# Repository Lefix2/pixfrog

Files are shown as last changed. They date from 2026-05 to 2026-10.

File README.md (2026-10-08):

# pixfrog

> High-performance ArtNet / sACN → LED driver for ESP32-P4. 8 channels × 2 lines (DATA + CLOCK), supporting 1-wire protocols (WS2815, WS2812B, SK6812…), clocked protocols (APA102, SK9822, LPD8806). DMX512 output lives in the DMX node firmware (a separate project forked from this one).

## Features

- ESP32-P4 dual-core RISC-V at 360 MHz, 32 MB octal PSRAM
- 10/100M Ethernet via external PHY (IP101GRI); DHCP or static IP, and without a DHCP server a configurable fallback: link-local 169.254.x.x (default) or Art-Net 2.x.x.x/8 from the MAC
- 8 parallel LED channels on a 16-bit bus — **PARLIO TX loop DMA** (default) or legacy LCD_CAM backend
- **ArtNet 4** receiver: ArtDmx/ArtPoll/ArtSync, remote config via ArtAddress + ArtIpProg, scene triggers via ArtTrigger, ArtTimeCode sync (up to 48 universes)
- **sACN (E1.31)** receiver (opt-in): multicast joins per configured universe, per-universe priority, stream-terminate handling
- **2-source merge** (HTP/LTP) when ArtNet and sACN feed the same universe
- **FSEQ player**: `.fseq` sequences (xLights/FPP, zstd-compressed) from microSD with hot-plug, uploaded over the web UI, played once, in a loop or as a **playlist** (per-file repeats, loop, autostart at boot), free-running or slaved to ArtTimeCode / **FPP MultiSync**
- **Effect bank and standalone scenes**: up to 31 reusable effects — 11 generators (solid + strobe, chase, rainbow, blobs, gradient, fade, twinkle, fire, scanner, wave, stripes), up to 4 colours each, a **dimmer phaser** (sine, cosine, ramps, triangle, PWM, bump; rate, phase spread, width, floor), a dimmer invert and pixel-level **Block / Groups / Wings** — and up to 30 scenes (create / rename / reorder / delete), each a memory of parts: "this effect on these outputs"; playable at boot, from the desk (ArtTrigger), or any UI
- **Per-line tuning**: gamma, white balance, grouping, invert, up to 8 dead-pixel gaps anywhere on the line (sacrificial pixel, repeater chip) and up to 32 fixtures (bars, tubes) that scenes can play per fixture, chained or mirrored; any refresh rate 20–120 Hz with a non-destructive pixel budget
- **Show control**: grand master, blackout and strobe per output group; scene **zones** (several scenes at once on different outputs) with **crossfades**; a composable **DMX control universe** (master 16-bit, blackout, strobe, scene, effect of the bank, speed, param, generator, colours, phaser, Block / Groups / Wings, fade, FSEQ) editable from the web, TFT or UART, with an exportable **OFL fixture profile** for the desk; up to 8 composable **fixture DMX profiles** (dimmer, colours, shutter, effect of the bank, speed, phaser, Block / Groups / Wings — presets from 3 to 16 channels), each with its OFL export; ArtTrigger KeyMacro blackout
- **Pixels, fixtures, or both** per output — two switches, each on its own address range: **pixel mapping** (every LED its DMX channels) and **fixture control**, each fixture driven like a conventional luminaire through its DMX profile (for example R, G, B, effect, speed, shutter) — a handful of channels per fixture instead of 3–4 per pixel. Both at once: a media server sends the pixels, the desk dims, shutters or replaces them with an effect of the bank, fixture by fixture. Auto-patch lays out the pixels, then the fixtures, then the control universe; the web shows the patch sheet
- **Signal-loss failsafe** per channel: hold / blackout / solid colour / scene after a configurable timeout
- **Per-channel gamma + white balance**, baked into encode-time LUTs (validated bit-exact on a logic analyzer)
- Local UI: **NV3007 428×142 colour bar TFT** (SPI, 2.79") with a live status dashboard (per-channel activity, link/services state) and natively rasterised anti-aliased fonts; Adafruit seesaw rotary encoder (4-wire I2C, time-polled); pixel-count live preview and strip-identify blink for commissioning. Two other panels are supported as build-time alternates — see [Display backend](#display-backend)
- **Web UI** (opt-in, port 80): full configuration SPA + REST API, live status and per-output pixel preview pushed over a WebSocket (`/api/status` polling as fallback), **OTA firmware update** (A/B slots with boot-failure rollback), config **backup/restore** as JSON, crash **coredump download**, mDNS while enabled (`pixfrog-xxxx.local` per box; `pixfrog.local` opens the box; with several, tabs at the top switch between an overview of every box and each box's own UI), optional HTTP Basic auth on every mutation (no TLS: the password crosses the network in clear)
- **UART control console**: every config field, telemetry, DMX injection, buffer readback (`tools/uartctl.sh`)
- Both UIs are laid out by job, in the order a rig is built — each screen only refers to what sits above it: the **dashboard**, then **Rig** (outputs and their fixtures, groups), **Looks** (effects, scenes), **DMX** (the three blocks of the patch sheet — control universe, profiles and fixture patch, pixel patch — and auto-patch last), **Playback** (sequences, automations) and **Settings** (network with the DMX reception — sACN, FPP, merge —, system, maintenance with the telemetry and logs). The device menu keeps its live Show page first.
- All configuration **persisted** in NVS with forward migration; network surfaces beyond ArtNet are **strictly opt-in** (no socket while disabled)

## Target hardware

The default board is the **Waveshare ESP32-P4 Module DEV-KIT**.
Pinout, schematic, datasheet, and PHY wiring are documented by Waveshare:

→ <https://docs.waveshare.com/ESP32-P4-Module-DEV-KIT/Resources-And-Documents>

Any other ESP32-P4 board with octal PSRAM and an MII/RMII PHY works; just clone `boards/esp32_p4_devkit.h` and adjust the GPIO map.

## Build & flash

ESP-IDF v5.5+ with ESP32-P4 support. `sdkconfig.defaults` already pins the
target, so no `set-target` is needed. Both `led_output` backends (PARLIO TX
default, legacy LCD_CAM RGB panel) need drivers that only ship from v5.5.

```bash
idf.py build                              # default: NV3007 bar panel
idf.py -p /dev/ttyACM0 flash              # write it to the board
idf.py -p /dev/ttyACM0 monitor            # boot log (Ctrl-] to leave)
idf.py menuconfig                         # optional — sdkconfig.defaults is sane
```

Without a local IDF, build and flash in the official container:

```bash
docker run --rm -v "$PWD":/project -w /project -u "$(id -u):$(id -g)" -e HOME=/tmp \
    espressif/idf:v5.5 idf.py build
docker run --rm --device /dev/ttyACM0 -v "$PWD":/project -w /project \
    espressif/idf:v5.5 idf.py -p /dev/ttyACM0 flash
```

> `sdkconfig` is generated and git-ignored. It is only seeded from
> `sdkconfig.defaults` **when it does not exist**, so after changing the defaults
> or switching variant, `rm -f sdkconfig` first — otherwise the old selection
> silently survives.

### Display backend

The default is the **NV3007 428×142 bar panel** the 1U rack ships with — a plain
`idf.py build` targets it, and the boot log confirms with
`TFT: NV3007 428x142 ready (landscape)`.

Two alternates are supported for other builds of the hardware. Each needs its own
build directory and sdkconfig, or the overlay is silently ignored:

| Panel | Overlay | Build |
|---|---|---|
| **NV3007** 428×142 SPI bar (2.79") | *(default)* | `idf.py build` |
| ST7789V / ILI9341 320×240 SPI | `sdkconfig.ci.st7789` | `idf.py -B build.st7789 -D SDKCONFIG=build.st7789/sdkconfig -D SDKCONFIG_DEFAULTS="sdkconfig.defaults;sdkconfig.ci.st7789" build` |
| SSD1306 128×64 I²C OLED | `sdkconfig.ci.oled` | `idf.py -B build.oled -D SDKCONFIG=build.oled/sdkconfig -D SDKCONFIG_DEFAULTS="sdkconfig.defaults;sdkconfig.ci.oled" build` |

Flash a variant from its own directory, e.g. `idf.py -B build.oled -p /dev/ttyACM0 flash`.
`PIXFROG_NV3007_ROT180` flips the bar panel; it is **on by default** (the panel is
mounted upside down in the 1U rack).

TFT SPI GPIOs live in `boards/esp32_p4_devkit.h` — CLK=0, MOSI=6, CS=20, DC=21,
RST=27 on the shield's J13 header, backlight on GPIO 36, SPI2 at 20 MHz. See
[docs/HARDWARE.md §5](docs/HARDWARE.md).

## Host unit tests

Seven pure-C++ test suites that run anywhere a C++17 compiler is installed (no IDF required):

```bash
# LED encoders + timings + encode throughput
cd components/led_protocols/test && cmake -B build && cmake --build build && ./build/test_led_protocols

# DMX manager logic (sizing, capacity, multi-universe decoder)
cd components/dmx_manager/test  && cmake -B build && cmake --build build && ./build/test_dmx_logic

# ArtNet parser (header, ArtDmx/Nzs/Address/IpProg, filter, replies)
cd components/artnet/test       && cmake -B build && cmake --build build && ./build/test_artnet_parser

# sACN parser (root/framing/DMP, sync, per-universe priority gate)
cd components/sacn/test         && cmake -B build && cmake --build build && ./build/test_sacn_parser

# config store (struct layout, NVS forward migration)
cd components/config_store/test && cmake -B build && cmake --build build && ./build/test_config_store

# FSEQ parser (header, sparse ranges, zstd frames)
cd components/fseq_player/test  && cmake -B build && cmake --build build && ./build/test_fseq_parser

# FPP MultiSync parser
cd components/fpp_sync/test     && cmake -B build && cmake --build build && ./build/test_fpp_sync_parser
```

There is also an SDL2 **UI emulator** (`tools/emulator`) that compiles the real
menu FSM for the host and drives it headlessly (`tools/emulator/smoke.sh`), and
a replayable **hardware regression suite** (`tools/hw_validate`) that proves
every feature on the real board after a flash.

## CI

`.github/workflows/ci.yml` runs on pushes to `main` and on pull requests
targeting `main`:

- the seven host suites above
- the SDL2 emulator build + headless menu-FSM smoke test
- `idf.py build` for `esp32p4` × **three display variants** (nv3007 default, st7789, oled) in the `espressif/idf:v5.5` container
- `clang-format --dry-run` against `.clang-format` on every tracked C/C++ file

`./tools/ci-local.sh` replays all of it locally and must be green before any push.

## Releases & browser flashing

Firmware and the website ship on independent cadences:

- `.github/workflows/release.yml` runs on every `v*` tag (e.g. `git tag v0.1.0
  && git push origin v0.1.0`): it builds the firmware and publishes a GitHub
  Release with `pixfrog-merged.bin` (flash at `0x0`) plus the individual
  bootloader / partition-table / app parts.
- `.github/workflows/pages.yml` runs on every push to `main` that touches the
  site (`.github/pages/**`, `docs/**`): it deploys the
  [esp-web-tools](https://esphome.github.io/esp-web-tools/) flasher and docs to
  GitHub Pages so the board can be flashed from desktop Chrome/Edge over USB —
  no toolchain required.

The flasher's `manifest.json` pins the **latest** Release asset
(`releases/latest/download/pixfrog-merged.bin`), so the site always serves the
newest firmware without a redeploy — a copy or CSS edit goes live on a plain
push to `main`, with no firmware version bump.

One-time setup: enable **Settings → Pages → Source: GitHub Actions** (the
workflow also attempts to enable it automatically).

## Documentation

Rendered online (with the browser flasher) at **<https://lefix2.github.io/pixfrog/>**:

- [docs/ARCHITECTURE.md](docs/ARCHITECTURE.md) — task topology, frame lifecycle, memory budget
- [docs/HARDWARE.md](docs/HARDWARE.md) — pinout, PHY, level shifters, encoder + display wiring
- [docs/PROTOCOLS.md](docs/PROTOCOLS.md) — per-protocol timings, PCLK formula, DMA encoding
- [docs/SHOW_CONTROL.md](docs/SHOW_CONTROL.md) — grand master / blackout / strobe, scene zones and crossfades, the DMX control universe and its fixture profile
- [AGENT.md](AGENT.md) — conventions, module map, hard rules (humans and agents)
- [TODO.md](TODO.md) — the living roadmap; features land only from this list

## Hardware companion

Two products live under `hardware/`, each with a board and a mechanical design.

**pixfrog_rack** — the controller end:

- *board* — **[pixfrog shield](hardware/pixfrog_shield/README.md)**: KiCad project
  + JLCPCB production files. 2× 74HCT245 re-drive the 16 bus lines at 5 V,
  DIP-selectable series termination, one TVS clamp per output, 8× JST-XH to the
  panel connectors.
- *meca* — **[1U enclosure](hardware/pixfrog_rack/README.md)**: Fusion 360 design
  of the chassis, front-panel UI holder, devkit + shield stack, XLR outputs and
  5 V supply.

**pixfrog_satellite** — the far end of a long run:

- *board* — **[satellite](hardware/pixfrog_satellite/README.md)**: Schmitt buffer
  re-squares one channel, local regulator injects strip power.
- *meca* — **WIP**, no enclosure design yet.

Every channel leaves on an XLR: **1 = GND, 2 = DATA+ (DATA), 3 = DATA− (CLOCK),
4 = VCC** on the XLR4 variant — DMX-compatible by design, see
[docs/HARDWARE.md §8](docs/HARDWARE.md).

## Status

Validated on silicon (Waveshare ESP32-P4 Module DEV-KIT): WS2815 NRZ timing,
gamma LUTs and frame content verified bit-exact on a Saleae logic analyzer;
ArtNet, sACN (unicast), OTA, auth, failsafe, scenes, backup/restore and FSEQ
playback (upload, seek, ArtTimeCode, FPP MultiSync) exercised end-to-end on
the board — captured as the replayable suite in `tools/hw_validate`.
Remaining field items live in [TODO.md](TODO.md).

## License

pixfrog is released under the [MIT License](LICENSE) — © 2026 Lefix2.

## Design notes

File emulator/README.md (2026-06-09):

# pixfrog UI emulator

Runs the device's **real** UI code (`menu.cpp`, `canvas_tft.cpp`, `splash.cpp`,
`font_5x8.cpp`) on a PC against an SDL2 framebuffer instead of the ST7789 TFT.
Lets you test the interface before flashing, and gives an AI agent a programmatic
way to drive and observe the UI.

## How it works

The UI only touches hardware through one function — `tft_draw_bitmap()`. The
emulator reimplements that (`src/tft_sdl.cpp`) over an in-RAM 320×240 RGB565
framebuffer, replaces the I2C rotary encoder with a host event queue
(`src/encoder_host.cpp`), and stubs the neighbour components the menu reads
(`config_store`, `dmx_manager`, `lcd_cam_output`) with in-RAM versions that
mirror the device defaults. Everything else is the device's own source,
compiled with `-DCONFIG_PIXFROG_DISPLAY_TFT`.

The only change to shared device code is `det::menu_debug_state()` in `menu.cpp`,
guarded by `#ifdef PIXFROG_EMULATOR` (invisible to the firmware build).

## Build & run

```sh
sudo apt install libsdl2-dev
cd emulator && cmake -B build && cmake --build build

./build/pixfrog_emu               # interactive window (960×720, 3× zoom)
./build/pixfrog_emu --headless    # no window, piloted via stdin (agent/CI)
```

### Keyboard (interactive)

| Key | Encoder event |
|---|---|
| ↑ / ← / wheel-up | RotateLeft  (cursor up) |
| ↓ / → / wheel-down | RotateRight (cursor down) |
| Enter / Space | Click |

## Agent / stdin protocol

One command per line on stdin; replies on stdout. Headless skips the splash and
starts at HOME for deterministic runs.

| Command | Effect |
|---|---|
| `left` / `right` | rotate the encoder |
| `click` | press the encoder |
| `shot <path>` | save the 320×240 framebuffer as BMP → `ok shot …`  |
| `state` | print `{"screen":..,"cursor":..,"channel":..}` |
| `set ip a.b.c.d` | set the displayed IP (HOME) |
| `set link up/down` | set link state (HOME) |
| `set fps <n>` | inject a fake FPS counter (HOME) |
| `set active <ch>`  | mark channel `ch` (0–7) active (HOME dot) |
| `quit` | exit |

### Example

```sh
printf 'click\nright\nright\nclick\nshot /tmp/chan.bmp\nstate\nquit\n' \
  | ./build/pixfrog_emu --headless
# → ok shot /tmp/chan.bmp
#   {"screen":"ChannelMenu","cursor":0,"channel":0}
```

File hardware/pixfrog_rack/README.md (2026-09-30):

# pixfrog rack — 1U enclosure

Fusion 360 design for the 1U rack that houses the controller: the
ESP32-P4 Module DEV-KIT plus the [signal shield](../pixfrog_shield/README.md),
the front-panel UI, and the mains-to-5 V supply.

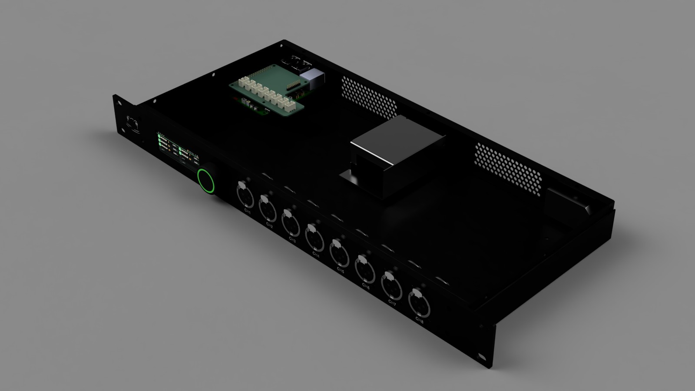
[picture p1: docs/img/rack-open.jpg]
pixfrog rack, open


`pixfrog_rack.f3z` is a Fusion archive (`.f3z`) — the assembly and every linked
component in one file. Open it with **File → Open** in Fusion 360; it unpacks
into a project. Exported at design version 40.

## What's in the assembly

| Component | Role |
|---|---|
| `rack_1U_200_pixfrog` | The 1U chassis itself, 200 mm deep |
| `assembly` | Top-level assembly holding everything below |
| `ESP32-P4-Module-DEV-KIT_20250427` | Waveshare devkit, as the manufacturer's model |
| `shield_v1` | The LED bus shield that plugs onto the devkit's J1 |
| `UI_holder` | Front-panel bracket for the display and encoder |
| `écran_tft_2.79` | NV3007 2.79" bar panel (428×142) |
| `adafruit_seesaw` | Rotary encoder breakout |
| `knob` | Encoder knob |
| `XLR Connector PCB Mount 3 pole Female, NC3FD-V` | Neutrik XLR, DMX-style output |
| `powerplug` | Mains inlet |
| `S-15-5 power` | 5 V / 15 W enclosed PSU |
| `captive_CFBSOAM3-6`, `captive_CFBSOAM3-10` | Captive panel screws, M3 |

## Front-panel outputs

The eight channels reach the front panel on XLR connectors, wired from the
shield's JST-XH outputs. The pin order is the project-wide convention
([`docs/HARDWARE.md`](../../docs/HARDWARE.md) §8):

| Pin | Signal | Carries |
|----:|---|---|
| 1 | GND | signal + power return |
| 2 | DATA+ | DATA (NRZ and clocked strips); DATA+ under the DMX node firmware |
| 3 | DATA− | CLOCK (clocked strips), unused on WS281x; DATA− under the DMX node firmware |
| 4 | VCC | strip supply — XLR4 shells only |

Pins 1-3 match the DMX512 standard pinout, so a plain 3-pin DMX cable carries a
pixfrog channel, and the DMX node firmware drives a fixture directly. The XLR4 shell
adds strip power on pin 4; it cannot mate with a 3-pin one, which is what keeps
powered runs and signal-only runs apart.

The pin assignments the UI and shield depend on are in
[`boards/esp32_p4_devkit.h`](../../boards/esp32_p4_devkit.h) — the single source
of truth. Panel geometry for the display is in
[`docs/HARDWARE.md`](../../docs/HARDWARE.md) §5.

## Note on the file

A `.f3z` is an opaque binary (~27 MB), and git would otherwise store a fresh
copy of it per revision — no delta applies to a compressed archive. `*.f3z` is
therefore tracked with **Git LFS** (see `.gitattributes` at the repo root): the
commit holds a ~130-byte pointer and the payload lives in LFS storage.

You need `git lfs` installed to get the real file. Without it a clone silently
yields the pointer text instead, and Fusion will simply report a corrupt
archive:

```bash
git lfs install     # once per machine
git lfs pull        # if you cloned before installing it
```

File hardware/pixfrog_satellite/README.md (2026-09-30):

# pixfrog satellite — LED signal repeater + power injection

The **board** half of pixfrog_satellite; its mechanical design (enclosure) is
**WIP** — the board mounts bare for now, H1/H2 tying its GND to the chassis or
heatsink that carries it.

KiCad 10 project for the remote node that sits at the **far end of a long LED
cable run**. The controller (or `pixfrog_shield`) sends one channel's two signal
lines down the cable; over distance the edges degrade and the strip voltage
sags. The satellite **re-squares the signal** with a Schmitt-trigger buffer and
**injects local strip power**, so the LEDs see clean data and full voltage
regardless of run length.

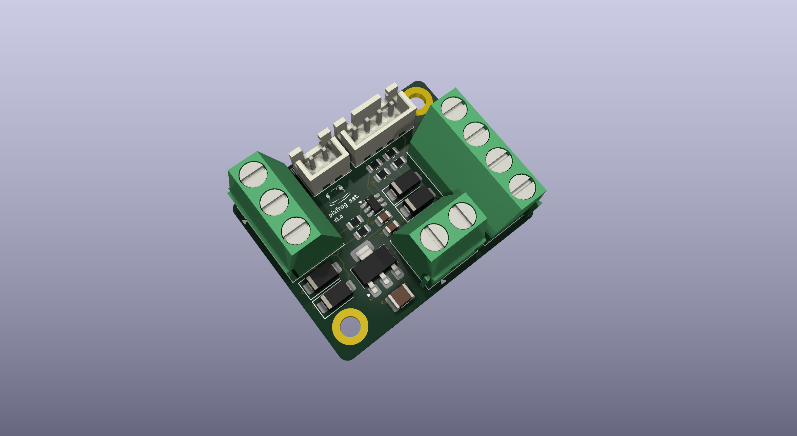
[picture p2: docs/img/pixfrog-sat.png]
pixfrog satellite


It repeats **one pixfrog channel** = its two bus lines (`Data1`, `Data2`). What
they carry follows the protocol set on the controller:

- **WS281x (NRZ)** — `Data1` = DATA (`Data2` unused),
- **clocked (APA102 / SK9822 / LPD8806)** — `Data1` = DATA, `Data2` = CLOCK,
- **DMX512** (DMX node firmware) — `Data1`/`Data2` = the differential pair.

Two voltage builds exist — **12 V** (WS2815-class) and **24 V** — chosen to match
the strip supply on `VCC`; the on-board LDO derives 5 V for the buffer from either.

## What it does

| Block | Parts | Role |
|---|---|---|
| Signal repeater | U1 — 74LVC2G17 (SC-74-6) | Dual non-inverting **Schmitt-trigger** buffer, powered at +5 V. Re-squares both lines (`Data1`, `Data2`) so the strip is driven by fresh 5 V-logic edges, not the degraded cable signal |
| Input series + clamp | R1, R2 (33 Ω) · D1, D2 (TVS) | 33 Ω in series into each buffer input; one 5 V bidirectional TVS per input line to GND |
| Output series, impedance select | R5, R6 (249 Ω) · R3, R4 (39 Ω) behind J4 | 249 Ω permanently in line on each output (WS281x-style). Fitting a jumper/switch on J4 (1‑2 and/or 3‑4) parallels 39 Ω → ≈34 Ω for low-impedance drive of long lines — same trick as the shield's SW1 |
| Output clamp | D3, D4 — TVS | One 5 V bidirectional TVS per output line to GND |
| Local 5 V | U2 — LD1117S50 (SOT-223) · C1 100 n, C2 10 µF (out) · C3 10 µF (in) | Linear 5 V from `VCC` (12 V or 24 V) — the logic rail for the buffer (`+5V` net, internal only) |
| Power pass-through / fan-out | J1 in → J2 + J5 | The strip supply (`VCC`) enters on J1 and is passed straight to the strip output (J2) and the J5 fan-out, GND common throughout |
| Mounting | H1, H2 — GND pads | Tie the board GND to the chassis/heatsink |

## Connectors

| Ref | Type | Pins | Use |
|---|---|---|---|
| J1 | 2-pin screw (Phoenix MKDS 5.08) | `VCC`, `GND` | Strip power **in** (12 V or 24 V per build) |
| J3 | 3-pin screw | `GND`, `Data1_in`, `Data2_in` | Signal **in** from the controller / shield channel |
| J2 | 4-pin screw | `VCC`, `Data1_out`, `Data2_out`, `GND` | **Out** to the LED strip — regenerated data + injected power |
| J5 | 2-pin JST-XH (`fan_out`) | `VCC`, `GND` | Power fan-out — chain to the strip's other end or a downstream node |
| J4 | 4-pin JST-XH | pre-/post-249 Ω taps | Optional impedance-select header (see table above); leave open for 249 Ω only |

Screw terminals, not panel connectors — the XLR lives at the cable end. The
incoming cable follows the project-wide pin order
([`docs/HARDWARE.md`](../../docs/HARDWARE.md) §8): **1 = GND, 2 = DATA+ (DATA),
3 = DATA− (CLOCK), 4 = VCC**, so XLR pins 1/2/3 land on J3's `GND` /
`Data1_in` / `Data2_in`. An XLR4 run brings strip power on pin 4 to J1 `VCC`;
with an XLR3 run the strip supply is local and J1 is fed from the node's own
PSU.

## Signal + power flow (per line)

```
Data_in (J3) ─[TVS]─ 33Ω ─► 74LVC2G17 (@ +5V) ─► 249Ω ─[TVS]─ Data_out (J2)
                                                    │
                                              J4 ── 39Ω  (jumper ⇒ ≈34Ω)

VCC (J1, 12/24V) ─┬─► LD1117S50 ─► +5V (buffer)
                  └─► J2 (strip) + J5 (fan-out)
```

## Production

`production/` is JLCPCB-ready, generated by the KiCad Fabrication Toolkit
(options in `fabrication-toolkit-options.json`):

- `pixfrog_satellite.zip` — gerbers + drill
- `bom.csv` / `positions.csv` — SMT assembly with LCSC part numbers
- `netlist.ipc`, `designators.csv`

## Not committed

Working artifacts stay out of the repo: `.history/`, KiCad backups, the
`3d/` model sources and the STEP export (regenerate from the PCB via
File → Export → STEP), and the render source images (the render itself
lives in `docs/img/pixfrog-sat.png`).

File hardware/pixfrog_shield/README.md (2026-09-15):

# pixfrog shield — LED bus signal conditioning

The **board** half of pixfrog_rack; the *meca* half is the
[1U enclosure](../pixfrog_rack/README.md) it stacks into.

KiCad 10 project for the signal-adaptation shield that plugs onto the
ESP32-P4 Module DEV-KIT's 2×20 header (J1). It closes the gap identified in
the TODO ("output buffers"): the devkit drives the LED bus straight from
3.3 V GPIOs, which is marginal for 12 V strips (WS2815) over real cable runs
and leaves the SoC exposed to field wiring.

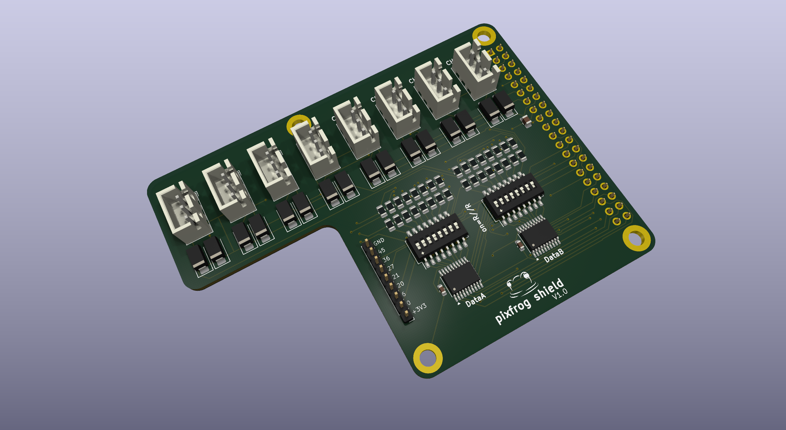
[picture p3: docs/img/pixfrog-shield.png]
pixfrog shield


## What it does

| Block | Parts | Role |
|---|---|---|
| Level shift | U1, U2 — 2× 74HCT245 (TSSOP-20) | TTL-threshold inputs driven cleanly by 3.3 V; outputs re-drive all 16 bus lines (8× DATA via U1, 8× CLOCK via U2) at 5 V — double the noise margin at the strip |
| Series termination, DATA | R1–R8 (249 Ω) + R9–R16 (39 Ω) behind SW1 | 249 Ω permanently in line (WS281x-style input resistor); closing the channel's DIP on SW1 parallels 39 Ω → ≈34 Ω for low-impedance drive of long lines ("33Ω/249Ω" on the silkscreen) |
| Series termination, CLOCK | R17–R24 (33 Ω) + R25–R32 (39 Ω) behind SW2 | 33 Ω base for clocked strips (APA102/SK9822/LPD8806); SW2 parallels 39 Ω → ≈18 Ω |
| Transient clamp | D1–D16 — 16× 5 V TVS (SMA) | One clamp to GND per output; a zap on the field wiring sacrifices a €0.10 diode, not the P4 |
| Outputs | J2–J9 — 8× JST-XH 3 pins | Per channel: 1 = DATA, 2 = CLOCK, 3 = GND (strip power stays on the strip PSU; signal ground must travel with the data pair) |
| Aux breakout | J13 — 1×9, 2 mm | 3V3, spare GPIOs 0/6/20/21/27/36/45, GND |

The channel→GPIO mapping mirrors `boards/esp32_p4_devkit.h` exactly
(CH1 DATA=GPIO2/CLK=GPIO3 … CH8 DATA=GPIO53/CLK=GPIO54).

J2–J9 are internal: the loom takes each one to a panel XLR, whose pin order is
**not** the JST's ([`docs/HARDWARE.md`](../../docs/HARDWARE.md) §8) —
JST 1 (DATA) → XLR 2, JST 2 (CLOCK) → XLR 3, JST 3 (GND) → XLR 1. Pin 4 of an
XLR4 panel carries strip VCC and comes from the injection point, never from the
shield.

The SPI TFT display is wired to J13: **CLK=GPIO0, MOSI=GPIO6, CS=GPIO20,
DC=GPIO21, RST=GPIO27** (+3V3/GND). GPIO36 (boot strapping, must read HIGH at
reset) and GPIO45 (VDD_IO_5/LDO-VO4 domain) stay free for other use.

## Production

`production/` is JLCPCB-ready, generated by the KiCad Fabrication Toolkit
(options in `fabrication-toolkit-options.json`):

- `PixFrog_Shield.zip` — gerbers + drill
- `bom.csv` / `positions.csv` — SMT assembly with LCSC part numbers
- `netlist.ipc`, `designators.csv`

## Not committed

Working artifacts stay out of the repo: `.history/`, KiCad backups, the
`3d/` model sources and the STEP export (regenerate from the PCB via
File → Export → STEP), and the render source images (the render itself
lives in `docs/img/pixfrog-shield.png`).

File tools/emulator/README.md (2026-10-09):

# pixfrog UI emulator

Runs the device's **real** UI code (`menu.cpp`, `canvas_tft.cpp`, `splash.cpp`,
`splash_anim.cpp`, `font_data.cpp`) on a PC against an SDL2 framebuffer instead
of the ST7789 TFT.
Lets you test the interface before flashing, and gives an AI agent a programmatic
way to drive and observe the UI.

## How it works

The UI only touches hardware through one function — `tft_draw_bitmap()`. The
emulator reimplements that (`src/tft_sdl.cpp`) over an in-RAM RGB565
framebuffer, replaces the I2C rotary encoder with a host event queue
(`src/encoder_host.cpp`), and stubs the neighbour components the menu reads
(`config_store`, `dmx_manager`, `led_output`) with in-RAM versions that
mirror the device defaults. Everything else is the device's own source,
compiled with the same display macros as the firmware.

Two panel layouts exist, mirroring the firmware's TFT panel choice:
**NV3007 428×142** (the default build) and **ST7789 320×240**
(`cmake -B build.st7789 -DPIXFROG_EMU_PANEL=st7789`). CI builds and
smoke-tests both.

The only change to shared device code is `det::menu_debug_state()` in `menu.cpp`,
guarded by `#ifdef PIXFROG_EMULATOR` (invisible to the firmware build).

## Build & run

```sh
sudo apt install libsdl2-dev
cd tools/emulator && cmake -B build && cmake --build build

./build/pixfrog_emu               # interactive window (960×720, 3× zoom)
./build/pixfrog_emu --headless    # no window, piloted via stdin (agent/CI)
```

### Keyboard (interactive)

| Key | Encoder event |
|---|---|
| ↑ / ← / wheel-up | RotateLeft  (cursor up) |
| ↓ / → / wheel-down | RotateRight (cursor down) |
| Enter / Space | Click |

## Agent / stdin protocol

One command per line on stdin; replies on stdout. Headless skips the splash and
starts at HOME for deterministic runs.

| Command | Effect |
|---|---|
| `left` / `right` | rotate the encoder |
| `click` | press the encoder |
| `shot <path>` | save the 320×240 framebuffer as BMP → `ok shot …`  |
| `splash <ms> [p]`  | render the boot splash at t=`ms` and shot it |
| `state` | print `{"screen":..,"cursor":..,"channel":..}` |
| `set ip a.b.c.d` | set the displayed IP (HOME) |
| `set net <state>`  | set the network icon: `disconnected`/`acquiring`/`connected`/`error` (HOME) |
| `set fps <n>` | inject a fake FPS counter (HOME) |
| `set cpu <a> <b>`  | inject fake core 0 / core 1 loads in % (HOME) |
| `set pkts <n>` | inject a fake ArtNet RX packet counter (HOME) |
| `set active <ch>`  | mark channel `ch` (0–7) active (HOME dot) |
| `set chan <i> <proto> <uni> <pix>` | seed channel `i` (protocol enum value) |
| `set gaps <i> [<pos0>:<len> …]` | replace channel `i`'s dead-pixel gaps |
| `set patch <i> <pixel_map> <fixture_ctl> [<uni> [<dmx>]]` | what drives channel `i` from the network (0/1 each), and its fixtures' address |
| `set fixtures <i> [<pos0>:<len>[:r][:p<n>] …]` | replace channel `i`'s fixtures (`r` = mounted the other way round, `p<n>` = DMX profile n) |
| `set scenes <n>` | cut the scene list down to n |
| `dump chan <i>` / `dump scene <i>` | one JSON line of what the menu stored: a channel's pixels, layout and fixtures; a scene's name, group and parts |
| `set sd <n>` | fake a microSD with n `.fseq` files (0 = none) |
| `quit` | exit |

### Menu crawler and golden screenshots

`crawl.py` seeds rich state, snaps a few static screens and compares them pixel
for pixel with `golden/<panel>/*.png`, then walks every menu node, activates
every row (commits value edits, cancels the others) and fails if a node or an
editor kind was never reached. CI runs it on both panels; `tools/coverage.py`
runs it too (it brings `menu.cpp` above 80 %).

```sh
python3 tools/emulator/crawl.py build/pixfrog_emu
python3 tools/emulator/crawl.py build.st7789/pixfrog_emu --panel st7789
python3 tools/emulator/crawl.py build/pixfrog_emu --update-golden  # intended UI change
```

A mismatch leaves the new render in the temp dir (`golden-<panel>-<name>.png`).
Needs Pillow (`pip install pillow`).

### Example

```sh
printf 'click\nright\nright\nclick\nshot /tmp/chan.bmp\nstate\nquit\n' \
  | ./build/pixfrog_emu --headless
# → ok shot /tmp/chan.bmp
#   {"screen":"ChannelMenu","cursor":0,"channel":0}
```

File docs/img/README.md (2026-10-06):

# Images & diagrams

All figures referenced by the docs and the site live here. They render on
GitHub (in the `docs/*.md` files) and on the published site
(`https://lefix2.github.io/pixfrog/`), where `docs/img/` is served as `/img/`.

The diagrams are **hand-authored SVG** (crisp, versionable, no licensing
issues); photos are JPG and the social cover is a PNG. The landing page and
docs viewer hide any image that fails to load, so adding/replacing one is safe.

| File (`docs/img/…`) | Kind | Shows | Used by |
|---|---|---|---|
| `architecture-overview.svg` | SVG  | System block diagram (ingest → pool → render → PARLIO TX → strips) | ARCHITECTURE §1 |
| `task-topology.svg` | SVG  | FreeRTOS tasks across the two cores, with priorities | ARCHITECTURE §3 |
| `frame-pipeline.svg` | SVG  | One frame's render stages, GDMA + network in parallel | ARCHITECTURE §4 |
| `clock-tree.svg` | SVG  | LCD_CAM clock tree + PCLK / bit / clock formulas | PROTOCOLS §3.1 |
| `nrz-encoding.png` | PNG  | 1-wire NRZ bit timing (T0H / T1H / TRESET) | PROTOCOLS §2 |
| `clocked-encoding.png` | PNG  | SPI-like clocked encoding (DATA on CLOCK edges) | PROTOCOLS §4.2 |
| `hardware-pinout.jpg` | JPG  | Waveshare DEV-KIT labelled header + interfaces | HARDWARE §2 |
| `level-shifter.svg` | SVG  | 3.3 V → 5 V buffering with a 74HCT245, series R + TVS clamp | HARDWARE §3 |
| `peripherals-wiring.svg` | SVG  | OLED + seesaw encoder on the shared I²C bus | HARDWARE §4 |
| `oled-ui.svg` | SVG  | SSD1306 home-screen mockup | HARDWARE §6 |
| `board-hero.jpg` | JPG  | Photo of the ESP32-P4 DEV-KIT | HARDWARE §1 |
| `ui-nv3007-home.png` | PNG  | NV3007 bar display home screen (emulator), `tools/screenshots` | Landing page §02 |
| `rack-closeup.jpg` | JPG  | 1U rack front panel — screen and rotary encoder | Landing hero |
| `rack-open.jpg` | JPG  | Rack with the lid off: daughterboard, supply, vent panels | Landing page §01 |
| `rack-full.jpg` | JPG  | Complete 1U rack, eight XLR outputs across the front | Landing page §01 |
| `web-dashboard[-fr].png` | PNG  | Web UI dashboard, EN / FR — `tools/screenshots` | Landing page §02 |
| `web-scenes[-fr].png` | PNG  | Web UI scene editor, EN / FR — `tools/screenshots` | Landing page §02 |
| `web-control.png` | PNG  | Web UI DMX control editor — `tools/screenshots` | SHOW_CONTROL |
| `web-effects.png` | PNG  | Web UI effect editor (phaser, Block / Groups / Wings) — `tools/screenshots` | SHOW_CONTROL |
| `web-profiles.png` | PNG  | Web UI DMX profiles editor — `tools/screenshots` | SHOW_CONTROL |
| `web-channel-control.png` | PNG  | Web UI output patch, an output driven by its pixels and its fixtures' profiles — `tools/screenshots` | PROTOCOLS §5.6 |
| `effects/effects-gallery.png` | PNG | The 11 generators, time → x, pixel → y — `tools/effects_gallery` | SHOW_CONTROL |
| `effects/layers-gallery.png` | PNG | Dimmer phaser waveforms, invert, Block / Groups / Wings — `tools/effects_gallery` | SHOW_CONTROL |
| `og-cover.png` | PNG  | Social / link-preview cover (rendered from `og-cover.svg`) | `og:image` |
| `logo.svg` | SVG  | Frog mark — nav brand + favicon | Site |
| `frog-anim.svg` | SVG  | Animated frog logo (self-contained CSS); baked into the splash | About page + `tools/splashgen` |

`*.svg` sources for the rasterised covers (`og-cover.svg`) are kept alongside
so they can be re-exported with `rsvg-convert`.

The UI captures and the effects sheet are generated, never edited by hand:
`tools/screenshots/shots.py` (the real web UI against `pixfrog_api_host --demo`
in headless Chromium, and the device screens from the emulator) and
`tools/effects_gallery/gallery.py` (the firmware's own effect renderer). Re-run
them after a UI or effect change and commit the result.

The landing hero is cropped with `object-fit: cover` at `object-position: 56% 50%`
under a left-to-right dark gradient, so it wants a wide frame with the subject
right of centre and room to go dark on the left. It ships as JPG (77 kB rather
than 450 kB as PNG): the render's smooth shading hides the compression, and it
sits under a heavy scrim anyway. The 3D renders and UI captures are exported at
2×; downscale to 1920 (hero) / 1600 (renders) / 1440 (UI) before committing.

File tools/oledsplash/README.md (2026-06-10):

# oledsplash

Bakes the **static OLED splash frog** (`components/ui/src/splash_oled.cpp`) — a
single small 1bpp frog logo, area-downsampled from the settled frame of the TFT
splash animation (`splash_anim.cpp`). One frame, so the OLED build doesn't pull
the full ~76 KB TFT strip. `splash.cpp` (OLED branch) blits it above the
"pixfrog" wordmark.

The asset is **generated**, not hand-edited. The frame data lives behind
`CONFIG_PIXFROG_DISPLAY_TFT` and `ui_internal.h` pulls an IDF header, so the
generator links against `splash_anim.cpp` with that define and a stubbed header:

```bash
mkdir -p /tmp/s/driver
printf 'typedef void* i2c_master_bus_handle_t;\ntypedef void* i2c_master_dev_handle_t;\n' \
    > /tmp/s/driver/i2c_master.h
cd tools/oledsplash
g++ -std=c++17 -DCONFIG_PIXFROG_DISPLAY_TFT -I/tmp/s -I../../components/ui/src \
    gen.cpp ../../components/ui/src/splash_anim.cpp -o gen
./gen [destW=64] [destH=45] > ../../components/ui/src/splash_oled.cpp
```

Output: `frog_oled_{w,h,data}()` over `kFrogOled` (1bpp MSB-first, stride
`(w+7)/8`). `splash_oled.cpp` is in `.clang-format-ignore`. To re-derive the frog
from the SVG instead, regenerate `splash_anim.cpp` via `tools/splashgen` first.

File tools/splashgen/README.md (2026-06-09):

# splashgen

Bakes the animated **Collecti'Frog logo**
[`docs/img/frog-anim.svg`](../../docs/img/frog-anim.svg) into the boot-splash
frame strip consumed by `components/ui/src/splash.cpp`. The same SVG is embedded
by the web About page (`.github/pages/about.html`), so the two never drift.

The logo is a static SVG (frog head + eye rings + pupils + 4 water bands)
animated purely by CSS: the creature rises out of the water, the bands pop in
and idle-bob, the pupils blink. We can't run CSS on the MCU, so this tool
replays that timeline at generation time — per frame it applies each group's
affine transform to the parsed bezier control points, rasterises (supersampled,
via vendored nanosvg), composites the water-clipped frog under the waves,
downsamples and thresholds to **1bpp**. The firmware then blits frame *t* with
`canvas_draw_mask` (saffron ink, dark-green backdrop).

The output `splash_anim.cpp` is **generated**, not hand-edited — it carries a
banner saying so. Regenerate it instead of touching it.

## Build & run

```bash
cd tools/splashgen && cmake -B build && cmake --build build
./build/splashgen ../../docs/img/frog-anim.svg \
    ../../components/ui/src/splash_anim.cpp        # [outW] [fps] [durMs] are tunable
```

Defaults bake **43 frames, 140×99, @12 fps** over a 3600 ms timeline (≈75 KB of
1bpp mask data). The tool extracts the first `<svg>…</svg>` from its input, so it
also accepts an HTML page that embeds the logo.

| arg | meaning |
|---|---|
| `outW`  | output frame width in px; height follows the window aspect |
| `fps` | playback rate baked into the strip (`splash_anim_frame_ms()`) |
| `durMs` | total animation length to sample (frame count = durMs / fps)  |

Quick visual check without writing the table: pass `preview` as the output path
to dump a late frame as terminal ASCII shading.

```bash
./build/splashgen ../../docs/img/frog-anim.svg preview
```

The scene window, water-clip line and supersample factor are `constexpr` at the
top of `splashgen.cpp`; the shape→group mapping in `classify()` assumes the SVG
element order (head 5, eye-rings 2, pupils 2×2, waves 4 = 15 shapes) and the tool
aborts if that count changes.

After regenerating, rebuild the emulator to preview the real splash:
`cd ../emulator && cmake --build build && ./build/pixfrog_emu` — or headless,
`echo "splash 2400 /tmp/s.bmp" | ./build/pixfrog_emu --headless`.

`nanosvg.h` / `nanosvgrast.h` are vendored here (zlib licence).

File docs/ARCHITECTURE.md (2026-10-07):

# pixfrog architecture

Reference for the software architecture of **pixfrog**, a high-performance 8-channel LED controller built on ESP32-P4 and driven by ArtNet over Ethernet.

> Normative document: every module respects what's described here, or amends this file before changing the design.

---

## 1. Overview

pixfrog is built around one principle: **decouple network ingest (bursty, jittery) from LED rendering (strict timing)** via multiple buffered stages (double-buffered universe and pixel banks, triple-buffered output frame). Each stage runs on a pinned core, shares only atomic pointers, and never allocates on the hot path.

pixfrog system overview

**Key idea**: frame N+1 is encoded into `frame_buf[back]` (PSRAM) while GDMA streams frame N out of `frame_buf[front]`. After `esp_cache_msync`, the swap is a pointer exchange: the default **PARLIO TX backend** stitches the new buffer onto the tail of its gapless loop so it takes over at the next frame boundary (the legacy LCD_CAM backend re-arms with `esp_lcd_panel_draw_bitmap`). No underrun risk because the encoder has no sub-frame deadline: it has the full DMA emission window of the current frame to produce the next one.

---

## 2. Build framework

**Native ESP-IDF v5.5+ (CMake + `idf.py`).**

1. **Stable ESP32-P4 support** in upstream IDF. PlatformIO historically lags new targets by months.
2. **Low-level parallel-bus access** — the default PARLIO TX driver (and the legacy LCD_CAM `esp_lcd` RGB panel) clock the 16-bit bus straight from PSRAM via GDMA, with no framework abstraction in the way.
3. **Granular `sdkconfig`** for PSRAM, FreeRTOS, lwIP, IRAM ISR placement.
4. **Reproducible CI** via the official `espressif/idf:vX.Y` docker images.

Layout follows IDF conventions: `main/`, `components/`, `sdkconfig.defaults`, root `CMakeLists.txt`.

---

## 3. FreeRTOS task topology

FreeRTOS task topology across the two cores

| Task | Core | Prio | Stack | Wake source | Role |
|---|:----:|:----:|:-----:|---|---|
| `lwip_tcpip_thread`  | 0 | 18 | 4 kB  | lwIP mailbox | IDF TCP/IP stack (provided) |
| `eth_rx_task` | 0 | 19 | 2 kB  | Ethernet IRQ | RMII → lwIP (provided) |
| `artnet_rx_task` | 0 | 10 | 4 kB  | blocking `lwip_recvfrom` | Parse packets (Dmx/Poll/Sync/Address/IpProg/Trigger), write `universe_pool[back]` |
| `sacn_rx_task` | 0 | 10 | 4 kB  | blocking `recvfrom` (1 s t/o) | **Opt-in.** E1.31 data + sync, multicast joins (5 s refresh), priority gate |
| `fpp_sync` | 0 | 9 | 4 kB  | blocking `recvfrom` | **Opt-in.** FPP MultiSync remote: master start/stop/seek of local FSEQ files |
| `fseq_play` | 0 | 5 | 8 kB  | `vTaskDelayUntil` (step_time) | Per-playback: read/decompress FSEQ frames, inject into `universe_pool[back]` |
| `sd_mon` | 0 | 2 | 4 kB  | 1 s tick | microSD hot-plug mount/unmount |
| `httpd` | 0 | 5 | 8 kB  | TCP accept | **Opt-in.** Web SPA + REST API + OTA + backup/restore + live status (esp_http_server); mDNS `pixfrog-<mac4>.local` while running |
| `web_push` | 0 | 3 | 4 kB  | 200 ms tick | **Opt-in** (web). `/api/ws` frames: 5 Hz output preview, 1 Hz status |
| `web_hub` | 0 | 2 | 4 kB  | 1 s tick, browse every 15 s | **Opt-in** (web). Sibling browse + election of the shared `pixfrog.local` alias |
| `compose_task` | 0 | 9 | 4 kB  | refresh timer + `ArtSync` | Frame N+1: apply remaps, swap universes, control universe, decode/generate every output's pixels, publish them |
| `render_task` | 1 | 20 | 4.5 kB | a composed frame | Frame N: encode the published pixels, kick DMA, FPS |
| `ui_task` | 0 | 4 | 4 kB  | 33 ms tick | Boot splash, **time-polled** seesaw encoder (no IRQ — 4-wire harness), render display, persist NVS |
| `idle_0` / `idle_1`  | 0/1  | 0 | 1 kB  | (FreeRTOS) | Power-save hooks |

> **Note**: no refill task. The full frame buffer lives in PSRAM and the DMA
> engine scans it autonomously. The default **PARLIO TX backend** runs in loop
> transmission: the mounted buffer repeats gaplessly and a frame swap is a
> single buffer remount at the next frame boundary. The legacy LCD_CAM backend
> (Kconfig choice, not CI-built) paces on its vsync ISR instead. Either way
> the encoder has no sub-frame deadline.

---

## 4. Frame lifecycle

A frame is the interval between two LED renders — `1/refresh_rate`, any integer rate from 20 to 120 Hz (50 ms … 8.33 ms; 16.67 ms at the default 60 Hz).

Frame lifecycle — render_task stages with GDMA and network in parallel

A frame is made in two stages on the two cores, a frame apart:
**`compose_task` (core 0) draws frame N+1 while `render_task` (core 1)
encodes frame N**. Drawing and encoding each get a core, so a frame costs
the longer of the two, not their sum. The pixel buffers are the hand-over:
compose draws into the back buffers and, once the encoder has released the
fronts (`g_fronts_free`), publishes every output at once
(`dmx::publish_pixels()` — the pixel-count ruler's emit length travels with
its frame) and signals `g_frame_ready`; render encodes from the fronts, then
frees them. Everything the drawing keeps from frame to frame (effect clocks,
look fades, the plays' snapshot, the control state) belongs to compose alone,
as it belonged to the single render task before. Compose runs just under the
receivers (priority 9 against 10), so a burst of universes is never held
back by drawing. The latency grows by at most one encode: compose publishes
as soon as the encoder is free.

When `compose_task` wakes (t = 0), it runs, in order:

1. Atomic swap `universe_front ↔ universe_back`.
2. `dmx::update_show_control()`: evaluate the DMX control universe (if
   enabled and heard within 3 s) from the bank just published — master,
   blackout, strobe and scene overrides follow the desk continuously; scene and
   FSEQ bands act when they change (FSEQ is posted to `fseq_player`, the render
   task never touches the SD card).
3. Per channel, fill `pixel_back_buffer(ch)` from the **first matching source**
   in a fixed priority chain (published together by `publish_pixels()` once
   the encoder is free):
   1. **Identify** — 2 Hz white blink (commissioning, auto-expires)
   2. **Pixel-count preview** — live ruler while the count is edited
   3. **The output's source** — each output plays its own scene or the live
      path ("zones": a scene claims the outputs of its parts, several run at
      once):
      - **Scene** — the effect its part sends to this output: a stateless
        parametric generator (11 generators, 1–4 colour palette,
        `dmx_logic.h` `fill_effect_run`) with the desk's overrides;
        overrides network until stopped
      - **Live path** — FSEQ, else **failsafe** (channel silent past the
        timeout: blackout / solid colour / scene; hold = decode the stale
        data), else **network decode** (DMX offset, multi-universe spanning)
      During a crossfade (`scene_fade_ms`, eased) the previous source renders
      into a 4 kB SRAM scratch buffer and is blended in.
   4. **Show control** — blackout / strobe gate, then the grand master
      (local × desk, 16-bit) scales the bytes. Identify and the ruler bypass it.
4. *(render_task, core 1, once the frame is published)* `output::render_frame()`: encode every channel into a drained back buffer in a single pass (`led::encode_frame` — pure stores, no pre-zeroing; **gamma/white-balance LUT**, color order, brightness, grouping and invert applied inline per pixel) **while previous frames are still emitting from the other FBs** (PARLIO keeps two buffers mounted in its DMA loop; the third is the one being encoded — see §4.4), `esp_cache_msync(…, DIR_C2M)` on the written region, then hand the buffer to the DMA engine (PARLIO loop remount, or draw_bitmap on the legacy LCD_CAM path). Encode (CPU) and emission (DMA) overlap; the frame rate is bounded by max of the two, not their sum.
5. *(compose_task)* `dmx::wait_for_sync_or_period(remaining)`: block until end-of-period **or** an ArtSync arrives.

In parallel on core 0 across the whole frame, `artnet_rx_task` drains UDP into `universe_pool[back]` (it preempts compose); an ArtSync calls `dmx::note_sync()`, which wakes `compose_task` early via the semaphore.

**What it costs, measured on the box** (`stats`, `/api/diag` → `render`, the
Diagnostics page, NERD STATS): the time step 3 takes for every output — the
effects, scenes, groups and fixtures drawn (`decode_us`, and the longest of
the last second; core 0) — next to the encode (core 1), and each core's load
over the last second (`cpu_load`: the share its idle task did not get, from
FreeRTOS run time stats on the esp_timer clock). Core 1 runs `render_task`
alone; core 0 compose, the receivers, the UI and FSEQ; the web server and
audio float. The idle
task's run time only moves when it is switched out, so each core's figure is
read from a task on that core (`render_task` for core 1, `compose_task` for
core 0). The console's `tasks` lists every task's share over half a second and
the least stack each ever had free.

Drawing longer than the period leaves compose no wait: it then sleeps one tick
anyway, so the UI, the console and the idle task (and its watchdog) still get
core 0 — the frame rate drops instead.

Measured on the bench (fixture control, 32 fixtures an output, a sine phaser
on each; ms = drawing on core 0 / encode on core 1):

| | plain | fire | 256 fixtures crossfading |
|---|---|---|---|
| 8 × 512 @ 60 Hz, one task (before) | 58 fps (4.1 + 12.2) | 48 fps (7.6 + 12.8) | 39 fps (12.5 + 12.6) |
| 8 × 512 @ 60 Hz, pipeline | 61 fps (4.1 / 12.4) | 60 fps (8.4 / 12.7) | 61 fps (14.0 / 12.8) |
| 8 × 1024 @ 30 Hz, pipeline | 30 fps (6.5 / 24.1) | 31 fps (14.6 / 24.9) | 31 fps (23.9 / 25.1) |

Drawing on core 0 runs ~10 % slower than it did alone on core 1: the two
cores share the PSRAM bus with the encoder's frame-buffer writes. A crossfade
of every fixture at 60 Hz puts core 0 near 90 %.

**Total wire-to-photon latency**: typically 2 frames (one frame of wait + one frame of emission). At 30 Hz that's ~66 ms; at 60 Hz, ~33 ms — well below human perception for lighting.

**Consistency guarantee**: an ArtDmx received mid-encode lands in frame N+1, never half-and-half.

---

## 5. Memory budget

### Internal SRAM (768 kB total, ~512 kB usable)

| Item | Size | Note |
|---|---:|---|
| FreeRTOS + lwIP + IDF drivers | ~120 kB | Measured on similar projects |
| All task stacks | ~30 kB | cf. §3 |
| General heap | ~330 kB | Ethernet init, NVS, OLED |

The scarce internal resource is **DMA-capable** RAM (~244 kB of the 284 kB
heap): the output's DMA lists take one block of it at every frame-length
change (~4 kB each for 8 × 512 pixels, two lists), and a live resize fails
when no block is large enough. `status` (`dma_free`, `dma_largest`) and
`/api/diag` show it. The EMAC's receive ring lives there too: 30 buffers of
640 B, one ArtDmx frame each, so a desk's burst of universes sent back to back
is absorbed (bench: 92 % of a 32-universe burst; half was lost with the
default 20 × 512 B).

`pixel_buf` holds a channel's decoded DMX pixels before they're encoded into the PSRAM FB. It is double-buffered per channel (atomic front/back swap): compose writes the back buffers, publishes them all once the encoder is done with the fronts, and the encoder reads stable fronts while the next frame is drawn. They live in PSRAM: a frame touches ~12 kB of them against the encoder's ~0.5 MB of frame buffer (the encode measured 0.3 ms slower), and in internal RAM they took the 64 kB the DMA lists need.

### Octal PSRAM (32 MB)

| Item | Size | Note |
|---|---:|---|
| `frame_buf[3]` (PSRAM) | 3 × 2.6 MB | triple-buffered (PARLIO) so encode overlaps the two FBs in the DMA loop; allocated once at the cap (1024 px × 32 bits × 40 samples) and never resized, so nothing on the render path allocates. Legacy LCD_CAM sizes 2 FBs to the longest configured channel instead. |
| `universe_pool[2][N]` | 2 × 48 kB  | 48 universes × 512 bytes × 2 buffers |
| `pixel_buf[8]` | 8 × 2 × 4 kB | per channel, double-buffered: 1024 px × 4 bytes RGBW worst case |
| Circular logs | 64 kB | Post-mortem debug |
| Application headroom | ~27 MB | Future sequencer / FX engine / ... |

**GDMA from PSRAM** is native on ESP32-P4: the PARLIO TX unit (default) streams its frame buffers straight out of octal PSRAM, as does the legacy LCD_CAM panel (`esp_lcd_new_rgb_panel(flags.fb_in_psram=true)`). The shared DMA bus tolerates 32 MB/s sustained on 200 MHz octal PSRAM (peak ~200 MB/s, shared with cache and other masters — comfortable headroom). One `esp_cache_msync(DIR_C2M)` is required after CPU writes and before the GDMA kick.

The **DMA emission duration** tracks the actual config — pinning it at the worst case would mean 82 ms/frame (≈ 12 FPS) regardless of content. On PARLIO the buffers and the emission length have separate lifetimes:

- the three frame buffers are allocated **once at the cap** and never resized, so `render_task` never allocates (AGENT.md);
- the **TX unit** is recreated whenever the frame length changes, which is what actually sets the emitted length.

The unit has to be rebuilt because IDF's loop transmission wraps its DMA chain with `gdma_link_concat(link, -1, …)`, and a negative index resolves modulo `num_items` — the last *allocated* descriptor, not the last mounted one. `num_items` comes from `max_transfer_size` at unit creation, so a link list longer than the payload wraps from a descriptor the DMA never reaches: the chain ends and the FIFO starves, with `ESP_OK` returned throughout and every counter still reporting healthy frames. Recreating the unit costs a few KB of internal descriptors, against the megabytes of PSRAM that resizing the buffers used to churn on every pixel-count detent.

LCD_CAM has no such split — the frame length lives in the panel's timing registers — so it recreates the panel, frame buffers included, from inside `render_task`. That is one reason it is debug-only.

### NVS

One blob per key, each with a one-byte layout version next to it:

| Key | Size (max) |
|---|---:|
| `global` (IP, ArtNet, names, show settings) | 172 B |
| `ch0`..`ch7` (gaps and fixtures included) | 8 × 184 B  |
| `effects` (31 effects) | 1.5 kB |
| `scenes4` (30 scenes of 8 parts) | 1.6 kB |
| `control`, `playlist`, `groups`, `rollback` | 3.7 kB |
| `scenes` (pre-bank list, kept for a rollback) | 1.0 kB |
| Total | ~9 kB |

The 24 kB NVS partition (about 20 kB usable, one page being kept for garbage
collection) holds it with room for a blob to be rewritten.

---

## 6. Synchronization

pixfrog deliberately avoids mutexes on the hot path. All data-plane handoffs are **atomic pointer swaps**.

### 6.1 Universe banks (front / back + dirty mask)

Two universe banks; `g_uni_front` (atomic pointer) is the one `render_task`
reads, the *back* bank is simply the other one — derived, never stored, so it
cannot go stale. Receivers write a slot into the back bank (seeded from the
front the first time it is touched since the last swap) and set its bit in
`g_uni_dirty`; `render_task` swaps once per frame, only when something is
dirty, so a universe nobody updated keeps its value (hold-last-look).

A slot written before a swap and not since exists in one bank only — the
other still holds its previous frame. `g_uni_behind` remembers those slots
and `swap_universes()` copies them front → back before the flip
(`level_back_bank`), or two senders at different rates — a pixel mapper and a
desk on the same output, a universe sent on change only — would alternate
between their last two frames. One 512-byte copy per slot after its last
write; none while every universe arrives every frame.

Resolving the back bank and writing into it must not straddle a swap, so both
sides take **`g_uni_swap_mux`**: the receivers (`artnet_rx` / `sacn_rx`,
priority 10), the FSEQ player for a whole frame (`inject_frame_begin/end`,
so a multi-universe frame is published by one swap), and `render_task`
(priority 20) for the pointer flip. That is a **priority inversion by design**:
the render task can wait for a lower-priority holder. It is bounded — a holder
does at most one universe's merge + 512-byte copy (an FSEQ frame: its
universes' copies), microseconds — and FreeRTOS mutexes inherit priority, so
the holder cannot be preempted by middle-priority work meanwhile.

### 6.2 Buffer-free wait (end of DMA emission)

The default **PARLIO TX backend** runs in loop mode and marks no DMA EOF, so
there is no completion interrupt. The buffer just retired by a swap is known
free exactly one frame duration after the swap was submitted; `render_frame()`
parks on that timed deadline before reusing it.

The legacy **LCD_CAM backend** does fire a completion ISR, so it waits on a
semaphore instead:

- LCD_CAM `on_color_trans_done` ISR → `xSemaphoreGiveFromISR(done_sem)`
- `render_task` → `xSemaphoreTake(done_sem, timeout)` before kicking the next frame

Either way, if the wait expires `dma_underruns` is incremented and the next
frame proceeds anyway — no error cascade.

### 6.3 Sync mode and the ArtSync wake

- `dmx::note_sync()` is called on an ArtSync, or an E1.31 sync packet on the address the data asked for (`sacn_rx_task`); it sets `g_sync_pending` and gives `g_sync_sem`. E1.31 data with a sync address calls `dmx::note_sync_hold()`.
- Once a sync is seen, `swap_universes()` publishes the back bank only when `g_sync_pending` is set (consumed even with nothing new), so all the universes of a frame go out together; after 4 s (Art-Net) / 2.5 s (E1.31) without a sync it free-runs again (`dmx::sync_mode()`).
- `render_task::dmx::wait_for_sync_or_period(remaining)` blocks on the semaphore with a timeout; a sync interrupts the wait so the next frame goes out without waiting a whole period.

### 6.4 Event group (config dirty bits)

UI commits set bits in `g_remap_eg` (bit `n` per channel, bit 8 for global). `render_task` consumes them at the start of every frame via `dmx::handle_pending_remaps()`, which rebuilds the universe → channel LUT when needed.

### 6.5 Config store and NVS

Config writes come from several tasks: `ui_task`, the UART console, `httpd`,
and `artnet_rx` (ArtAddress / ArtIpProg). Every setter takes one **recursive
config lock**, so writers never interleave inside a struct; a caller's
read-modify-write (`get_*` → change a field → `set_*`) holds a
`config::ScopedLock` across it so another task's write cannot be lost in
between. Writes go through to NVS under the lock and can take a few ms.

`render_task` never takes that lock: it reads the RAM cache by reference, and
copies what an output plays — a scene's part and the effect it points at — with
`config::copy_scene_part()`, a **seqlock** over the effect and scene banks: a
list edit (memmove) bumps a counter around the RAM change and the reader
retries if it overlapped, falling back to the lock only if a writer keeps
getting in the way. NVS blobs carry a layout version (`v_<key>`) next to
them; one written by a newer firmware is ignored rather than misread.

---

## 7. ISRs and IRAM

All ISRs are `IRAM_ATTR`:

- Ethernet RX (IDF, already in IRAM)
- LCD_CAM `on_color_trans_done` → `xSemaphoreGiveFromISR(done_sem)` — **legacy
  backend only**; the default PARLIO loop backend marks no DMA EOF and takes no
  per-frame completion interrupt.

(The seesaw encoder is time-polled on the 4-wire harness — no IRQ.)

Required sdkconfig flags: `CONFIG_GDMA_ISR_IRAM_SAFE=y` (both backends), plus
`CONFIG_LCD_CAM_ISR_IRAM_SAFE=y` on the legacy LCD_CAM path.

> The frame buffer lives in PSRAM (which goes through the CPU cache), but GDMA itself talks directly to PSRAM via the cache controller without CPU involvement. PSRAM placement is fine for the buffer; only the ISR code needs to be in IRAM.

---

## 8. Hot reconfiguration

Changing a channel's protocol can change:

1. Samples per bit (NRZ vs clocked encoding)
2. Required PCLK frequency (one PCLK clocks the whole 16-bit bus)
3. Pixel buffer size (RGB vs RGBW)

**Decision**: PCLK is **fixed at boot** to a compromise value (see `docs/PROTOCOLS.md` §3). Samples per bit are derived per channel without changing PCLK. Clocked protocols run at PCLK/N where N is computed to hit the requested CLOCK rate.

Consequence: **changing protocol at runtime never changes PCLK**. `render_task` swaps the channel's encoder descriptor between frames; the pixel buffers are sized for the worst case at boot. The one exception is the frame length: a config commit that moves the required sample count to a different bucket tears down and recreates the output unit (FB realloc included) — once per commit, between frames, never in steady state.

DMX512 output (formerly a fourth encoder family) was removed: it lives in
the DMX node firmware (a separate project forked from this one).

---

## 9. Module map

| Component | Responsibility | Depends on |
|---|---|---|
| `led_output` | 16-bit bus output: PARLIO TX loop (default) or legacy LCD_CAM; PSRAM FBs, gamma-LUT cache | IDF HAL, `led_protocols`, `dmx_manager` |
| `led_protocols` | Per-protocol encoders (NRZ, SPI-like) + gamma/WB LUT builder | (free) |
| `net` | The box's IP addressing: static / DHCP / Art-Net fallback, applied at boot and live on every change (web, console, menu, ArtIpProg); link and address events, published to `main` through one callback | `esp_netif`, `config_store` |
| `artnet` | UDP parser, Dmx/Poll/Sync/Address/IpProg/Trigger, replies | `lwip`, `dmx_manager`, `net` |
| `sacn` | E1.31 receiver: multicast joins, priority gate, sync | `lwip`, `dmx_manager`  |
| `dmx_manager` | Universe pool, 2-source HTP/LTP merge, channel mapping, capacity check, scenes/failsafe/identify state | `config_store` |
| `fseq_player` | microSD FSEQ show playback: SDMMC 4-bit + FAT mount/hot-plug, v2 zstd frame decode, pacing, inject into pool from the `fseq_universe` setting (byte 0's universe, default 1); ArtTimeCode / FPP seek hooks | `config_store`, `dmx_manager`, `sdmmc`, `fatfs` |
| `fpp_sync` | Opt-in FPP MultiSync remote (UDP 32320 + multicast): master START/STOP/SYNC drive the local FSEQ player | `lwip`, `fseq_player` |
| `config_store` | NVS wrappers + RAM cache + forward migration + web password hash | IDF NVS, mbedtls |
| `web_config` | Opt-in HTTP server: SPA, REST, OTA, backup/restore, Basic auth | esp_http_server, `app_update` |
| `ui` | Canvas API (OLED or TFT) + seesaw + menu FSM + splash | IDF I2C / SPI, `config_store`, `esp_lcd` (TFT only) |
| `control_console` | UART0 REPL: full config, telemetry, DMX injection  | esp_console |
| `boards/<hw>.h` | Pinout, hardware capabilities | (header-only) |

**Dependency rule**: `led_output` knows nothing about ArtNet; `artnet` knows nothing about LCD_CAM. They meet in `main.cpp` via `dmx_manager`, which owns the pointer dance. Likewise `net` knows nothing of the screen or Art-Net: `main.cpp` registers the publisher that hands them the address, so the surfaces that change a setting (`ui`, `control_console`, `web_config`, `artnet`) can call `net::apply()` without a cycle.

---

## 10. Logging and telemetry

Per-module ESP_LOG tags: `ARTNET`, `PARLIO_OUT` / `LCD_CAM` (active backend), `UI`, `DMX`, `CFG`, `MAIN`. Default level `INFO`, tunable at build time.

Internal counters exposed by `dmx_manager_get_stats()`:

```cpp
struct Stats {
    uint64_t frames_emitted;
    uint64_t artnet_packets_rx;   // ArtDmx routed to a mapped universe
    uint64_t artnet_bad_packets;  // malformed (ArtNet or sACN)
    uint64_t artnet_ctrl_rx;      // ArtAddress/IpProg/Nzs/Trigger/Command/TimeCode
    uint64_t sacn_packets_rx;     // sACN data routed to a mapped universe
    uint32_t dma_underruns;
    uint32_t current_fps;
};
```

Read by HOME, the UART console (`stats`) and `/api/config`.

---

## 11. Security / robustness

- No WiFi → no RF attack surface.
- The only always-on listener is ArtNet UDP. sACN (UDP 5568) and the web UI
  (TCP 80) are strictly opt-in — no socket while disabled.
- ArtNet *can* reconfigure the node (ArtAddress/ArtIpProg, per Art-Net 4) and
  trigger scenes (ArtTrigger) — standard desk-side behaviour.
- Web mutations (config, OTA, reboot) sit behind optional HTTP Basic auth;
  the password is stored as a salted PBKDF2-HMAC-SHA256 (4096 rounds), never
  in clear, and the UART console is the physical recovery channel. There is
  no TLS: the password crosses the network in clear on every request — the
  password keeps honest mistakes out of a private show network, it is not a
  defence against someone sniffing it.
- OTA uses A/B slots with BOOTLOADER_APP_ROLLBACK: a new image confirms
  itself only after 30 s of a live render loop (`ota_confirm_task`), so one
  that crashes or hangs early is reverted on the next reset; a power cut
  mid-upload never touches the running slot. Every rollback is logged at boot
  and kept as an NVS record (rejected version/slot, reset reason) shown by the
  web dashboard banner, `/api/diag` and the console `version` until
  acknowledged (`POST /api/rollback/ack`, `rollback ack`).
- Hardware watchdog enabled; `render_task` is subscribed and kicks every frame.

---

## 12. Out of scope (see TODO.md for the live list)

- RDM (over ArtNet or on the wire)
- Inter-controller frame sync (PTP)

Formerly listed here and since shipped: sACN E1.31, the web UI (native on the
P4 — no co-MCU needed), the scene/FX engine, the FSEQ player from microSD
(plus ArtTimeCode / FPP MultiSync slaving), and the 2-source HTP/LTP merge.

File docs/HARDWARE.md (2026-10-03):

# pixfrog hardware

Target board for v0: **Waveshare ESP32-P4 Module DEV-KIT**.

Full schematic, pinout, datasheet and accessory documentation:

→ <https://docs.waveshare.com/ESP32-P4-Module-DEV-KIT/Resources-And-Documents>

All pin assignments in this document are exposed on the user-facing header connector documented by Waveshare; nothing collides with the internal Ethernet PHY (IP101GRI), PSRAM, or flash signals.

---

## 1. Board overview

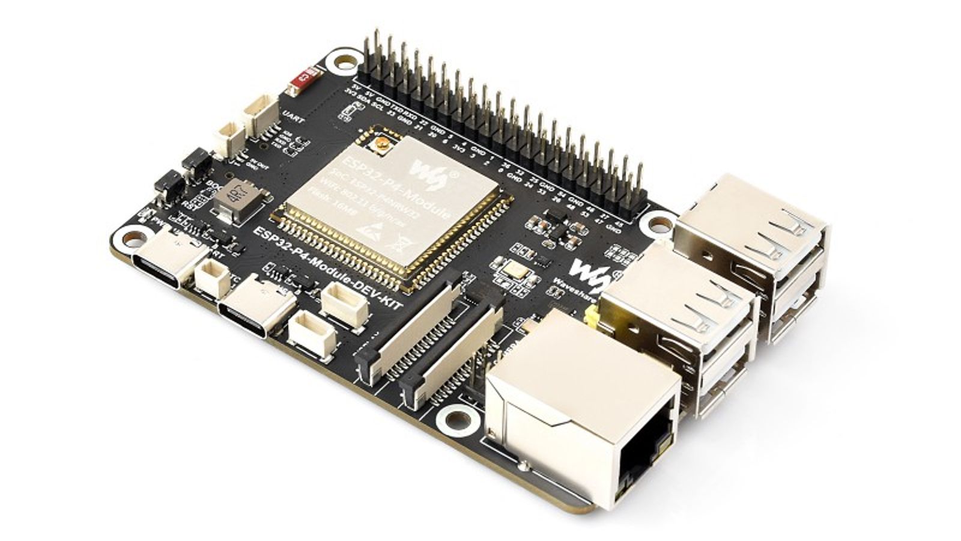
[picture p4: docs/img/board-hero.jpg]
Waveshare ESP32-P4 Module DEV-KIT — the default pixfrog board


- ESP32-P4 dual-core RISC-V @ 360 MHz
- 32 MB octal PSRAM
- 16 MB external flash
- **IP101GRI Ethernet PHY** with onboard magnetic RJ45 jack (RMII pre-wired)
- USB-C OTG + UART debug bridge
- Header connector exposes the user GPIOs in the layout shown below

External components added for pixfrog:

- 1 × NV3007 SPI colour bar TFT 428×142 (2.79", ER-TFT2.79-1)
- 1 × Adafruit seesaw QT rotary encoder #4991
- 2 × 74HCT245 level shifters (3.3 V → 5 V) — one per group of 8 GPIOs
- 8 × XLR strip output connectors (GND, DATA, CLOCK — plus VCC on the XLR4
  variant, §8)

---

## 2. Pinout

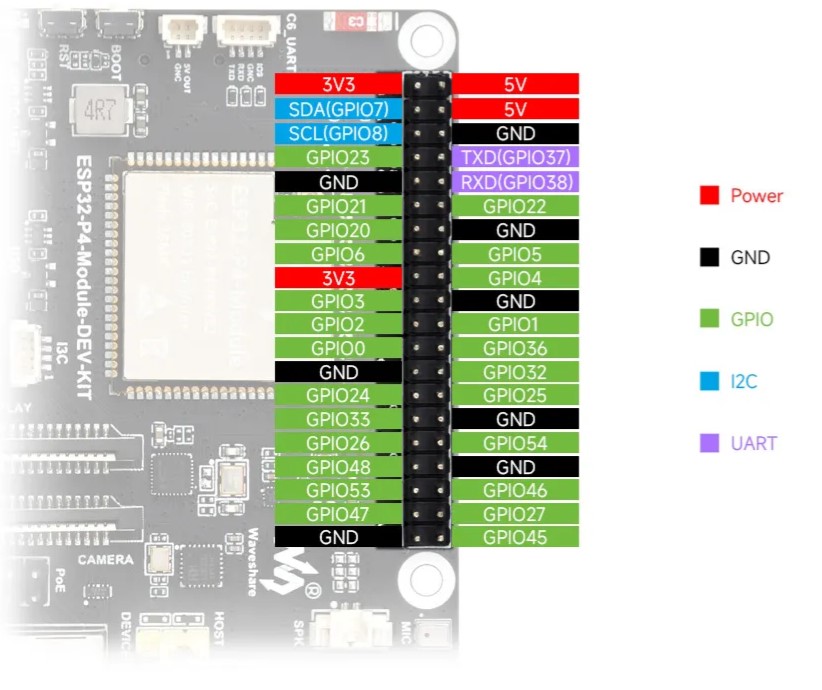
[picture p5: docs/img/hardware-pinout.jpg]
Waveshare ESP32-P4 Module DEV-KIT — labelled header and interfaces


Validated against the Waveshare ESP32-P4 Module DEV-KIT schematic (P6 40-pin header). Strapping pins latched at reset (ESP32-P4 datasheet §3.3): **GPIO 35** (boot/download select, driven by the on-board BOOT button — also doubles as RMII TXD1), **GPIO 36** (must read HIGH for a reliable serial-download boot — exposed on P6 pin 21, keep it free), **GPIO 34** (JTAG source select). None of the LED pins below land on a strapping pin. GPIO 16 is not exposed on P6 and must not be used.

### 2.1 LED 16-bit parallel bus (PARLIO TX / LCD_CAM)

ESP32-P4 routes every peripheral signal through the GPIO matrix, including the 16 data lines of the parallel LED bus. Any free GPIO is a valid bus data line — the choices below pick header pins that are easy to route in pairs. The bus is driven by the default **PARLIO TX** backend or the legacy **LCD_CAM** RGB backend (Kconfig choice); both clock the same 16 GPIOs from PSRAM via GDMA and emit identical sample streams (see `docs/PROTOCOLS.md` §3).

| Bus bit | Signal | GPIO | Notes |
|---:|---|-----:|---|
| 0 | CH1_DATA  | 2 | strip 1 data |
| 1 | CH1_CLOCK | 3 | strip 1 clock (clocked LEDs)|
| 2 | CH2_DATA  | 4 | |
| 3 | CH2_CLOCK | 5 | |
| 4 | CH3_DATA  | 22 | |
| 5 | CH3_CLOCK | 23 | |
| 6 | CH4_DATA  | 24 | |
| 7 | CH4_CLOCK | 25 | |
| 8 | CH5_DATA  | 26 | |
| 9 | CH5_CLOCK | 46 | P6 pin 33 (adj. to CH5_DATA)|
| 10 | CH6_DATA  | 32 | |
| 11 | CH6_CLOCK | 33 | |
| 12 | CH7_DATA  | 47 | |
| 13 | CH7_CLOCK | 48 | |
| 14 | CH8_DATA  | 53 | |
| 15 | CH8_CLOCK | 54 | |

> The bus clock (PCLK) pin stays internal on both backends — LCD_CAM with `pclk_gpio_num = -1`, PARLIO with `clk_out_gpio_num = GPIO_NUM_NC`. CLOCK signals for clocked LED protocols (APA102, …) are encoded as bits 1, 3, 5, … of the parallel sample stream, not derived from PCLK. See `docs/PROTOCOLS.md` §3.

### 2.2 Ethernet RMII (internal)

The PHY's RMII + management pins use fixed SoC GPIOs that are wired directly on the DEV-KIT (verified against the schematic, PHY U7 = IP101GRI) and are not brought out to the P6 header, so they impose no constraint on the LED bus pinout above. The RMII data/clock pins equal the IDF v5.5 `ETH_ESP32_EMAC_DEFAULT_CONFIG()` defaults, which match the board wiring — so `main/init_network()` only overrides MDC / MDIO / reset:

| Signal RMII | GPIO P4 | Note |
|---|---:|---|
| EMAC_REF_CLK  | 50 | 50 MHz, fixed |
| EMAC_TX_EN | 49 | fixed |
| EMAC_TXD0 | 34 | fixed (also a boot strap) |
| EMAC_TXD1 | 35 | fixed (also the BOOT-button strap) |
| EMAC_RXD0 | 29 | fixed |
| EMAC_RXD1 | 30 | fixed |
| EMAC_CRS_DV | 28 | fixed |
| MDC | 31 | U7 pin 22 |
| MDIO | 52 | U7 pin 23 |
| PHY reset | 51 | U7 pin 32 — drive HIGH to release |
| PHY address | 0x01 | IP101GRI strap (AD0/AD3) |

> The old MDC=29 / MDIO=30 values were carried over from the Espressif Function EV Board and never link on the Waveshare DEV-KIT — GPIO 29/30 are actually the RMII RX data lines there. Use the values above.

### 2.3 I2C (encoder)

| Signal | GPIO | Note |
|---|-----:|---|
| SDA | 7 | `SDA(GPIO7)` on the header silkscreen |
| SCL | 8 | `SCL(GPIO8)` on the header silkscreen |

I2C addresses:

- seesaw 4991: `0x36` (factory default)
- SSD1306: `0x3C` or `0x3D` — only on the optional OLED build (§6)

Bus frequency: **400 kHz** (Fast Mode). The bus is initialised on every build:
the encoder needs it whichever display is fitted.

### 2.4 Miscellaneous

| Signal | GPIO | Note |
|---|-----:|---|
| STATUS_LED | 1 | optional external heartbeat |
| DEBUG_TX | 37 | UART0 console — `TXD(GPIO37)` on silkscreen |
| DEBUG_RX | 38 | UART0 — `RXD(GPIO38)` |

### 2.5 microSD (SDMMC 4-bit)

The FSEQ player reads `.fseq` shows from a microSD card on the SDMMC 4-bit bus:

| Signal | GPIO | Signal | GPIO |
|---|-----:|---|-----:|
| CLK | 43 | D0 | 39 |
| CMD | 44 | D1 | 40 |
| | | D2 | 41 |
| | | D3 | 42 |

The data lines do not follow the GPIO order (DEV-KIT schematic, *MicroSD Card*
block, slot SD1). None of these GPIOs appear in the LED bus, SPI display, I2C,
Ethernet or UART pin lists.

**Card supply — GPIO 45.** The card's VDD comes from LDO VO4 through P-MOSFET
Q1 (AO3401) whose gate is GPIO 45, pulled down by 10 kΩ: **the card is powered
only while GPIO 45 is LOW**. `fseq::init` drives it low (`kSdPowerGpio`) and
waits 10 ms before the first mount. GPIO 45 must carry nothing else — it used
to be the TFT backlight, and a lit screen switched the card off (the mount then
fails with `send_op_cond … 0x107`, visible with `loglevel debug`).

### 2.6 Pad power domains (VDD_IO_5 LDO)

GPIO 39–48 sit in the **VDD_IO_5** pad domain, powered by the SoC's internal LDO output **VO4**. Left unprogrammed, VO4 idles near **1.2 V**, so those pads only swing ~1.2 V — not enough to drive a 5 V buffer or an SD card. `main::power_vdd_io5_pads()` programs VO4 to **3.3 V** at boot. This domain covers **CH5 CLOCK (46)**, **CH7 DATA/CLOCK (47/48)** and the entire **microSD** bus (39–44), so the LDO step is mandatory for those outputs.

### 2.7 Speaker (ES8311 codec + NS4150B amp) — the R52 mod

The module has an ES8311 codec (I2C `0x18` on the shared bus; I2S MCLK 13,
BCLK 12, WS 10, DSDIN ← GPIO 9, ASDOUT → GPIO 11) feeding an NS4150B class-D
amplifier. Stock, the amp's enable `PA_CTRL` comes from **GPIO 53 through R52
(0 Ω)**, with **R58 (10 kΩ) to ground** — but GPIO 53 is LED output 8 DATA,
so the amp would follow the LED data.

**Mod:** remove R52 and pull `PA_CTRL` up with a 10 kΩ to 3.3 V: the amp is
always on, the firmware mutes the codec after 10 s of quiet.

**Detection:** at boot, before the LED outputs take it, GPIO 53 is read with
its internal pull-up (~45 kΩ). Stock, R52 + R58 hold it near 0.6 V (low); with
R52 removed nothing pulls it down (high). A stock board gets no audio at all
(no task, no menu entry, no web card). It cannot see the added pull-up itself,
and an external pull-down on CH8 DATA (≤ ~15 kΩ), or an unpowered shield
clamping the line, reads as stock.

Sounds (`components/audio`): knob tick / end-stop bump, confirm / cancel on
clicks, a frog croak at the end of the splash, a test chime. Volume
`speaker_volume` 0 (off, the default) … 100 %, even in dB (-40 … 0 dB); every
sound normalized to 0.6 of full scale (the amp clipped above). One request
waits at most: a newer one cuts the playing sound short (2 ms fade).

---

## 3. Level shifters

The SoC drives **3.3 V CMOS**. 5 V strips have variable thresholds:

| Strip | Vih @ Vcc=5 V | 3.3 V direct OK? |
|---|---|---|
| WS2815 | typ 0.7 × Vcc = 3.5 V | **No** — borderline |
| WS2812B | typ 0.7 × Vcc = 3.5 V | No (same) |
| WS2811 | 0.7 × Vcc = 3.5 V | No |
| SK6812 | 0.65 × Vcc = 3.25 V | Marginal |
| APA102 / SK9822 | 0.7 × Vcc = 3.5 V | No |

**Decision**: level shifters are mandatory for production. For early bring-up with short strips (< 30 LEDs) near the PSU, the first WS2815 often regenerates the signal — fine for a scope test, not for shipping.

**Part**: **74HCT245** (8 bits per package, two packages cover all 16 GPIOs). The `HCT` (not HC) variant is critical: Vih = 2.0 V (CMOS-to-TTL threshold), guarantees clean switching from 3.3 V CMOS into a 5 V CMOS strip.

3.3 V → 5 V level shifting with a 74HCT245 buffer, series resistor and TVS clamp on each output

Realised as the **pixfrog shield** (see §9.1, *pixfrog_rack — board*, below).

---

## 4. Encoder wiring (Adafruit seesaw 4991)

OLED and seesaw encoder on the shared I²C bus

Everything is over I2C:

```
seesaw 4991       ESP32-P4
─────────────     ──────────
Vin (3-5 V)  ───► 3.3 V
GND          ───► GND
SDA          ───► GPIO 7  (I2C SDA)
SCL          ───► GPIO 8  (I2C SCL)
INT          ───► not connected (see below)
ADR (option) ───► float → address 0x36
SS (option)  ───► unused (I2C only)
```

The seesaw INT_N line is **deliberately unused** — a 4-wire harness
(VCC/GND/SDA/SCL) is all the encoder needs:

- `ui_task` already loops at ~30 Hz for the encoder-LED animation and the
  diff-based display refresh, so time-polling adds at most one tick (~33 ms)
  of input latency — imperceptible on a rotary detent.
- Skipping the interrupt machinery removes two extra I2C reads per poll
  (the `GPIO_INTFLAG` + `ENCODER_DELTA` latch clears the seesaw requires to
  re-arm INT_N).

Firmware path: `ui_task` polls position + button over I2C every ~33 ms and
queues RotateLeft/RotateRight/Click/LongPress events into the menu FSM.
GPIO 21 (previously reserved for INT) is free.

Reference: [Adafruit Learn — I2C QT Rotary Encoder](https://learn.adafruit.com/adafruit-i2c-qt-rotary-encoder).

---

## 5. TFT display wiring (NV3007 — default)

The display is a **NV3007 428×142 SPI colour bar TFT** (ER-TFT2.79-1, 2.79"),
selected by default — a plain `idf.py build` targets it. The glass is portrait
142×428; the scan direction is the hardware default (the reference code never
programs MADCTL), so firmware addresses it as landscape 428×142 and
`PIXFROG_NV3007_ROT180` flips it. It is **on by default**, because the panel sits
upside down in the 1U rack; clear it in `sdkconfig.defaults` for a right-way-up
mounting.

Wiring is identical for every SPI panel — only the controller init and the
geometry differ:

```
SPI panel         ESP32-P4
──────────────    ─────────
VCC (3.3 V)  ───► 3.3 V
GND          ───► GND
CLK (SCLK)   ───► GPIO 0
MOSI (SDA)   ───► GPIO 6
CS           ───► GPIO 20
DC (RS)      ───► GPIO 21
RST          ───► GPIO 27
```

These five signals are broken out on the shield's **J13** header. They replace
the original GPIO 9-13 mapping, which reused the on-board ES8311 codec's I2S
pins — those are **not** exposed on the connector/shield. All five chosen GPIOs
are free, 3.3 V-direct and non-strapping; every signal routes through the GPIO
matrix, so the assignment is arbitrary among the free pins. J13 also exposes
GPIO 36, used as the backlight control pin (§5.1), and GPIO 45, which is
*not* free: it switches the microSD supply (§2.5). GPIO 36 is a boot strapping
pin, harmless here — the boot mode follows GPIO 35 (the BOOT button, pulled
high); GPIO 36 only matters with BOOT held, for the download modes. There is no
MISO — the panel is write-only.

SPI host: `SPI2_HOST`, **20 MHz** (`kDisplaySpiFreqHz`). 40 MHz is rejected by
the P4 SPI driver (`invalid sclk speed` — the default clock source can't derive
it); 20 MHz is a clean divisor and ample for either panel.

Color format: RGB565 big-endian. `canvas_tft.cpp` applies `__builtin_bswap16` to
every pixel value before writing to the DMA buffer.

The encoder wiring (§4) is unchanged whichever panel is fitted.

### 5.1 Backlight — GPIO 36, LEDC PWM

```
Panel LEDA ───► GPIO 36          LEDK ───► GND
```

(It was on GPIO 45 until the microSD was brought up: GPIO 45 gates the card
supply, §2.5. Move the BL wire to J13's GPIO 36 with this firmware.)

The ER-TFT2.79-1 (NV3007 variant) brings out the **bare LED string**: 5 chips in
parallel, **Vf ≈ 3.0 V, If typ 75 mA / max 100 mA** (datasheet §4.4). The pad
sources that current directly. Three consequences the firmware is built
around:

- **Full brightness = 100 % duty**, i.e. the pad statically high, exactly how the
  pre-dimming firmware drove it. Dimming can only ever *lower* the average
  current, never raise it.
- **The pad's drive strength is left at its default** — on this panel it is what
  sets the LED current, so changing it would move what "100 %" means.
- **20 kHz PWM** (`LEDC_TIMER_0` / `LEDC_CHANNEL_0`, 10-bit, low-speed mode —
  the P4 has no high-speed one): above the audio band, and above any camera
  shutter, so the panel never bands on video. 10 bits × 20 kHz = 20.5 MHz, well
  inside the 80 MHz source.

Perceived brightness is not linear in duty, so `tft_backlight_pwm.cpp` squares
the level (gamma ≈ 2), and floors the duty at 1 % so a non-zero level never
rounds down to a dark panel. Boot and idle transitions use the LEDC hardware fade
(400 ms); a level edited on the encoder is applied instantly so the panel tracks
the detents.

Three settings, all in `GlobalConfig` (menu **DISPLAY**, `global tft_brightness`
/ `tft_idle_dim` / `tft_dim_delay_s` on the console, System card in the web UI):

| Field | Range | Meaning |
|---|---|---|
| `tft_brightness` | 10..100 % | Backlight level. 0 = written by a pre-dimming firmware = 100 %. |
| `tft_idle_dim` | 0..100 % | How much dimmer once idle. 0 = never dim, 100 = backlight off. |
| `tft_dim_delay_s` | 0..3600 s | Inactivity before dimming. 0 = never dim. |

The delay is the backlight's own — `home_timeout_s` only decides when the menu
walks back to HOME, so the panel can dim long before (or after) that. It is read
on every UI tick, so a change from the menu, the console or the web UI applies
without a reboot. Dimming needs *both* halves: either field at 0 keeps the panel
at its steady level.

Fresh installs default to 100 % / −60 % after 30 s; a config migrated from a
firmware that predates dimming zero-fills all three and stays always-bright. The
first encoder event after the panel has dimmed only wakes it — it is not
dispatched to the menu, so a click on a dark screen never acts blind.

If the panel is wired through its own driver or transistor instead (BL pin =
enable), nothing changes on the firmware side; only the current the pad sources
does.

### 5.2 Other panels

The same SPI backend also drives a **ST7789V / ILI9341 320×240** panel
(`sdkconfig.ci.st7789`): portrait 240×320 glass, addressed as landscape via
`esp_lcd_panel_swap_xy(true)` after init. Build it with the overlay — see
[README → Display backend](https://github.com/Lefix2/pixfrog#display-backend). Picking the wrong
panel is not a build error: it flashes, the backlight lights, and the matrix is
driven with the other controller's init. The boot log is the check —
`TFT: NV3007 428x142 ready (landscape)` versus `TFT: ST7789 320x240 ready`.

---

## 6. OLED display (SSD1306 — optional)

A **SSD1306 128×64 I²C OLED** is supported as an alternate build
(`sdkconfig.ci.oled`, see [README → Display backend](https://github.com/Lefix2/pixfrog#display-backend)).
It needs no wiring beyond the encoder's I²C bus (§2.3); refresh is **10 Hz** via
diff-based flush.

---

## 7. Power

- ESP32-P4 + 3.3 V logic: LDO or DC-DC on the DEV-KIT (already done).
- Signal ground must be common between the board and the strips — every output
  carries GND on pin 1 of its XLR alongside the DATA/CLOCK pair (§8).

---

## 8. Output connectors — XLR3 / XLR4

A pixfrog channel always leaves the enclosure on an **XLR** connector, and every
board that emits, repeats or consumes a channel uses the same pin order:

| Pin | Signal | WS281x (NRZ) | Clocked (APA102 / SK9822 / LPD8806) |
|----:|---|---|---|
| 1 | GND | signal + power return | signal + power return |
| 2 | DATA+ | DATA | DATA |
| 3 | DATA− | unused | CLOCK |
| 4 | VCC | strip supply (XLR4 only) | strip supply (XLR4 only) |

Pins 2 and 3 are the same physical pair in every mode — only the firmware's
interpretation changes (`docs/PROTOCOLS.md` §3): the second line of the bus is
the CLOCK of a clocked strip, or nothing at all on a WS281x run. (The DMX node
firmware drives the same pair as DATA+/DATA− of a DMX512 universe.)

Two shells, one convention:

- **XLR3** — pins 1-3, signal only. The assignment is deliberately the DMX512
  standard one (1 = common, 2 = data+, 3 = data−), so an off-the-shelf DMX cable
  carries a pixfrog channel as-is (and the DMX node firmware, on the same
  hardware, plugs straight into a fixture). The strip takes its power from a
  local PSU.
- **XLR4** — the same three pins plus **pin 4 = VCC**, the strip supply (12 V or
  24 V per build) travelling down the same cable as its data.

Splitting the two across two shells is the point of the choice: XLR3 and XLR4
do not mate, so a cable carrying strip voltage on pin 4 cannot be plugged into a
signal-only line, nor the reverse.

Pin 1 returns both the data pair and, on XLR4, the full strip current, so the
conductor and the crimp must be sized for the injected current — not for a
signal ground (§7).

---

## 9. pixfrog_rack

The controller end: the devkit and its conditioning board in a 1U chassis, the
eight channels on the front panel.

```
devkit ──2×20 header──► pixfrog shield ──loom──► 8× XLR front panel ──► strip / satellite
 3.3 V GPIOs            level-shift + protect       §8 pinout
```

### 9.1 Board — pixfrog shield

[`hardware/pixfrog_shield/`](https://github.com/Lefix2/pixfrog/tree/main/hardware/pixfrog_shield) — KiCad 10.
Plugs onto the devkit's 2×20 header and re-drives all 16 bus lines at 5 V through
2× 74HCT245 (the level shifter of §3 realised), with DIP-selectable series
termination, a 5 V TVS clamp per output and 8× JST-XH (DATA/CLOCK/GND) feeding
the panel connectors. It also breaks out the TFT display and the spare GPIOs on
its J13 header (§5).

pixfrog shield

### 9.2 Meca — 1U enclosure

[`hardware/pixfrog_rack/`](https://github.com/Lefix2/pixfrog/tree/main/hardware/pixfrog_rack) —
Fusion 360, not KiCad: a `.f3z` archive holding the 1U 200 mm chassis, the
front-panel UI holder that carries the NV3007 bar panel and the seesaw encoder,
the devkit + shield stack, the Neutrik XLR outputs and the 5 V / 15 W supply. The
panel is mounted upside down in this design, which is why
`PIXFROG_NV3007_ROT180` defaults to on (§5). Component list in
[its README](https://github.com/Lefix2/pixfrog/tree/main/hardware/pixfrog_rack).

pixfrog rack, open

---

## 10. pixfrog_satellite

The far end of a long run. Independent of, and complementary to, the rack: the
shield conditions the bus at the controller, a satellite keeps the signal and the
strip voltage clean over distance.

```
pixfrog rack ──long cable──► pixfrog satellite ──► LED strip
   §8 pinout                 repeat + power inject
```

### 10.1 Board — repeater + power injection

[`hardware/pixfrog_satellite/`](https://github.com/Lefix2/pixfrog/tree/main/hardware/pixfrog_satellite) — KiCad 10.
A 74LVC2G17 Schmitt buffer re-squares one channel's two lines and a local LD1117
(12 V or 24 V build) injects strip power, so the LEDs see fresh edges and full
voltage regardless of cable length. The 249 Ω / 39 Ω series-impedance select
(header J4) mirrors the shield's SW1. Its screw terminals follow §8: J3 in =
GND / DATA+ / DATA−, J2 out = VCC / DATA+ / DATA− / GND.

pixfrog satellite

### 10.2 Meca — WIP

**Work in progress** — no enclosure design is committed yet. The board currently
mounts bare, its H1/H2 GND pads tying it to whatever chassis or heatsink carries
it. The housing, once designed, lands next to the rack's under
[`hardware/`](https://github.com/Lefix2/pixfrog/tree/main/hardware).

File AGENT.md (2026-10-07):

# AGENT.md

Quick orientation for any agent (or human) working in this repo.

**Operational how-tos live in `.claude/skills/<name>/SKILL.md`** (plain
markdown, auto-loaded by Claude Code at the repo root, readable by anyone).
This file keeps the rules, invariants and design facts.

## What this is

Firmware for an 8-channel ArtNet → LED driver on ESP32-P4. Each channel drives an LED strip (WS/SK NRZ or APA/SK/LPD clocked SPI); DMX512 output was removed and lives in the DMX node firmware (a separate project forked from this one). Detailed design in [docs/ARCHITECTURE.md](docs/ARCHITECTURE.md); hardware in [docs/HARDWARE.md](docs/HARDWARE.md); per-protocol timings in [docs/PROTOCOLS.md](docs/PROTOCOLS.md); target board ([Waveshare ESP32-P4 Module DEV-KIT](https://docs.waveshare.com/ESP32-P4-Module-DEV-KIT/Resources-And-Documents)).

## Conventions

- **C++17**, no exceptions, no RTTI. Don't add `try`/`catch` or `dynamic_cast`.
- **No designated initializers** (`{.field = …}`) outside of `main.cpp` and IDF struct fills — they're a GCC extension under `-std=c++17` and break `-Wpedantic` host builds.
- **Comments**: don't restate what the code does. Only write a comment when WHY is non-obvious (hidden invariant, datasheet quirk, workaround). PR descriptions are not stored in code.
- **No allocation on the hot path**. Everything `compose_task` / `render_task` / ISR touches is allocated at boot.
- **ISRs are `IRAM_ATTR`** and only `xSemaphoreGiveFromISR` / increment a counter.
- **Atomic pointer swaps** for cross-thread data, not mutexes. See `dmx_manager` for the pattern.
- **Read-modify-write atomics are 32-bit** (`exchange`, `fetch_*`, `compare_exchange_*`): on
  the ESP32-P4 a sub-word RMW clobbered a neighbouring variable written by the other core.
  8/16-bit atomics are fine for plain load/store. `tools/lint_atomics.py` (CI) enforces it.
- **Config writes take the config lock** (every `config::set_*` does); a read-modify-write
  wraps `get → change → set` in `config::ScopedLock`. Never hold it around a service
  start/stop (`web::stop` waits for httpd handlers that may want the lock). The frame pipeline
  (`compose_task`, `render_task`) never takes it: what an output plays is read with `config::copy_scene_part()` (seqlock
  over the effect and scene banks). See ARCHITECTURE §6.

## Module map

| Path | Responsibility |
|---|---|
| `boards/esp32_p4_devkit.h` | Single source of truth for pinout / I2C addrs |
| `components/led_protocols` | Pure C++ NRZ + SPI encoders (host-testable) |
| `components/led_output` | 16-bit LED bus output: PARLIO TX loop (default, triple-buffered PSRAM FBs) or legacy LCD_CAM RGB backend (Kconfig choice, NOT CI-built, double-buffered), calibration |
| `components/net` | IP addressing (static / DHCP / fallback), applied at boot and live  |
| `components/artnet` | UDP receiver + parser; ArtDmx/Poll/Sync/Address/IpProg  |
| `components/sacn` | sACN (E1.31) receiver: multicast joins, priority gate (opt-in) |
| `components/dmx_manager` | Universe pool, channel mapping, capacity check, sync, scene zones + crossfade, show control (master/blackout/strobe, DMX control universe — docs/SHOW_CONTROL.md) |
| `components/config_store` | NVS-backed `GlobalConfig` + `ChannelConfig` |
| `components/fseq_player` | `.fseq` playback from microSD (SDMMC + FATFS, zstd) |
| `components/fpp_sync` | FPP MultiSync receiver: slaves FSEQ playback to a master |
| `components/web_config` | Opt-in HTTP server: config SPA, REST API, OTA (see below) |
| `components/ui` | Display drivers (NV3007 default; ST7789 / SSD1306 alternates), canvas, seesaw encoder, menu FSM, backlight PWM |
| `components/control_console` | UART0 command server: full config get/set, telemetry, DMX injection |
| `components/audio` | ES8311 codec + speaker (boards with the R52 mod, docs/HARDWARE.md §2.7): synthesized UI sounds, volume |
| `main/main.cpp` | Boot orchestration + the frame pipeline (`compose_task` core 0, `render_task` core 1) |
| `tools/fontgen` | Host tool: TTF → `font_data.cpp` (anti-aliased TFT font) |
| `tools/oledfont` | Host tool: hand-drawn 5×7 → `font_oled.cpp` (crisp 1bpp OLED font) |
| `tools/splashgen` | Host tool: `frog-anim.svg` → `splash_anim.cpp` (TFT frog anim)|
| `tools/oledsplash` | Host tool: TFT splash frame → `splash_oled.cpp` (static OLED frog logo) |
| `tools/emulator` | SDL2 host emulator of the TFT UI (no IDF) |
| `tools/uartctl.sh` | One-shot client for the control console |
| `hardware/pixfrog_shield/` | pixfrog_rack *board*: KiCad shield, 74HCT245 5V buffers, TVS, JST outputs (see its README) |
| `hardware/pixfrog_rack/` | pixfrog_rack *meca*: Fusion 360 1U enclosure (chassis, UI holder, PSU, XLR) |
| `hardware/pixfrog_satellite/`  | pixfrog_satellite *board*: KiCad repeater for the far end of a long run, Schmitt buffer + power injection (*meca*: WIP) |
| `docs/img/frog-anim.svg` | Animated logo: source for web + baked splash |

## Workflows → skills

| Skill | Operation |
|---|---|
| [build](.claude/skills/build/SKILL.md) | IDF build (docker or devcontainer), nv3007 default + st7789/oled overlays, sdkconfig traps |
| [flash](.claude/skills/flash/SKILL.md) | Flash over `/dev/ttyACM0`, boot-log capture, WSL2 replug |
| [host-tests](.claude/skills/host-tests/SKILL.md) | Every host suite via ctest (`tests/`), ASan/UBSan, whole-firmware coverage (`tools/coverage.py`, Codecov) |
| [ci-local](.claude/skills/ci-local/SKILL.md) | Replay all CI jobs locally |
| [format](.claude/skills/format/SKILL.md) | clang-format (style: `.clang-format`, don't bypass) |
| [emulator](.claude/skills/emulator/SKILL.md) | SDL2 UI emulator, headless stdin protocol |
| [regen-fonts](.claude/skills/regen-fonts/SKILL.md) | Regenerate `font_data.cpp` / `font_oled.cpp` |
| [regen-splash](.claude/skills/regen-splash/SKILL.md) | Regenerate `splash_anim.cpp` / `splash_oled.cpp` |
| [uartctl](.claude/skills/uartctl/SKILL.md) | Drive the device over UART (config, telemetry, DMX injection) |

## Web configuration UI

`components/web_config`: optional HTTP server (port 80) with an embedded SPA + REST API,
one source per API area (`api_config/show/status/fseq/system.cpp`, `web_push.cpp`,
`web_mdns.cpp`; the map is at the top of `web_internal.h`).
Controlled by `GlobalConfig::web_enabled` (NVS-backed, default **off**). No TCP socket is
opened while the flag is off — opt-in only. Toggle from the Network submenu, via
`global web_enabled 0|1` in the UART console, or via POST `/api/global`.

REST endpoints (all JSON; every POST/DELETE, plus `GET /api/logs` and `GET /api/coredump`,
behind the optional password):
- config: `GET /api/config`, `POST /api/global`, `POST /api/channel/{0..7}[/identify]`
  (3 blinks), `POST /api/identify` (`{outputs:mask}`, default every configured
  output, blinked one after the other),
  `POST /api/autopatch`, `GET /api/backup`, `POST /api/restore`; `GET /api/config`
  carries `patch_clashes`, the saved ranges that share DMX channels (PROTOCOLS
  §Auto-patch, overlap check)
- effect bank: `POST /api/effect/{n}[/delete]` (`{name, generator, colors, speed, param}`;
  delete answers 409 while a scene plays the effect), `POST /api/effects/add|move`,
  `POST /api/effect/preview` (`{effect, index, pixels, frames, fps, t}` → frames × pixels × 3
  bytes of RGB drawn by `fill_effect_run`; read-only, no password)
- scenes also take `"group"` (default fixture group, -1 = none) and `"reverse"` on a part;
  play takes `{"group":g}` as well
- scenes: `POST /api/scene/{n}[/play|/stop|/delete]` (`{name, parts:[{mask, effect,
  fixture_mode}]}`; play takes `{"outputs":mask}`), `POST /api/scenes/add|move|stop`
- groups: `POST /api/groups`
- fixture DMX profiles: `POST /api/profiles`, `GET /api/profile/{n}/fixture` (OFL profile)
- show control: `POST /api/show`, `POST /api/control`, `GET /api/control/fixture` (OFL profile)
- FSEQ: `GET /api/fseq/files`, `POST /api/fseq/play` (`{filename, loop?}` or
  `{playlist:true}`), `POST /api/fseq/stop|upload`, `GET|POST /api/fseq/playlist`
  (`{loop, autostart, items:[{name, repeat}]}`, 16 items, own NVS blob, in the backup)
- system: `GET /api/status`, `GET /api/ws` (WebSocket: the status JSON at 1 Hz
  as `{"type":"status",…}` text frames + a 5 Hz binary output preview — `'P'`,
  output count, per output n + n RGB triplets, n ≤ 64), `GET /api/diag`, `GET /api/logs`, `POST /api/loglevel`,
  `GET|DELETE /api/coredump`, `POST /api/rollback/ack`, `POST /api/ota` (raw .bin body),
  `POST /api/reboot`, `POST /api/factory-reset`, `GET /api/peers`,
  `POST /api/audio/test` (the speaker chime; 409 without a speaker or at volume 0),
  `GET /` (SPA)

Multi-node: every box is `pixfrog-<last 4 hex of MAC>.local`; the alias
`pixfrog.local` is published (delegated hostname) by one box at a time —
`web_hub` browses `_http._tcp` every 15 s and the election in `hub_election.h`
picks a box marked `hub_preferred` (Network screen, `global hub_preferred`),
else the lowest MAC; a sibling unseen for 45 s is forgotten, so a dead holder
is replaced. The TXT record carries `product=pixfrog`, `node`, `fw`, `mac`,
`hub`; a box without `mac` (older firmware) takes no part. `GET /api/peers`
browses mDNS for sibling pixfrogs (filtered on the `product=pixfrog` TXT
record, self listed first, each with `host`/`mac`/`hub`, `alias:true` on the
holder). With several boxes the SPA puts a tab bar at the very top of the page,
`[All pixfrogs] [box A] [box B] …` in name order. No box is shown as the master:
the alias only decides which box serves the page. "All" is the overview, one
card per box (status, playback, alerts) from cross-origin `GET /api/status`. A
box tab shows that box's UI full page: the native one for the box that served
the page, a sibling in a full-page `iframe` (`/?embed=1`: no tab bar of its
own, so menus never nest). Opened as `pixfrog.local` the page starts on "All";
by a unique name or IP, on that box. No
cross-origin writes. All JSON GET responses carry `Access-Control-Allow-Origin: *`
(simple read-only requests, no preflight); writes stay behind Basic auth.

SPA styling (`web_ui.html`, one embedded file): colours are `var(--…)` from the
`:root` palette (never a raw theme hex — a theme change is that one line);
repeated looks are classes (`.field`, `.f-label`, `.eyebrow`, `.card`, …) and
buttons carry their role (`.btn-pri` / `.btn-sec` / `.btn-dng`, which own the
hover); one-off layout and JS state (`display:none`) stay inline. Canvas
colours (`data-color`, sparklines) stay hex. Lucide swaps `<i>` for `<svg>`
keeping `class` but not `style`: colour an icon through a class or its parent.

Auth: HTTP Basic on every POST/DELETE and on the two GETs that may leak a
secret (`/api/logs`, `/api/coredump` — raw RAM); other GETs stay open. Enabled by setting an admin
password (`web_password` via the SPA, `/api/global`, or UART
`global web_password <pwd|->` — `-` clears). No password set (the default) =
no auth — optional by design (private show networks). Stored as a salted
PBKDF2-HMAC-SHA256 (4096 rounds) in GlobalConfig — a hash from an older firmware
(single SHA-256) still checks and is upgraded on the next login. The KDF costs
~220 ms on the P4, so the last accepted password is remembered in RAM (fast
salted hash, tied to the stored hash) and repeat requests skip it; UART is the physical
recovery channel. There is no TLS: Basic auth sends the password in clear on
every request, readable by anyone on the show network.

This is the only TCP surface beyond ArtNet UDP — the strict "no extra network surface" rule
applies to *always-on* listeners; this one is opt-in and user-controlled.

## Hard rules

- **Never commit to `main`** — it is protected on GitHub (PR-only, CI checks
  required, no force-push). Every change, however small (fix, docs, tooling),
  goes on a feature branch (`feat/…`, `fix/…`, `docs/…`, `chore/…`) and lands
  through a pull request once CI is green.
- **CI must pass locally before any push**: `./tools/ci-local.sh` replays every
  `ci.yml` job (format check, host suites plain + ASan/UBSan + coverage, emulator build + smoke test + menu crawl/goldens,
  SPA browser tests, fuzzing (15 s per target locally),
  nv3007 + st7789 + oled IDF builds). Never push and "let CI find out".
- **Coverage never goes down**: a PR that lowers the project coverage by more
  than 0.1 point against its merge-base fails CI (`tools/coverage_gate.py`,
  Codecov figures; ci-local runs the same check on the local lcov). Add tests
  with the code; a deliberate, explained drop takes the `coverage-drop-ok` label.
- A change in `led_protocols`, `dmx_manager`, or `artnet` requires the matching
  host suite green.
- The canonical proof for IDF-bound refactors is `idf.py build` — natively in
  the devcontainer (`.devcontainer/`, built on the CI image `espressif/idf:v5.5`)
  or through that same docker image. ESP32-P4 requires IDF **v5.5+** (P4
  LCD_CAM RGB panel driver).

## Control console (UART)

`components/control_console`: line-oriented command server on the UART0
console — every config field get/set, telemetry, calibration, DMX injection
without ArtNet, universe/pixel buffer readback. Protocol: `key=value` lines
then `OK`, or one `ERR <reason>` line. Use `tools/uartctl.sh` (see the
[uartctl](.claude/skills/uartctl/SKILL.md) skill) rather than raw pyserial.

Hardware facts: `/dev/ttyACM0` is a **USB-UART bridge into UART0** (CDC-ACM,
but *not* the P4's native USB-Serial-JTAG), and **opening the port can
auto-reset the board** — sync on the `pixfrog>` prompt first (uartctl does).
Console config writes share `ui_task`'s NVS path and are not locked against
it — don't turn the encoder while a script is configuring the device.

## Generated sources — never hand-edit

Fonts and splash are **generated**; regenerate instead of editing the tables
(commands in the [regen-fonts](.claude/skills/regen-fonts/SKILL.md) /
[regen-splash](.claude/skills/regen-splash/SKILL.md) skills):

- `font_data.cpp` (TFT, anti-aliased 6×8 from TTF) and `font_oled.cpp` (OLED,
  crisp 1bpp 5×7). Cell geometry (6×8) is fixed in both `fontgen.cpp` and
  `font.h` and must stay in sync — `menu.cpp` layout maths depends on it.
- `splash_anim.cpp` / `splash_oled.cpp`, baked from `docs/img/frog-anim.svg` —
  the **single source of truth**, also embedded by the web page.
- Generated/vendored files are listed in `.clang-format-ignore`.

## Don'ts

- Don't add features that aren't on the user's TODO list ([TODO.md](TODO.md)).
- Don't add WiFi, mDNS, or any extra *always-on* network surface — design
  rule. ArtNet UDP is the only default listener; sACN (UDP 5568) and the web
  UI (TCP 80) exist but are strictly opt-in (`sacn_enabled` / `web_enabled`,
  both default off — no socket while disabled).
- Don't write to NVS from the frame pipeline tasks or ISRs — only from `ui_task`.
- Don't put a frame-buffer-sized allocation in SRAM — that lives in PSRAM.
- Don't sleep in ISRs, don't `printf` in ISRs, don't grab mutexes in ISRs.
- Don't add a comment block to "summarize" what a function does when the name + types already say it.

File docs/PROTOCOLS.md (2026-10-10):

# LED protocols — pixfrog

Reference for timings, clock formulas and DMA encoding for every protocol pixfrog supports.

> Any deviation from the values in this document must be justified and verified on a scope.

---

## 1. Supported protocols

| Protocol | Family | Bit-rate / max CLOCK | Default order | Bits/pixel | Notes |
|---|---|---|---|---:|---|
| WS2815 | 1-wire NRZ | 800 kbps | GRB | 24 | Primary target, robust signal |
| WS2812B  | 1-wire NRZ | 800 kbps | GRB | 24 | Near-identical to WS2815 |
| WS2811 | 1-wire NRZ | 400 or 800 kbps | RGB | 24 | Slow or fast variant |
| SK6812 | 1-wire NRZ | 800 kbps | GRB or GRBW | 24 or 32 | Common RGBW variant |
| WS2814 | 1-wire NRZ | 800 kbps | RGBW | 32 | Dedicated white channel |
| APA102 | SPI-like | 1–30 MHz CLOCK | BGR | 32 (start + brightness + BGR) | 5-bit hardware brightness |
| SK9822 | SPI-like | 1–30 MHz CLOCK | BGR | 32 | APA102-compatible timing |
| LPD8806  | SPI-like | 1–20 MHz CLOCK | GRB | 24 | MSB of every byte must be 1 |

The 1-wire strips take any colour order: a 3-colour strip one of the six RGB
permutations, an RGBW strip (SK6812 RGBW, WS2814) one of the twelve with W last
or first — `RGBW` `RBGW` `GRBW` `GBRW` `BRGW` `BGRW` and `WRGB` `WRBG` `WGRB`
`WGBR` `WBRG` `WBGR` (`led::kColorOrderNames`, the same list in the web, the
console and the menus).

**The white LED of an RGBW strip.** The colours the box makes itself — effects,
scenes, fixtures, the failsafe and identify — are RGB. Per output, the `white`
setting (web "White LED", TFT `White`, console `ch N white`, API `"white"`) says
what the W LED does with them:

| Mode | W | R, G, B |
|---|---|---|
| `substitute` (default) | the white the three share, min(R,G,B) | minus that white: same colour, a true white LED |
| `add` | min(R,G,B) as well | unchanged: brighter, pastels whiten |
| `off` | dark | unchanged: white is an R+G+B mix |

A fixture's own White channel stays on W on top. A desk's pixel data is never
converted: with pixel mapping on an RGBW strip the desk sends W itself.

---

## 2. 1-wire NRZ timings

Typical values in nanoseconds. T0H = high time encoding a `0`, T1H = high time encoding a `1`, etc. TRESET = low time required between frames for the strip to latch.

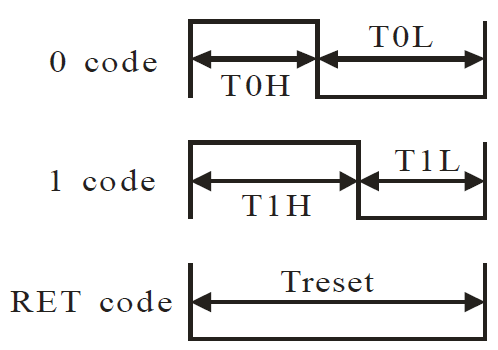
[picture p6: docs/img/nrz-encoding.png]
1-wire NRZ encoding: a and a differ only by the high time inside a fixed bit period; TRESET latches the frame


| Protocol | T0H  | T0L  | T1H  | T1L  | TDATA (T0H+T0L = T1H+T1L) | TRESET |
|---|-----:|-----:|-----:|-----:|---:|---:|
| WS2815 | 300  | 950  | 950  | 300  | 1 250 | ≥ 280 µs |
| WS2812B | 350  | 800  | 700  | 600  | 1 250 | ≥ 50 µs  |
| WS2811-fast | 350  | 800  | 700  | 600  | 1 250 | ≥ 50 µs  |
| WS2811-slow | 700  | 1 600 | 1 200 | 1 300 | ~2 500 | ≥ 50 µs  |
| SK6812 | 300  | 900  | 600  | 600  | 1 200 | ≥ 80 µs  |
| WS2814 | 300  | 950  | 950  | 300  | 1 250 | ≥ 280 µs |

Datasheet tolerance is typically ±150 ns per sub-time. pixfrog aims for the middle of the tolerance window for cross-batch compatibility.

---

## 3. Bus clock formula

### 3.1 Clock tree

Bus clock tree and the PCLK/bit/clock formulas

Both output backends clock the 16-bit bus at the same system-wide sample rate
`f_PCLK = 16 MHz` (`led_protocols::kPclkHz`), reached from a PLL source by an
integer divider:

- **PARLIO TX** (default): `PARLIO_CLK_SRC_DEFAULT` = PLL_F160M, divided by 10 → **160 MHz / 10 = 16 MHz exact**.
- **LCD_CAM** (legacy): `LCD_CLK_SRC_DEFAULT` divided so the requested `pclk_hz = 16 MHz` is realised.

Formulas:

```
f_PCLK   = f_PLL_source / CLK_DIV         integer divider
T_PCLK   = 1 / f_PCLK                     period of one DMA sample
T_bit    = samples_per_bit × T_PCLK       duration of one 1-wire DATA bit
```

For clocked protocols:

```
T_clock_cycle = samples_per_clock × T_PCLK
f_clock_out   = 1 / T_clock_cycle = f_PCLK / samples_per_clock
```

where `samples_per_clock` is even and ≥ 2 (half low, half high).

### 3.2 PCLK choice for pixfrog

Criterion 1: cover WS2815 timing (T0H = 300 ns, T1H = 950 ns) with tight granularity.
Criterion 2: support useful APA102 CLOCK rates (≥ 1 MHz, ideally 6+ MHz).
Criterion 3: keep the DMA bus load below 30 % of PSRAM bandwidth.

**Chosen value**: `f_PCLK = 16 MHz`, so `T_PCLK = 62.5 ns`.

1-wire verification:

| Target (ns) | Ideal samples | Chosen samples | Realised (ns) | Error |
|---|---:|---:|---:|---:|
| T0H = 300 | 4.8 | 5 | 312.5 | +12.5 ns |
| T0L = 950 | 15.2 | 15 | 937.5 | −12.5 ns |
| T1H = 950 | 15.2 | 15 | 937.5 | −12.5 ns |
| T1L = 300 | 4.8 | 5 | 312.5 | +12.5 ns |
| TDATA | 20 | 20 (= T0H+T0L) | 1 250 | 0 |

→ `samples_per_bit = 20` for WS2815, total bit = 1 250 ns. ✓

Clocked verification:

```
samples_per_clock = 2   → f_clock = 8 MHz   (APA102 at 8 MHz, OK)
samples_per_clock = 4   → f_clock = 4 MHz
samples_per_clock = 8   → f_clock = 2 MHz
samples_per_clock = 16  → f_clock = 1 MHz
```

Reachable CLOCK range: **125 kHz to 8 MHz** in integer divisor steps. Plenty for real-world use (APA102 is reliable at 4–8 MHz on ~100 LED strings).

### 3.3 Other 1-wire protocols at PCLK = 16 MHz

| Protocol | T0H target | T1H target | Samples T0H | Samples T1H | Samples / bit | Max error |
|---|---:|---:|---:|---:|---:|---:|
| WS2815 | 300 | 950 | 5 | 15 | 20 | ±13 ns |
| WS2812B | 350 | 700 | 6 | 11 | 20 | ±25 ns |
| WS2811-fast  | 350 | 700 | 6 | 11 | 20 | ±25 ns |
| WS2811-slow  | 700 | 1 200 | 11 | 19 | 40 | ±25 ns |
| SK6812 | 300 | 600 | 5 | 10 | 19 (~1 187 ns) | ±13 ns |
| WS2814 | 300 | 950 | 5 | 15 | 20 | ±13 ns |

All errors are under the ±150 ns datasheet tolerance. ✓

---

## 4. DMA encoding (1-wire vs clocked)

The DMA buffer is a stream of 16-bit samples. In each sample, each bit is the state of one GPIO at that PCLK tick.

```
sample[t] = (CH8_CLOCK << 15) | (CH8_DATA << 14) | … | (CH1_CLOCK << 1) | CH1_DATA
```

### 4.1 1-wire NRZ encoding (WS2815, samples_per_bit = 20)

To encode a `1` on CH1_DATA:

```
sample[0]   : CH1_DATA = 1
sample[1]   : CH1_DATA = 1
…
sample[14]  : CH1_DATA = 1   // 15 HIGH samples = 937.5 ns ≈ T1H
sample[15]  : CH1_DATA = 0
…
sample[19]  : CH1_DATA = 0   // 5 LOW samples = 312.5 ns ≈ T1L
```

To encode a `0`:

```
sample[0]   : CH1_DATA = 1
…
sample[4]   : CH1_DATA = 1   // 5 HIGH samples = 312.5 ns ≈ T0H
sample[5]   : CH1_DATA = 0
…
sample[19]  : CH1_DATA = 0   // 15 LOW samples = 937.5 ns ≈ T0L
```

CH1_CLOCK stays 0 for all 20 samples (the CLOCK pin exists on the bus but is never connected to a 1-wire strip).

### 4.2 Clocked SPI-like encoding (APA102, samples_per_clock = 4 → 4 MHz)

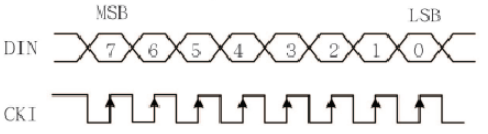
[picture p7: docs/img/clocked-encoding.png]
Clocked SPI-like encoding: DATA (DIN) is sampled on each CLOCK (CKI) rising edge, MSB first


To transmit 1 DATA bit clocked on 1 CLOCK cycle:

```
sample[0]   : CH1_CLOCK = 0, CH1_DATA = bit  // setup
sample[1]   : CH1_CLOCK = 0, CH1_DATA = bit  // setup
sample[2]   : CH1_CLOCK = 1, CH1_DATA = bit  // rising edge — strip latches
sample[3]   : CH1_CLOCK = 1, CH1_DATA = bit  // hold
```

APA102 byte sequence:

```
Start frame : 0x00 0x00 0x00 0x00                   (4 bytes, 32 bits → 32 CLOCK cycles)
Pixel       : 0xE0|brightness  +  B  +  G  +  R     (4 bytes per pixel)
End frame   : 0xFF × ceil(N/2)/8                    (propagation padding, see datasheet)
```

### 4.3 Latch / reset

For 1-wire protocols, after the last pixel, DATA must stay LOW for TRESET (≥ 280 µs for WS2815). At 16 MHz that's 4 480 zero samples. They sit at the tail of the frame buffer:

- **PARLIO TX** (default): the frame loops back-to-back, so the reset tail is what separates one repeat from the next — the strips re-latch every loop. The bus is never "parked"; it re-emits the same frame until a new buffer is mounted.
- **LCD_CAM** (legacy): once GDMA finishes the single emission, the bus stays parked on those trailing zeros until the next `esp_lcd_panel_draw_bitmap`.

For clocked protocols there's no latch — the bus simply repeats (PARLIO) or goes idle (LCD_CAM) after the end frame.

### 4.4 Single PSRAM frame buffer, no chunks

The encoder produces **one complete PSRAM frame buffer** per frame, not a chain of small chunks. The render task writes into a drained back buffer, flushes the cache (`esp_cache_msync`, DIR_C2M), hands it to the DMA engine, and GDMA streams the PSRAM directly without any CPU involvement. How many buffers and how the swap is armed differ per backend:

- **PARLIO TX** (default): **three** flat buffers, one mounted in loop transmission mode. `parlio_tx_unit_transmit` while looping concatenates the next buffer onto the tail of the running DMA link list, so it takes over at the next frame boundary, gapless. Loop mode marks no DMA EOF, so a retired buffer is known free only one frame duration after its swap was submitted. With only two buffers the one to reuse is exactly the one freed one frame ago (no slack) — a third buffer gives a full frame of drain so the encode of frame N+2 overlaps the wire emission of N and N+1 instead of serialising after it (`led_output/src/parlio_output.cpp`, `kNumFb = 3`).
- **LCD_CAM** (legacy): `esp_lcd_new_rgb_panel(flags.fb_in_psram = true, num_fbs = 2)`; `esp_lcd_panel_draw_bitmap` swaps the active FB pointer and a `vsync` callback releases the previous one.

Consequence for the encoder: **no sub-frame real-time deadline**. It has the full DMA emission window of the current frame (up to ~30 ms at 30 Hz with 1024 px WS2815) to produce the next one.

---

## 5. Mixed multi-channel strategy

All channels share the same PCLK = 16 MHz. Consequences:

- The 8 channels are emitted **in parallel** on the 16 bus bits; total DMA duration is dictated by the longest channel, not the sum.
- 1-wire duration  = `pixels × bits_per_pixel × samples_per_bit / f_PCLK + T_reset`
- Clocked duration = `(start_bytes + pixels × bytes_per_pixel + end_bytes) × 8 × samples_per_clock / f_PCLK`
- Shorter channels emit zero samples after their last useful bit (no effect on strips that have already latched).

### 5.1 Practical limits per protocol

Each protocol's bit-rate sets a physical floor that no software optimization can bypass. The refresh rate is any integer from 20 to 120 Hz (`config::kMinRefreshHz..kMaxRefreshHz`). The numbers below are the caps the firmware **computes and enforces** (`dmx::logic::max_pixels_for`): the largest `pixel_count` whose encoded frame fits both the emission budget (period − 1 ms encode-overlap reserve) and the DMA frame buffer, capped at 1024 px (512 slots for DMX, one universe).

| Protocol | Bit rate | Bits/px | 20 Hz | 30 Hz | 40 Hz | 50 Hz | 60 Hz | 120 Hz |
|---|---:|---:|---:|---:|---:|---:|---:|---:|
| WS2815 (RGB) | 800 kbps | 24 | 1024  | 1024  | 790 | 624 | **512** | 235  |
| WS2812B / WS2811 | 800 kbps | 24 | 1024  | 1024  | 798 | 631 | **520** | 242  |
| WS2814 (RGBW) | 800 kbps | 32 | 1024  | 801 | 593 | 468 | **384** | 176  |
| SK6812 (RGBW) | 800 kbps | 32 | 1024  | 848 | 629 | 497 | **410** | 190  |
| APA102 / SK9822 @ 4 MHz CLOCK | 4 Mbps | 32 | 1024* | 1024* | 1024* | 1024* | 1024* | 901 |
| LPD8806 @ 4 MHz CLOCK | 4 Mbps  | 24 | 1024* | 1024* | 1024* | 1024* | 1024* | 1024* |

Above 60 Hz the wire is the limit, not the CPU: measured on the board, the
encoder spends ≈ 23 µs per pixel row for 8 WS2815 outputs, so 8 × 235 px
encodes in ≈ 5.5 ms of the 8.3 ms 120 Hz period (encode overlaps emission).

\* Clocked at 4 MHz the bus clears the frame well inside the budget, so the 1024-px hard cap is reached first. WS2815 (RGB, 280 µs reset) caps lower than WS2812B/WS2811 (50 µs reset) despite the same bit rate.

Formula (LED): `max_pixels = floor( (period_µs − 1000 − T_reset_µs) / (bits_per_pixel × samples_per_bit / f_PCLK) )`, then clamped to the buffer and the 1024/512 ceiling. e.g. WS2815 @ 60 Hz: `(16666 − 1000 − 280) / 30 µs = 512`.

### 5.2 Worked example

8 channels × 600 px WS2815, in parallel = **600 × 24 × 20 / 16e6 = 18 ms of pure DMA**, plus 280 µs TRESET → **~18.3 ms per frame**.

- At 60 Hz (budget 16.67 ms): **does not fit**. The per-channel cap truncates each WS2815 channel to 512 px.
- At 30 Hz (budget 33.33 ms): comfortable, ~15 ms of slack left for encoding the next frame in parallel.

### 5.3 The emitted count is bounded, the stored count is not

The bus never clocks out more than fits in time, but the configured
`pixel_count` is left as set:

- `dmx::effective_channel(ch)` is the channel as emitted — its config with
  `pixel_count` limited to `dmx::channel_max_pixels(ch)` (the table above).
  Decode, scenes/failsafe, the encoder descriptor and the render pacing all go
  through it, so raising the refresh rate (or switching to a slower protocol
  or clock) drives fewer pixels, and lowering it again brings the full line
  back. Nothing is rewritten in NVS.
- `dmx::validate_capacity` flags a channel whose stored count is above its
  budget (`is_channel_capacity_ok(ch) = false`): `!` and a red count on HOME,
  `stored→emitted px` plus a warning in the web Outputs screen, a log line.
- The TFT pixel-count editor stays bounded to `channel_max_pixels(ch)` (the
  live ruler maps 1:1 to LEDs); the web UI and the console accept up to 1024
  (512 DMX slots) at any rate.

### 5.4 Dead pixels (gaps)

Up to 8 runs of dead physical LEDs per channel (`ChannelConfig::gaps`,
`led::PixelGap {pos, len}`): a sacrificial level-shift pixel at the head of a
line, a repeater or injector carrying an LED chip mid-line. They are wiring,
so they are indexed in physical order from the controller and never move with
`invert` or `grouping`.

- `pixel_count` counts **live** pixels: DMX data (and scenes, failsafe,
  identify) fill the live pixels only, so universe usage is unchanged.
- The encoder emits black on dead positions and shifts the live pixels past
  them (`detail::source_pixel`: gap lookup, then invert/grouping on the live
  index). Both the per-channel and the single-pass encoders go through it.
- The budget counts **physical** pixels: `max_pixels_for` is physical, and the
  live maximum the UIs show is `live_within(max_physical)` — at 60 Hz a WS2815
  line with 3 dead pixels carries 509 live ones.
- Gaps are normalized on every write (sorted, overlapping/adjacent runs
  merged, unused slots last). A gap starting past the end of the line is kept
  but costs nothing.
- The pixel-count ruler paints dead pixels dim red in place; while a gap is
  being edited on the TFT the ruler follows the pending value.
- Edit: web Outputs screen ("Fixtures & dead LEDs"), console
  `ch N gaps 1:1,301:2` (first dead LED, 1-based : count; `-` clears), TFT
  RIG → output menu → "Dead px". API/backup: `"gaps": [[first_led, count], ...]`.
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

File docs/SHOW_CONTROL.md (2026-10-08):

# Show control

Grand master, blackout and strobe, scene zones and crossfades, and the DMX
control universe that drives them from any lighting desk.

## Grand master, blackout, strobe

Three runtime controls sit after everything an output renders (network, scene,
FSEQ, failsafe). Each can target all outputs or a group:

| Control | Effect |
|---|---|
| Master | scales the output, 0–100 % (16-bit from the desk) |
| Blackout | output dark |
| Strobe | short flashes (≤ 30 ms) at 1–25 Hz |

They reset at reboot (full, lit, steady). Local values (web, TFT, UART,
ArtTrigger) and the desk's combine: the masters multiply, the blackouts add up,
and the faster strobe wins. Identify and the pixel-count ruler ignore all three,
so a strip can still be found during a blackout.
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

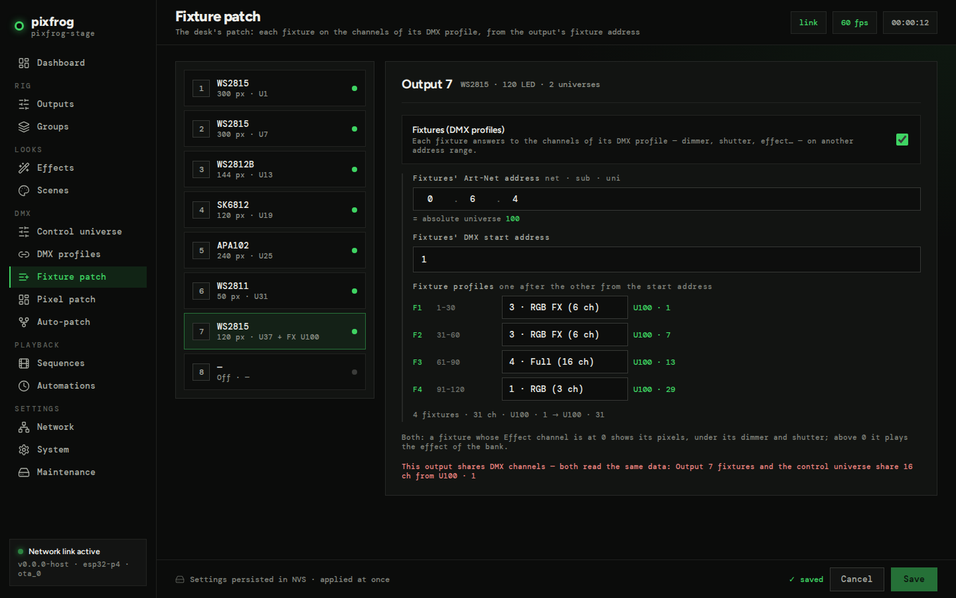
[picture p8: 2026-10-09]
docs/img/web-channel-control.png

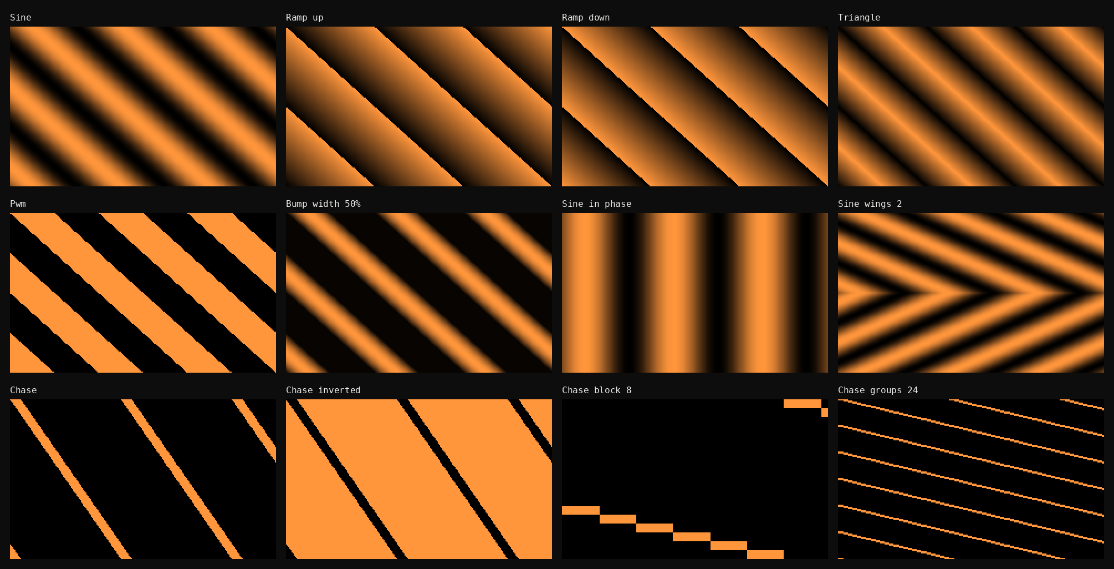
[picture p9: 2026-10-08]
docs/img/effects/layers-gallery.png

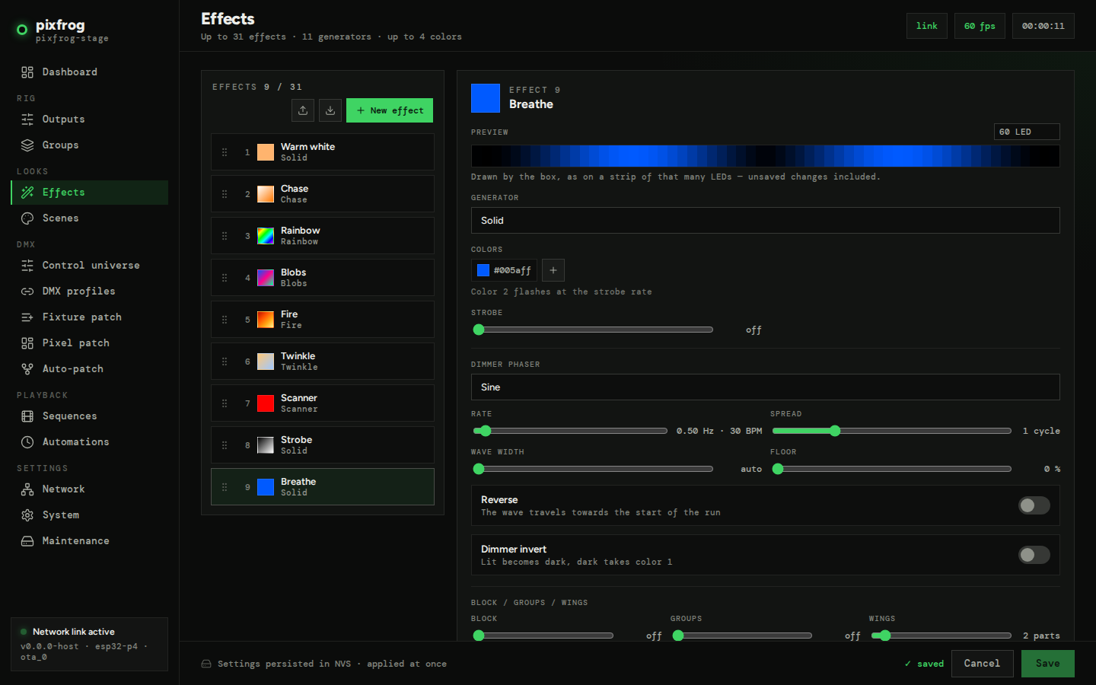
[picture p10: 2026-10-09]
docs/img/web-effects.png

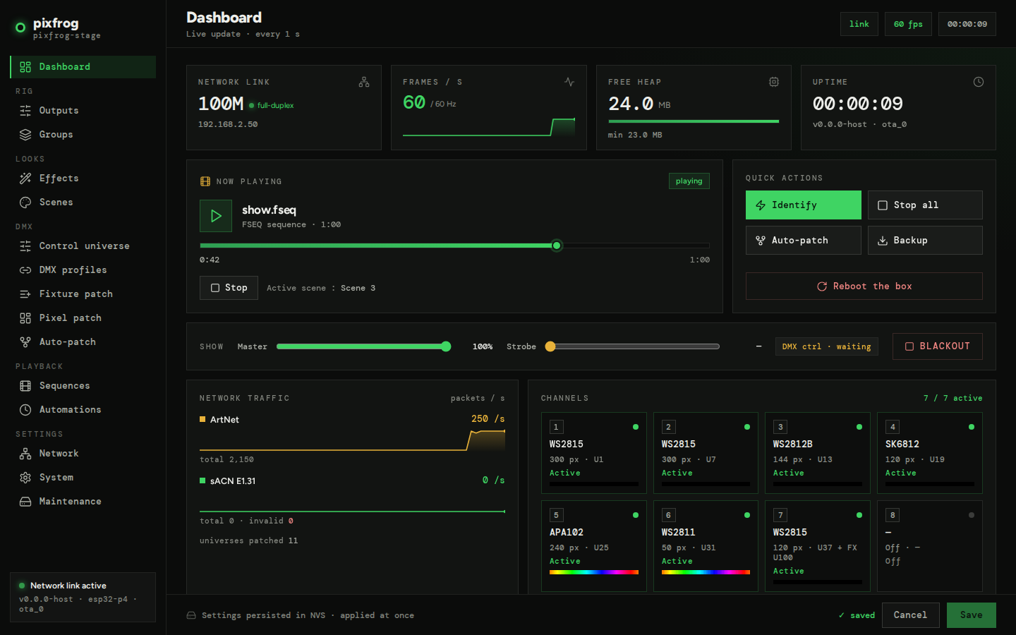
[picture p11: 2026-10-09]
docs/img/web-dashboard.png

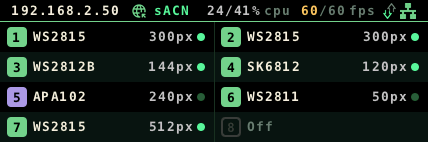
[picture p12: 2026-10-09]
docs/img/ui-nv3007-home.png

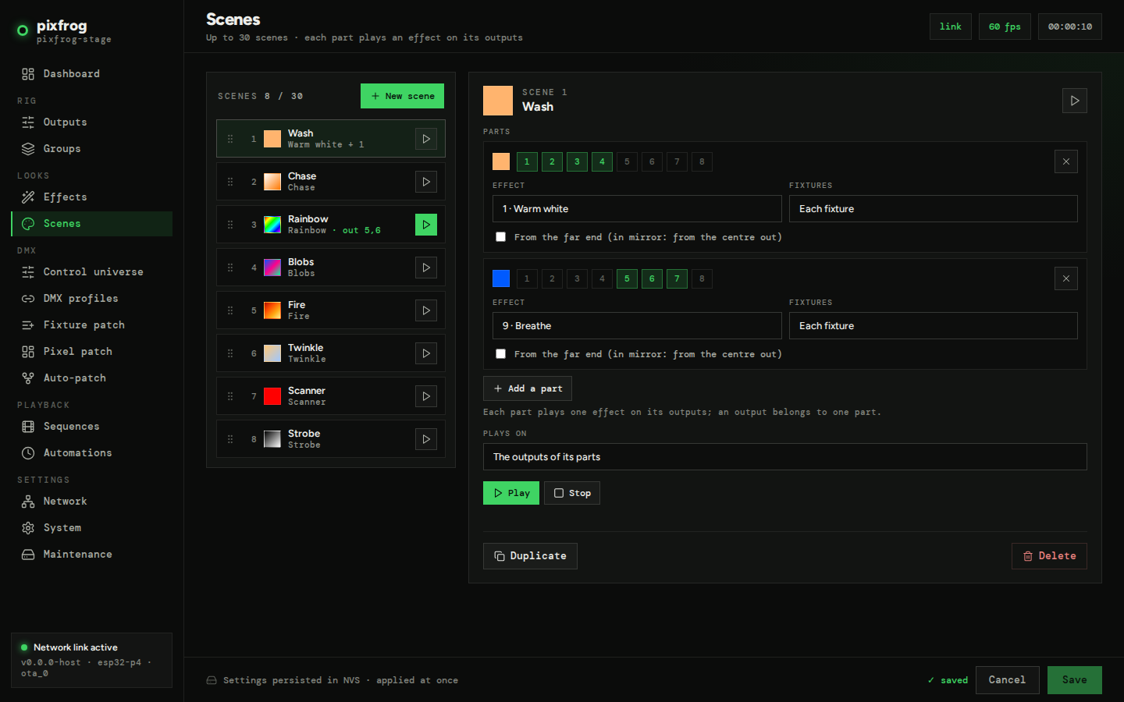
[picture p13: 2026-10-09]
docs/img/web-scenes.png

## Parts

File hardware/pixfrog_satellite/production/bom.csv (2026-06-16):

Designator | Footprint | Quantity | Value | LCSC Part #
C1 | 0805 | 1 | 100n
C2 | 0805 | 1 | 10u
C3 | 1210 | 1 | 10u
D1, D2, D3, D4 | D_SMA | 4 | SMAJ5.0CA
J1 | TerminalBlock_Phoenix_MKDS-1,5-2-5.08_1x02_P5.08mm_Horizontal | 1 | Screw_Terminal_01x02
J2 | TerminalBlock_Phoenix_MKDS-1,5-4-5.08_1x04_P5.08mm_Horizontal | 1 | Screw_Terminal_01x04
J3 | TerminalBlock_Phoenix_MKDS-1,5-3-5.08_1x03_P5.08mm_Horizontal | 1 | Screw_Terminal_01x03
J4 | JST_XH_B4B-XH-A_1x04_P2.50mm_Vertical | 1 | Conn_01x04
J5 | JST_XH_B2B-XH-A_1x02_P2.50mm_Vertical | 1 | fan_out
R1, R2 | 0805 | 2 | 33
R3, R4 | 0805 | 2 | 39
R5, R6 | 0805 | 2 | 249
U1 | SC-74-6_1.55x2.9mm_P0.95mm | 1 | 74LVC2G17
U2 | SOT-223-3_TabPin2 | 1 | LD1117S50TR_SOT223

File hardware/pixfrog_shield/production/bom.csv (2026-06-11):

Designator | Footprint | Quantity | Value | LCSC Part #
C1, C2 | 0603 | 2 | 100nF | C14663
C3 | 0805 | 1 | 10uF | C440198
D1, D10, D11, D12, D13, D14, D15, D16, D2, D3, D4, D5, D6, D7, D8, D9 | D_SMA | 16 | 5.0V | C10756
J1 | PinSocket_2x20_P2.54mm_Vertical | 1 | Conn_02x20 | C132132
J13 | PinHeader_1x09_P2.00mm_Vertical | 1 | Conn_01x09 | C22438283
J2, J3, J4, J5, J6, J7, J8, J9 | JST_XH_B3B-XH-A_1x03_P2.50mm_Vertical | 8 | Conn_01x04 | C144394
R1, R2, R3, R4, R5, R6, R7, R8 | 0805 | 8 | 249 | C32281
R10, R11, R12, R13, R14, R15, R16, R25, R26, R27, R28, R29, R30, R31, R32, R9 | 0805 | 16 | 39 | C17659
R17, R18, R19, R20, R21, R22, R23, R24 | 0805 | 8 | 33 | C17634
SW1, SW2 | SW_DIP_SPSTx08_Slide_KingTek_DSHP08TS_W7.62mm_P1.27mm | 2 | SW_DIP_08 | C5165730
U1, U2 | TSSOP-20_4.4x6.5mm_P0.65mm | 2 | 74HCT245 | C7494911

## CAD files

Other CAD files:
hardware/pixfrog_rack/pixfrog_rack.f3z

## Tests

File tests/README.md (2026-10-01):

# Host tests

Every host test runs from one CMake project, driven by ctest:

```bash
cmake -S tests -B build/tests && cmake --build build/tests --parallel
ctest --test-dir build/tests --output-on-failure        # all suites
build/tests/harness/harness_dmx_manager failsafe        # one binary, filtered cases
cmake -S tests -B build/tests-san -DPIXFROG_SANITIZE=ON # ASan + UBSan
python3 tools/coverage.py                               # whole-firmware coverage
```

## Layout

| Path | What |
|---|---|
| `components/*/test/` | Pure-logic suites (encoders, parsers, `dmx_logic.h`, layouts). Each still builds standalone. |
| `tests/shims/` | Host implementations of the IDF APIs the portable components call: fake clock (`esp_timer`, FreeRTOS ticks), in-memory NVS with fault injection, single-threaded FreeRTOS, real SHA-256, an in-process UDP fabric behind `lwip/sockets.h`, `esp_console` command table, an SD card backed by a host directory (`vfs_redirect.h` maps `/sdcard`), recording LED/LCD drivers (PARLIO TX, esp_lcd RGB + SPI panels with a GRAM model, GPIO, LEDC), and I2C device models the test attaches (`shim::i2c_attach`). Tests steer them through `shim_control.h`, including one-shot fault injection (`shim::fail_next`). |
| `tests/harness/` | The **real** firmware sources compiled against the shims — `config_store.cpp`, `dmx_manager.cpp`, `artnet.cpp`, `sacn.cpp`, `control_console.cpp`, `web_config.cpp`, `fseq_player.cpp` + `fpp_sync.cpp`, both LED output backends, the UI drivers and task loop once per display Kconfig (`harness_ui_*`), and `main.cpp` itself — `harness_boot` runs `app_main()` over every real module and drives the render task from an Art-Net packet to the PARLIO wire — one executable per area so their static state stays apart. `fakes/` stands in for modules a harness does not build. |
| `tests/web/` | `pixfrog_api_host`: the real `web_config` handlers and gzipped SPA served over TCP on the host (`--port N [--rollback] [--password P]`), and Playwright tests driving the SPA in Chromium against it. |
| `tests/third_party/cJSON/` | cJSON as vendored by ESP-IDF (MIT), for the web handlers. |
| `tests/fuzz/` | libFuzzer targets (`-DPIXFROG_FUZZ=ON`, clang): the wire parsers, the real Art-Net/sACN receive loops, the console table, the REST handlers. `corpus/<target>/` holds the seeds (`make_seeds.py` regenerates them). |
| `tools/emulator/crawl.py` | Walks every menu node of the UI emulator and compares golden screenshots (both panels). |

## REST API and SPA

`harness_web` calls the handlers in process with `shim::http_request("POST",
"/api/scenes", body)` — contract tests on status codes, JSON shape and the
device state behind it. The browser tests need the API host built:

```bash
pip install pytest playwright && python3 -m playwright install chromium
cmake --build build/tests --target pixfrog_api_host
python3 -m pytest tests/web -q
```

`@pytest.mark.device_args("--rollback")` starts a test's device with extra
flags.

## Writing a harness test

```cpp
#include "harness.h"
#include "shim_control.h"

TEST(failsafe_after_timeout) {
    // …drive the component…
    shim::advance_ms(2100);  // time only moves when the test says so
    EXPECT_EQ(value, 0);
}
```

- `TEST(name)` self-registers; `EXPECT_TRUE/FALSE/EQ/STREQ` keep going on failure.
- A blocking call (`xSemaphoreTake`, `vTaskDelay`) advances the fake clock by
  its timeout instead of sleeping.
- `xTaskCreate*` records the task; `shim::run_task("artnet_rx")` runs its body
  on the test thread. A receive loop returns once its socket queue is empty if
  the test registered `shim::net_on_idle(port, stop_fn)`.
- `shim::console_exec("ch 0 pixels 60", &out)` runs a console line as the UART
  REPL would and captures its output.
- `shim::run_task_for("sd_mon", n, step)` runs an endless task for `n` delays,
  calling `step` at each one — how the SD monitor and playback loops are driven.
- `shim::fail_next(shim::Fault::LcdDraw)` makes the next matching IDF call fail
  (`count`, `skip` to target the Nth); every error path is reachable that way.
- The LED backends are checked on what reaches the wire: `shim::parlio_log()` /
  `shim::lcd_log()` hold the last frame, decoded back to bytes by the tests.
- Prove a new test can fail: break the code it guards once (a quick mutation)
  and watch it go red — the bank-swap flicker and the failsafe-mask checks were
  verified that way.

## Fuzzing

```bash
tools/fuzz.sh 60                    # every target 60 s in parallel (CI job `fuzz`)
tools/fuzz.sh 600 fuzz_web_api      # one target, longer
build/tests-fuzz/fuzz/fuzz_web_api build/fuzz-artifacts/fuzz_web_api/crash-…  # replay
```

A crash leaves its input in `build/fuzz-artifacts/<target>/`. Turn it into a
harness test (see `out_of_range_numbers_are_ignored_not_wrapped` in
`test_web.cpp`, the first bug the fuzzer found), fix, and keep the input as a
seed. Under ctest the fuzz build only replays the seeds.

| Target | Input |
|---|---|
| `fuzz_parsers` | one buffer through every Art-Net, sACN, FPP and FSEQ-header parser |
| `fuzz_receivers` | byte 0 picks Art-Net/sACN and the source; datagrams split on `FF FE FD` |
| `fuzz_console` | one console line |
| `fuzz_web_api` | byte 0 route, byte 1 wildcard index + receive chunking, then the body |

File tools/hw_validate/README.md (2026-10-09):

# hw_validate — hardware regression suite

Replayable end-to-end validation of every feature **on the real board**,
grown from the one-shot scripts used during development. Run after any
flash (OTA or USB) to prove the device still behaves.

```bash
cd tools/hw_validate
./run_all.py                # everything except OTA (~3 min)
./run_all.py --with-ota     # + OTA round-trip (flashes the inactive slot)
./run_all.py scenes auth    # subset
./run_all.py --junit out/   # + out/<validator>.xml (JUnit, for a CI runner)
PORT=/dev/ttyACM1 BOARD_IP=10.0.0.5 ./run_all.py
```

| Validator | Proves |
|---|---|
| `artnet` | ArtDmx → universe pool → pixel decode (counter + pixr) |
| `sacn` | E1.31 unicast → pool → decode (opt-in flag honoured) |
| `failsafe` | never-active rule, colour fill, recovery, blackout, hold |
| `scenes` | generators, multi-colour blobs, solid strobe ends, channel mask, network priority, scene list add/rename/move/delete + persistence, ArtTrigger, boot scene |
| `show` | grand master / blackout / strobe (console + ArtTrigger KeyMacro), scene zones and crossfade, the DMX control universe over Art-Net (master, blackout, scene band, local stop holds, release when the desk goes silent), fixture profile |
| `output` | refresh bounds 20..120 Hz and the rate actually held, pixels above the budget kept, dead-pixel gaps (merge, persistence, logical pixels untouched) |
| `identify_gamma` | identify blink, gamma/wb readback, backup/restore round-trip |
| `fseq` | upload to SD, playback position/duration, console seek, ArtTimeCode seek, FPP MultiSync start/sync/stop/hot-join (needs a microSD in the board) |
| `display` | backlight level + idle dim + dim delay: console ranges, NVS persistence, web round-trip |
| `auth` | open-by-default, 401s, flat brute-force delay, UART recovery |
| `webops` | `/api/status` fields, gzipped SPA + ETag/304, mDNS: unique name + `pixfrog.local` alias (log, status, and a unicast query through `powershell.exe` when present), coredump cycle |
| `network` | the addressing applied without a reboot: a static address set from the console answers HTTP at once, a DHCP lease comes and is advertised, the box comes back to its own addressing (needs a DHCP server on the bench LAN) |
| `sacn_multicast` *(opt-in)* | E1.31 on the 239.255.x.y groups → decode; a universe re-config moves the join (5 s refresh) and drops the old group; the control universe on its group. `MCAST_FROM` = a sender on the board's LAN (from WSL the packets leave Windows through `mcast_send.ps1`) |
| `multiboard` *(opt-in)* | two boxes: peers, CORS, one `pixfrog.local` holder; the preferred box takes the alias, the sibling takes it back when the holder vanishes (≤ ~60 s); both `hub_preferred` restored. `OTHER_IP` = the sibling |
| `ota` | upload → slot swap → confirmation after 30 s of rendering; then a second upload reset before confirming → bootloader rollback, record on console + `/api/status`, web acknowledge (needs `build/pixfrog.bin`, ~3 min) |

Conventions (see `pixfrog_uart.py`):
- **One serial session per validator** — opening the port resets the board,
  so a validator never closes/reopens mid-run.
- Every validator **restores the board defaults** it touched (opt-in flags
  back to off, gamma to linear, …).
- UDP sends are **repeated/spread** — single datagrams behind a NAT
  routinely vanish on a cold ARP entry; treat one-packet tests as flaky.
- If `/dev/ttyACM0` vanishes after a replug, re-attach it to the test host
  (USB pass-through to a VM/container may need re-attaching).

The *opt-in* validators are not in `run_all`'s default list (they need a
sender on the LAN or a second box): `./run_all.py sacn_multicast multiboard`
with their variables set.

Not covered here: wire-level timing/levels (Saleae workflows — see the
repo skills).

## Wire-level checks (Saleae)

The validators above prove the chain as far as the pixel buffer, by reading the
board back over UART. They cannot see the encode/DMA path: a fault there leaves
`submits`, `current_fps` and `dma_underruns` all healthy while the bus sits
silent — PARLIO loop mode raises no completion event, so nothing in the firmware
contradicts itself. That is exactly how #74 shipped.

`nrz_decode.py` closes the gap by decoding what actually left the GPIO:

```bash
# 1. stream a known payload so any capture moment sees the same pixels
./artnet_stream.py --universe 1 --hex ff0102030405060708090a0b --seconds 25 &

# 2. capture the data line in Logic 2 (50 MS/s, 3.3 V) and
#    Export Raw Data -> CSV

# 3. decode it back and assert
./nrz_decode.py digital.csv --channel 0 --protocol ws2815 --pixels 4 \
    --expect ff0102030405060708090a0b
```

With dead-pixel gaps configured (`ch 0 gaps 2:1`), pass the same list to
`--gaps`: `--pixels`/`--expect` stay the logical strip and the decoder expects
the dark LEDs at their physical positions.

Which Saleae column carries which bus bit is wiring, not configuration —
establish it with `cal 1` (walking-1 across the 16 bits) rather than assuming.
`cal 0` (1 kHz square on all 16 GPIOs) is the fastest go/no-go: on a healthy
board every probed pin shows ~977 Hz.

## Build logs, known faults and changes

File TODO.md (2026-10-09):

# TODO — product roadmap

The open backlog, grouped by theme. Per [AGENT.md](AGENT.md), features land
only from this list. Suggested first picks are marked ★. Finished items are
removed; git history and the PRs keep the record (last cleanup: 2026-10-09).

DMX512 output left this firmware (PR #100): it lives in a DMX node firmware
forked at `d4f0f77`. DMX-output work (44 Hz pacing, ArtNzs routing, RDM)
belongs to that fork.

## Bugs & small fixes

- [ ] **Network silent after a USB-flash reset (seen once, 2026-09-30)** — link
      up + static IP but no ping/HTTP for about a minute; a UART reset fixed it.
      If it comes back, capture EMAC/PHY state and ARP from the PC before
      resetting.

## Show control & scenes

- [ ] **Scene vs network priority policy** — a playing scene overrides the
      network until stopped, and nothing tells the desk. Add a per-box policy:
      `override` (today) / `yield` (the scene is an idle look that stops when
      DMX arrives on its outputs, resumes on failsafe). Surface it in the
      ArtPollReply NodeReport and on HOME.
- [ ] **Per-scene fade time** — the fade is global (`scene_fade_ms`, desk
      overridable); a per-scene value takes the bytes reserved for it in
      `config::Scene`.
- [ ] **Shared scene clock across boxes** — each box animates from its own
      `esp_timer` phase, so neighbours drift. Share a phase origin (FPP
      MultiSync, ArtTrigger timestamp, or a small broadcast).
- [ ] **OSC input** — opt-in UDP OSC receiver (QLab, TouchDesigner):
      `/pixfrog/scene N`, `/pixfrog/master f`, `/pixfrog/blackout`,
      `/pixfrog/fseq/play name`.
- [ ] **GPIO trigger inputs** — debounced dry-contact inputs mapped to scene /
      sequence / stop / blackout (GPIO21 is free); museum and escape-room
      staple.
- [ ] **Time-of-day scheduling** — start/stop scenes or playlists on a
      schedule; needs opt-in SNTP and/or an RTC on the shield.

## Pro lighting control

Feedback from a lighting operator (GrandMA): drive the box like a conventional
fixture, not only as a pixel-mapped node. In landing order — each item builds
on the one before.

- [ ] ★ **GDTF export of a profile** — a native fixture file for GrandMA3, next
      to the OFL one.
- [ ] **Scene parts aimed at fixture groups** — on a group a scene plays its
      first part only; let each part target a group (across outputs, in the
      group's order) next to the parts on outputs, so one scene holds several
      effects on several groups.
- [ ] **Effects on the device menu** — fixtures and scenes are edited on the
      TFT / OLED; the effect bank (generator, colours, speed, phaser, Block /
      Groups / Wings) is still web / console only. A scene's part picks its
      effect by name, so a look cannot be tuned from the box.

## FSEQ / standalone playback

- [ ] **Pacing tied to the render clock** — the player paces on FreeRTOS
      ticks, independent of `render_task`: a 40 fps file on a 60 Hz render
      judders. Pick the FSEQ frame by elapsed time in the render loop.
- [ ] **Block handling** — O(n) block lookup + offset recompute per frame, and
      a whole ≤ 2 MB zstd block decompressed at once (can exceed a frame
      period). Precompute offsets, decompress the next block ahead of time.
- [ ] **FPP MultiSync tolerance** — `kToleranceMs = 100` is 4 frames at
      40 fps; slew the pacing clock for small drifts instead of seeking.
- [ ] **Audio with FSEQ** — play the sequence's media file in sync through the
      on-board ES8311 codec (I2C 0x18): a standalone mini-FPP.

## Network & protocols

- [ ] **Inter-controller frame sync (PTP)** — genlock several boxes (±µs) where
      no ArtSync master exists. The P4 EMAC does IEEE 1588v2 hardware
      timestamping and IDF ships the API + a master/slave example; feed the
      disciplined time into `render_task`'s `next_frame_us` deadline. Opt-in
      (`ptp_enabled`), free-run fallback, defined precedence vs ArtSync.
      Retire first on ≥ 2 boards: the known RMII_CLK ⇄ PSRAM issue at 200 MHz,
      and the IP101 clock prerequisites.
- [ ] **Art-Net opcodes** — `ArtCommand` (mirror the console `key=value`),
      `ArtDiagData` (diagnostics to subscribed controllers); `ArtFirmwareMaster`
      only for completeness (web OTA is better).

## Output & performance

- [ ] **Adaptive PCLK / sample density** — NRZ is encoded at 16 MHz with 20
      samples per bit where 3-4 at ~3.2 MHz suffice: frame buffers and
      PSRAM/DMA bandwidth are 5-6× larger than needed. Choose the density per
      frame from the protocol mix (clocked protocols keep 16 MHz).
- [ ] **Buffer sizes for longer lines** — at low refresh the wire allows more
      than the 1024 px cap (WS2815 @20 Hz ≈ 1600 px), but every buffer is
      sized from `kMaxPixelsPerChannel`: SRAM pixel buffers, the three PSRAM
      frame buffers (3 × 2.6 MB), the universe pool (`kNumUniverses` = 72),
      sACN joins, the UI editors. Pick a target (e.g. 2048 px) first; shrinks a
      lot with adaptive density.

## Hardware & bench

- [ ] **Physical DMX input** — RS-485 receive on the shield to drive the box
      without a network (hardware work).

## Tests & tooling

- [ ] **Spike: IDF `linux` target for integration tests** — FreeRTOS POSIX,
      real NVS on emulated flash, lwIP on host sockets; the portable components
      could run on the real IDF implementations. Unknown: `esp_http_server` has
      no linux support; cost: slower builds, no fake clock.

## Documentation & website

UI captures and the effect sheets are generated (`tools/screenshots`,
`tools/effects_gallery`): re-run them after a UI or effect change. *(owner)*
items need the hardware or CAD.

- [ ] *(owner)* **Mechanical renders, board renders, photos** — rack 1U and
      satellite renders, `pixfrog-shield.png` / `pixfrog-sat.png` from current
      KiCad, rack photos, site hero and `og-cover.png`, in-use shots.

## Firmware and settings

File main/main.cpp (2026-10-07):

// pixfrog — main entry point.
//
// Boot sequence:
//   1. NVS init + load config            (config_store)
//   2. Universe pool + pixel buffers     (dmx_manager)
//   3. LED bus output driver             (led_output)
//   4. UI (OLED + encoder)               (ui)
//   5. Network: Ethernet + lwIP (main::init_network), addressing (net)
//   6. ArtNet UDP receiver               (artnet)
//   7. frame pipeline: compose_task (core 0) + render_task (core 1)

#include "driver/gpio.h"
#include "esp_app_desc.h"
#include "esp_eth.h"
#include "esp_event.h"
#include "esp_ldo_regulator.h"
#include "esp_log.h"
#include "esp_mac.h"
#include "esp_netif.h"
#include "esp_ota_ops.h"
#include "esp_rom_sys.h"
#include "esp_system.h"
#include "esp_task_wdt.h"
#include "esp_timer.h"
#include "freertos/FreeRTOS.h"
#include "freertos/semphr.h"
#include "freertos/task.h"
#include "lwip/inet.h"
#include "nvs_flash.h"

#include <cstring>

#include "esp32_p4_devkit.h"

// OLED builds define no TFT geometry (Kconfig `depends on`); the two InitConfig
// fields are unused on that path.
#ifndef CONFIG_PIXFROG_TFT_WIDTH
#define CONFIG_PIXFROG_TFT_WIDTH 0
#define CONFIG_PIXFROG_TFT_HEIGHT 0
#endif

#include "artnet.h"
#include "audio.h"
#include "config_store.h"
#include "control_console.h"
#include "dmx_manager.h"
#include "fpp_sync.h"
#include "fseq_player.h"
#include "led_output.h"
#include "led_protocols.h"
#include "net.h"
#include "sacn.h"
#include "ui.h"
#include "web_config.h"

namespace {

constexpr const char* TAG = "MAIN";

esp_netif_t* g_eth_netif      = nullptr;
esp_eth_handle_t g_eth_handle = nullptr;

// What the box advertises: the UI's link / address / state and Art-Net's
// local address all follow the net component.
void publish_net(uint32_t host_order_ip, pixfrog::net::State st) {
    pixfrog::ui::set_link_up(st != pixfrog::net::State::Disconnected);
    pixfrog::ui::set_ip(host_order_ip);
    pixfrog::artnet::set_local_ip(host_order_ip);
    pixfrog::ui::set_net_state(
        st == pixfrog::net::State::Disconnected ? pixfrog::ui::NetState::Disconnected
        : st == pixfrog::net::State::Connected  ? pixfrog::ui::NetState::Connected
                                                : pixfrog::ui::NetState::Acquiring);
}

// Bring up the MAC + IP101 PHY, attach to a netif, apply
// static IP or wait for DHCP, register event handlers, start the driver.
// Failures are logged but never abort boot — the UI still works without
// a network link, so the user can fix the config from the panel.
void init_network() {
    esp_netif_init();
    esp_event_loop_create_default();

    esp_netif_config_t netif_cfg = ESP_NETIF_DEFAULT_ETH();
    g_eth_netif                  = esp_netif_new(&netif_cfg);
    if (!g_eth_netif) {
        ESP_LOGE(TAG, "esp_netif_new failed");
        return;
    }

    // MAC config — RMII, MDC/MDIO pins from the board file.
    eth_mac_config_t mac_cfg             = ETH_MAC_DEFAULT_CONFIG();
    mac_cfg.rx_task_stack_size           = 4096;
    eth_esp32_emac_config_t esp_emac_cfg = ETH_ESP32_EMAC_DEFAULT_CONFIG();
    esp_emac_cfg.smi_gpio.mdc_num        = pixfrog::board::kEthMdcGpio;
    esp_emac_cfg.smi_gpio.mdio_num       = pixfrog::board::kEthMdioGpio;
    esp_eth_mac_t* mac                   = esp_eth_mac_new_esp32(&esp_emac_cfg, &mac_cfg);
    if (!mac) {
        ESP_LOGE(TAG, "esp_eth_mac_new_esp32 failed");
        return;
    }

    eth_phy_config_t phy_cfg = ETH_PHY_DEFAULT_CONFIG();
    phy_cfg.phy_addr         = pixfrog::board::kEthPhyAddress;
    phy_cfg.reset_gpio_num   = pixfrog::board::kEthPhyResetGpio;
    esp_eth_phy_t* phy       = esp_eth_phy_new_ip101(&phy_cfg);
    if (!phy) {
        ESP_LOGE(TAG, "esp_eth_phy_new_ip101 failed");
        return;
    }

    esp_eth_config_t eth_cfg = ETH_DEFAULT_CONFIG(mac, phy);
    if (esp_eth_driver_install(&eth_cfg, &g_eth_handle) != ESP_OK) {
        ESP_LOGE(TAG, "esp_eth_driver_install failed");
        return;
    }

    esp_netif_attach(g_eth_netif, esp_eth_new_netif_glue(g_eth_handle));

    // Static or DHCP, the link and address events: the net component, which
    // the web, the console, the menu and ArtIpProg also call to re-address
    // the box live.
    pixfrog::net::init(g_eth_netif, publish_net);

    if (esp_eth_start(g_eth_handle) != ESP_OK) {
        ESP_LOGE(TAG, "esp_eth_start failed");
        return;
    }
    ESP_LOGI(TAG, "Ethernet started");
}

// ── The frame pipeline ──────────────────────────────────────────────────────
// compose_task (core 0) makes frame N+1 — universes swapped, the control
// universe read, every output drawn (scenes, effects, groups, fixtures) into
// the pixel back buffers — while render_task (core 1) encodes frame N from the
// fronts and hands it to the DMA. Drawing and encoding each get a core, so a
// frame costs the longer of the two instead of their sum. The fronts change
// hands through two binary semaphores: compose publishes (swaps every output's
// pixels) only once the encoder is done reading them, then says a frame is
// ready. All the drawing state (clocks, fades, the plays' snapshot) stays with
// one task, compose, as it stayed with render before.
SemaphoreHandle_t g_frame_ready = nullptr;  // a composed frame waits in the fronts
SemaphoreHandle_t g_fronts_free = nullptr;  // the encoder is done with the fronts

// The longest a pipeline task blocks before it kicks the watchdog and looks
// again: a stalled partner shows as a frozen frame rate, not a reset.
constexpr TickType_t kPipelineWaitTicks = pdMS_TO_TICKS(200);

void compose_task(void*) {
    // On the task watchdog too: a compose that stops is as dark as a render
    // that stops.
    esp_task_wdt_add(nullptr);

    // Drift-corrected emission deadline (µs). Advancing it by exactly one period
    // each frame keeps the long-run rate at refresh_rate_hz with no integer-ms
    // truncation, and makes refresh_rate_hz a hard ceiling: ArtSync may wake the
    // wait early but we never emit before the deadline, so the observed frame
    // rate can't climb above the configured setting (which sizes the DMA budget).
    int64_t next_frame_us = esp_timer_get_time();

    // The longest decode of the window, and of the one before (shown while
    // this one fills). Static: the host harness restarts the task body.
    static int64_t window_start_us  = esp_timer_get_time();
    static uint32_t decode_max_us   = 0;
    static uint32_t decode_max_last = 0;
#if configGENERATE_RUN_TIME_STATS
    // Core 0's load, read here on core 0: FreeRTOS only adds to the idle
    // task's run time when it is switched out, and it just made way for us.
    // (render_task reads core 1's.)
    static configRUN_TIME_COUNTER_TYPE idle_at = ulTaskGetIdleRunTimeCounterForCore(0);
#endif

    while (true) {
        // Recompute the period every frame so a UI commit of
        // refresh_rate_hz takes effect on the next frame without a reboot.
        const uint8_t rate_hz   = pixfrog::config::get_global().refresh_rate_hz;
        const int64_t period_us = rate_hz ? (1'000'000LL / rate_hz) : 33'333LL;
        // Apply any config changes committed by the UI since the
        // last frame. Rebuilds universe→channel LUT, clears dirty bits.
        // No-op when nothing is pending.
        pixfrog::dmx::handle_pending_remaps();

        pixfrog::dmx::swap_universes();
        // The DMX control universe (master, blackout, strobe, scenes, fades)
        // reads the bank just published.
        pixfrog::dmx::update_show_control();

        // Decode each channel's universes into its pixel back buffer (DMX
        // start offset, multi-universe spanning) — or the scene, the effects,
        // the fixtures it shows. Per-pixel transformations (color order,
        // brightness, grouping, invert) are applied later by
        // led::encode_channel during the frame encode. A calibration pattern
        // replaces the frame on the encoder's side: nothing to draw.
        if (pixfrog::output::get_calibration_mode() < 0) {
            const int64_t decode_from = esp_timer_get_time();
            for (size_t ch = 0; ch < pixfrog::config::kNumChannels; ++ch)
                pixfrog::dmx::decode_pixels_for_channel(ch);
            const auto decode_us = static_cast<uint32_t>(esp_timer_get_time() - decode_from);
            if (decode_us > decode_max_us) decode_max_us = decode_us;
            pixfrog::dmx::set_decode_time(
                decode_us, decode_max_us > decode_max_last ? decode_max_us : decode_max_last);
        }
        const int64_t now_us = esp_timer_get_time();
        if (now_us - window_start_us >= 1'000'000) {
#if configGENERATE_RUN_TIME_STATS
            const configRUN_TIME_COUNTER_TYPE idle = ulTaskGetIdleRunTimeCounterForCore(0);
            pixfrog::dmx::set_cpu_load(
                0, pixfrog::dmx::cpu_load_pct(static_cast<uint32_t>(idle - idle_at),
                                              static_cast<uint32_t>(now_us - window_start_us)));
            idle_at = idle;
#endif
            decode_max_last = decode_max_us;
            decode_max_us   = 0;
            window_start_us = now_us;
        }

        // Hand the frame over once the encoder has let go of the fronts.
        while (xSemaphoreTake(g_fronts_free, kPipelineWaitTicks) != pdTRUE)
            esp_task_wdt_reset();
        pixfrog::dmx::publish_pixels();
        xSemaphoreGive(g_frame_ready);
        esp_task_wdt_reset();

        // Pace to the next deadline. ArtSync wakes the wait early, but the loop
        // re-checks the deadline and keeps waiting until it passes: a sync aligns
        // the emit to the controller without ever pushing the rate above
        // refresh_rate_hz (the hard ceiling that protects the DMA budget).
        //
        // Never pace faster than the frame physically emits, either: a channel
        // whose wire time exceeds the period (a long strip at a high refresh)
        // must emit intact at its own rate rather than be over-submitted. The interval is
        // max(period, longest channel).
        const int64_t emit_us      = static_cast<int64_t>(pixfrog::dmx::frame_emit_us());
        const int64_t interval_us  = period_us > emit_us ? period_us : emit_us;
        next_frame_us             += interval_us;
        int64_t pace_us            = esp_timer_get_time();
        // A slow frame that overran a whole interval must not spiral into a burst
        // of catch-up frames — resync the deadline to now instead.
        if (pace_us - next_frame_us > interval_us) next_frame_us = pace_us;
        bool waited = false;
        while (pace_us < next_frame_us) {
            const TickType_t wait = pdMS_TO_TICKS((next_frame_us - pace_us + 999) / 1000);
            pixfrog::dmx::wait_for_sync_or_period(wait ? wait : 1);
            pace_us = esp_timer_get_time();
            waited  = true;
        }
        // Drawing longer than the period leaves no wait at all: give core 0 a
        // tick anyway, or the UI, the console and the idle task (its watchdog)
        // starve behind compose. The frame rate drops instead.
        if (!waited) vTaskDelay(1);
    }
}

void render_task(void*) {
    // Subscribe the render task to the task watchdog. The render
    // task is the canary for "the system is still meeting its real-time
    // budget" — if it stops kicking the WDT, we'd rather panic-reset than
    // ship dark/garbled frames silently.
    esp_task_wdt_add(nullptr);

    // Rolling 1-second window FPS counter, and core 1's idle time at its start
    // (the CPU load). Static: the host harness restarts the task body.
    static int64_t fps_window_start_us = esp_timer_get_time();
#if configGENERATE_RUN_TIME_STATS
    configRUN_TIME_COUNTER_TYPE idle_at = ulTaskGetIdleRunTimeCounterForCore(1);
#endif
    static uint32_t fps_frames_in_window = 0;

    while (true) {
        // The next composed frame. None for a while (compose stalled, or
        // pacing a slow refresh): kick the watchdog and wait again.
        if (xSemaphoreTake(g_frame_ready, kPipelineWaitTicks) == pdTRUE) {
            // When the UI has selected a calibration pattern, the
            // render loop emits that pattern instead of pixel data. This
            // makes scope debugging persistent across many frames without
            // requiring a recompile.
            const int8_t cal_mode = pixfrog::output::get_calibration_mode();
            if (cal_mode >= 0)
                pixfrog::output::emit_calibration_pattern(static_cast<uint8_t>(cal_mode));
            else
                pixfrog::output::render_frame();
            // Encoded: compose may publish the next frame into the fronts.
            xSemaphoreGive(g_fronts_free);
            fps_frames_in_window++;
        }

        // Publish FPS once per second.
        const int64_t now_us = esp_timer_get_time();
        if (now_us - fps_window_start_us >= 1'000'000) {
            pixfrog::dmx::set_current_fps(fps_frames_in_window);
#if configGENERATE_RUN_TIME_STATS
            // Core 1's load, read here on core 1 (compose_task reads core 0's).
            const configRUN_TIME_COUNTER_TYPE idle = ulTaskGetIdleRunTimeCounterForCore(1);
            pixfrog::dmx::set_cpu_load(
                1, pixfrog::dmx::cpu_load_pct(static_cast<uint32_t>(idle - idle_at),
                                              static_cast<uint32_t>(now_us - fps_window_start_us)));
            idle_at = idle;
#endif
            fps_frames_in_window = 0;
            fps_window_start_us  = now_us;
        }

        // Kick the WDT. If render_frame ever blocks past the WDT timeout
        // (5 s default), we want a clean panic.
        esp_task_wdt_reset();
    }
}

}  // namespace

// On the Waveshare ESP32-P4 module, the VDD_IO_5 pad domain (GPIO39-48 —
// carries LED bus CH5 CLOCK and CH7 DATA/CLOCK) is wired to the P4's internal
// LDO output VO4, not to 3.3 V. Left unprogrammed, VO4 idles near 1.2 V and
// those outputs swing 0-1.2 V instead of 0-3.3 V (measured on GPIO47).
// Acquire the channel at 3.3 V before any LED output starts and never
// release it. VDD_IO_6 (GPIO49-54) is tied to 3.3 V on the module and needs
// nothing.
void power_vdd_io5_pads() {
    esp_ldo_channel_config_t cfg = {
        .chan_id    = 4,
        .voltage_mv = 3300,
        .flags      = {},
    };
    static esp_ldo_channel_handle_t s_chan = nullptr;
    const esp_err_t err                    = esp_ldo_acquire_channel(&cfg, &s_chan);
    if (err != ESP_OK) {
        ESP_LOGE(TAG, "LDO VO4 acquire failed (%s) — GPIO39-48 stuck at ~1.2V",
                 esp_err_to_name(err));
    } else {
        ESP_LOGI(TAG, "LDO VO4 → 3.3V (VDD_IO_5 pads GPIO39-48)");
    }
}

// The speaker needs the R52 mod (docs/HARDWARE.md §2.7): stock, GPIO53 (LED
// CH8 DATA) drives the amp enable through R52 (0 Ω) into R58, 10 kΩ to
// ground, so the amp would follow the LED data. With R52 removed the pin sees
// only the CH8 line driver input: the internal pull-up (~45 kΩ) reads it high,
// where the stock 10 kΩ divider holds it near 0.6 V, low. Probed before the
// LED outputs take the pin. (It cannot see the PA_CTRL pull-up itself.)
bool speaker_mod_present() {
    const int pin         = pixfrog::board::kAmpProbeGpio;
    const gpio_config_t c = {
        .pin_bit_mask = 1ULL << pin,
        .mode         = GPIO_MODE_INPUT,
        .pull_up_en   = GPIO_PULLUP_ENABLE,
        .pull_down_en = GPIO_PULLDOWN_DISABLE,
        .intr_type    = GPIO_INTR_DISABLE,
    };
    gpio_config(&c);
    esp_rom_delay_us(200);
    const bool high = gpio_get_level(static_cast<gpio_num_t>(pin)) == 1;
    gpio_reset_pin(static_cast<gpio_num_t>(pin));
    ESP_LOGI(TAG, "speaker: R52 %s (GPIO%d reads %s)", high ? "removed" : "fitted — stock board",
             pin, high ? "high" : "low");
    return high;
}

// A new OTA image boots "pending verify": if it resets before confirming
// itself, the bootloader marks it invalid and boots the previous slot. That is
// the only trace of a rollback, so turn it into a logged, persisted record the
// web UI and the console can show until someone acknowledges it.
// Fixed-size, possibly unterminated IDF strings → a terminated, truncated copy.
void copy_field(char* dst, size_t cap, const char* src, size_t src_cap) {
    const size_t n = strnlen(src, src_cap);
    const size_t k = n < cap - 1 ? n : cap - 1;
    std::memcpy(dst, src, k);
    dst[k] = '\0';
}
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
extern "C" void app_main() {
    // Capture logs from the very first line so the web Diagnostics tab has the
    // boot log even when the web server stays disabled (tees to UART as usual).
    pixfrog::web::init_log_capture();
    ESP_LOGI(TAG, "pixfrog booting on %s", pixfrog::board::kBoardName);

    power_vdd_io5_pads();

    pixfrog::config::init();
    record_rollback_if_any();
    if (!pixfrog::dmx::init()) {
        ESP_LOGE(TAG, "dmx_manager init failed — aborting");
        return;
    }

    {
        pixfrog::fseq::InitConfig sd_cfg;
        sd_cfg.clk_gpio   = pixfrog::board::kSdmmcClkGpio;
        sd_cfg.cmd_gpio   = pixfrog::board::kSdmmcCmdGpio;
        sd_cfg.d0_gpio    = pixfrog::board::kSdmmcD0Gpio;
        sd_cfg.d1_gpio    = pixfrog::board::kSdmmcD1Gpio;
        sd_cfg.d2_gpio    = pixfrog::board::kSdmmcD2Gpio;
        sd_cfg.d3_gpio    = pixfrog::board::kSdmmcD3Gpio;
        sd_cfg.power_gpio = pixfrog::board::kSdPowerGpio;
        pixfrog::fseq::init(sd_cfg);
    }

    const bool speaker_ok = speaker_mod_present();

    pixfrog::output::InitConfig out_cfg{
        .bus_gpio_16           = pixfrog::board::kLedBusGpio,
        .pclk_hz               = pixfrog::led::kPclkHz,
        .max_samples_per_frame = pixfrog::led::kMaxSamplesPerFrame,
    };
    if (!pixfrog::output::init(out_cfg)) {
        ESP_LOGE(TAG, "led_output init failed — aborting");
        return;
    }

    pixfrog::ui::InitConfig ui_cfg{
        .i2c_port           = pixfrog::board::kI2cPort,
        .i2c_sda_gpio       = pixfrog::board::kI2cSdaGpio,
        .i2c_scl_gpio       = pixfrog::board::kI2cSclGpio,
        .i2c_freq_hz        = pixfrog::board::kI2cFreqHz,
        .encoder_addr       = pixfrog::board::kEncoderI2cAddr,
        .oled_addr          = pixfrog::board::kOledI2cAddr,
        .spi_host           = pixfrog::board::kDisplaySpiHost,
        .spi_clk_gpio       = pixfrog::board::kDisplayClkGpio,
        .spi_mosi_gpio      = pixfrog::board::kDisplayMosiGpio,
        .spi_cs_gpio        = pixfrog::board::kDisplayCsGpio,
        .tft_dc_gpio        = pixfrog::board::kDisplayDcGpio,
        .tft_rst_gpio       = pixfrog::board::kDisplayRstGpio,
        .spi_freq_hz        = pixfrog::board::kDisplaySpiFreqHz,
        .tft_width          = CONFIG_PIXFROG_TFT_WIDTH,   // landscape logical size — the
        .tft_height         = CONFIG_PIXFROG_TFT_HEIGHT,  // panel driver owns the rotation
        .tft_backlight_gpio = pixfrog::board::kDisplayBacklightGpio,
    };
    pixfrog::ui::start(ui_cfg);

    // Speaker: the ES8311 shares the UI's I2C bus. No codec = no sound, nothing else.
    pixfrog::audio::InitConfig audio_cfg{};
    audio_cfg.i2c_bus    = pixfrog::ui::i2c_bus();
    audio_cfg.codec_addr = pixfrog::board::kCodecI2cAddr;
    audio_cfg.mclk_gpio  = pixfrog::board::kI2sMclkGpio;
    audio_cfg.bclk_gpio  = pixfrog::board::kI2sBclkGpio;
    audio_cfg.ws_gpio    = pixfrog::board::kI2sWsGpio;
    audio_cfg.dout_gpio  = pixfrog::board::kI2sDoutGpio;
    audio_cfg.din_gpio   = pixfrog::board::kI2sDinGpio;
    audio_cfg.volume     = [] {
        return pixfrog::config::speaker_volume_pct(pixfrog::config::get_global());
    };
    // The UI plays the boot croak near the end of its splash.
    if (speaker_ok) pixfrog::ui::set_speaker_present(pixfrog::audio::init(audio_cfg));

    init_network();
    pixfrog::artnet::start();

    // Many sACN universes outgrow the EMAC's multicast filter: pass them all.
    pixfrog::sacn::set_multicast_overflow_hook([](bool pass_all) {
        if (g_eth_handle) esp_eth_ioctl(g_eth_handle, ETH_CMD_S_ALL_MULTICAST, &pass_all);
    });
    if (pixfrog::config::get_global().sacn_enabled) pixfrog::sacn::start();
    if (pixfrog::config::get_global().fpp_remote) pixfrog::fpp::start();
    if (pixfrog::config::get_global().boot_scene > 0)
        pixfrog::dmx::scene_start_on(pixfrog::config::get_global().boot_scene - 1,
                                     pixfrog::dmx::kAllOutputs, 0);  // lit at once
    if (pixfrog::config::get_global().web_enabled) pixfrog::web::start();

    // The frame pipeline: compose on core 0, just under the receivers (Art-Net
    // and sACN at 10, the EMAC and lwIP above) so a burst of universes is never
    // held back by drawing; encode alone on core 1.
    g_frame_ready = xSemaphoreCreateBinary();
    g_fronts_free = xSemaphoreCreateBinary();
    if (!g_frame_ready || !g_fronts_free) {
        ESP_LOGE(TAG, "frame pipeline semaphores: out of memory");
        return;
    }
    xSemaphoreGive(g_fronts_free);  // nothing encoding yet
    // render only encodes now (~3 kB used on the bench): internal RAM is what
    // the output's DMA lists need.
    xTaskCreatePinnedToCore(render_task, "render", 4608, nullptr, 20, nullptr, 1);
    xTaskCreatePinnedToCore(compose_task, "compose", 4096, nullptr, 9, nullptr, 0);

    pixfrog::console::start();

    const esp_partition_t* running = esp_ota_get_running_partition();
    esp_ota_img_states_t ota_state;
    if (esp_ota_get_state_partition(running, &ota_state) == ESP_OK &&
        ota_state == ESP_OTA_IMG_PENDING_VERIFY) {
        ESP_LOGI(TAG, "OTA image on %s pending verification (%u s)", running->label,
                 static_cast<unsigned>(kOtaConfirmDelayMs / 1000));
        xTaskCreatePinnedToCore(ota_confirm_task, "ota_confirm", 3072, nullptr, 3, nullptr, 0);
    }

    ESP_LOGI(TAG, "boot complete (%s)", running->label);
}

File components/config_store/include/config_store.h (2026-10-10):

// config_store — persistent configuration for pixfrog.
//
// Blobs, each its own NVS key (a grown struct loads zero-filled):
//   GlobalConfig   : network, Art-Net identity, refresh, services, display…
//   ChannelConfig  : per-LED-channel settings (×8)
//   EffectBank     : the looks (generator, palette, phaser, MAtricks)
//   SceneBank      : the standalone scenes — which effect plays where
//   ControlConfig  : the DMX control universe
//   FseqPlaylist   : the FSEQ playlist
//
// init() loads everything into a RAM cache. get_*() return references into
// that cache (no NVS access, safe from the render path); set_*() update the
// cache then write the blob through.
//
// Concurrency: every setter (and every scene-list edit) takes one recursive
// config lock, so two writers never interleave inside a struct. A caller's
// read-modify-write (get → change a field → set) wraps itself in a
// ScopedLock so another task's write cannot land in between and be lost. The
// render task copies the scenes it draws with copy_scene() (under the lock),
// never through a reference a list edit could memmove under it.

#pragma once

#include <array>
#include <cstddef>
#include <cstring>
#include <stdint.h>

#include "led_protocols.h"

namespace pixfrog::config {

constexpr size_t kNumChannels = 8;
constexpr size_t kMaxGroups   = 16;  // fixture groups (GroupsConfig below)

constexpr size_t kArtnetNameShortMax = 18;
constexpr size_t kArtnetNameLongMax  = 64;

// ────────────────────────────────────────────────────────────────────────────
// Network + ArtNet identity
// ────────────────────────────────────────────────────────────────────────────

struct GlobalConfig {
    // Network
    bool use_dhcp;
    uint32_t static_ip;  // host-order; 0 if use_dhcp
    uint32_t static_mask;
    uint32_t static_gateway;

    // ArtNet identity
    // Unused: each output holds a full 15-bit Port-Address. Kept for the blob layout.
    uint8_t artnet_net;
    uint8_t artnet_subnet;
    char short_name[kArtnetNameShortMax];
    char long_name[kArtnetNameLongMax];
    bool artnet_poll_reply_unicast;  // false=broadcast (default), true=unicast to poller

    // System
    uint8_t refresh_rate_hz;  // kMinRefreshHz..kMaxRefreshHz
    uint16_t home_timeout_s;  // 30 by default

    // Web UI — opt-in; no TCP socket opened when false (default)
    bool web_enabled;

    // sACN (E1.31) receiver — opt-in; no UDP socket opened when false (default)
    bool sacn_enabled;

    // Web UI admin password — salted SHA-256, never stored in clear.
    // hash all-zero = no password set = auth disabled (the default).
    uint8_t web_auth_salt[8];
    uint8_t web_auth_hash[32];  // see web_auth_kdf

    // Signal-loss failsafe — global setting, triggered per channel when no
    // packet touched any of its universes for failsafe_timeout_s. Zero-fill
    // migration = Hold + disabled = today's behaviour.
    uint8_t failsafe_mode;        // 0=hold last look, 1=blackout, 2=solid colour, 3=scene
    uint16_t failsafe_timeout_s;  // 0 = failsafe disabled
    uint8_t failsafe_r;           // solid-colour fill (mode 2)
    uint8_t failsafe_g;
    uint8_t failsafe_b;

    // Standalone scenes hooks (zero-fill migration = none/0).
    // Both follow their scene when the list is reordered (remap_scene_index).
    uint8_t boot_scene;      // 0 = none, N = play scene N-1 at boot
    uint8_t failsafe_scene;  // scene index used by failsafe mode 3

    // 2-source merge policy when two senders feed one universe. Zero-fill
    // migration = HTP, the Art-Net default. Settable via ArtAddress too.
    uint8_t merge_mode;  // 0 = HTP (per-slot max), 1 = LTP (last frame wins)

    // FPP MultiSync remote — opt-in; when true the box follows an FPP/xSchedule
    // master (UDP 32320): start/stop/seek of local FSEQ files. Zero-fill
    // migration = false (no socket opened).
    bool fpp_remote;

    // Web UI display language. Zero-fill migration = 0 = English (the default).
    uint8_t language;  // 0 = English, 1 = French

    // TFT backlight (ignored on OLED builds). All three zero-fill to the
    // behaviour that predates dimming: full brightness, never dimmed.
    uint8_t tft_brightness;    // 10..100 % of full backlight; 0 = unset = 100
    uint8_t tft_idle_dim;      // % dimmer once idle; 0 = never dim
    uint16_t tft_dim_delay_s;  // inactivity before dimming; 0 = never dim

    // Crossfade when a scene starts, stops or replaces another on an output.
    // Zero-fill migration = 0 = instant, the behaviour before fades.
    uint16_t scene_fade_ms;  // 0..kMaxSceneFadeMs

    // Address taken in DHCP mode when no DHCP server answers. Zero-fill
    // migration = link-local, the behaviour it shipped with.
    uint8_t ip_fallback;  // kIpFallback*
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

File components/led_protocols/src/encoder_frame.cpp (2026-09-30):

// Single-pass frame encoder.
//
// Per-channel encode_channel passes are read-modify-write traversals of the
// whole frame region: 8 NRZ channels cost 8 full PSRAM round-trips plus a
// memset, which alone busts the 60 FPS budget. This encoder merges every NRZ
// channel into ONE traversal of pure stores (the buffer needs no pre-zeroing),
// then ORs the compact clocked channels on top. PSRAM traffic per frame is
// one buffer write regardless of channel count.
//
// NRZ channels sharing the same samples_bit are swept bit-synchronously: for
// each bit time, the 16-bit bus word changes only at a handful of "edges"
// (the distinct T0H/T1H values plus the bit boundary), so each bit time is a
// few constant-word fills. Channels with a different samples_bit (SK6812 is
// 19 where WS281x are 20) form a second group, OR-ed over the stored one.
//
// The group with the largest extent gets the pure-store pass; the others are
// OR-ed over it, paying read-modify-write only on their own (smaller) span.

#include <cstring>

#include "encoder_nrz.h"
#include "encoder_spi.h"
#include "led_protocols.h"

namespace pixfrog::led {

namespace {

// 16-bit bus = 8 data+clock pairs, so at most 8 simultaneous channels.
constexpr size_t kMaxChannels = 8;

// One NRZ channel inside a sweep group: timing constants plus a lazy cursor
// over the transformed (wire-order, brightness, grouping, invert) bit stream.
struct NrzChan {
    const ChannelDesc* d;
    const uint8_t* pixels;
    uint16_t mask;
    uint16_t t0h;
    uint16_t t1h;
    uint32_t total_bits;
    size_t bytes_per_px;
    uint16_t out_pi;
    uint8_t byte_idx;
    uint8_t bytes[4];
};

void chan_init(NrzChan& c, const ChannelDesc& d, const uint8_t* pixels, const Timing& t) {
    c.d            = &d;
    c.pixels       = pixels;
    c.mask         = static_cast<uint16_t>(1u << d.bus_bit_data);
    c.t0h          = t.samples_t0h;
    c.t1h          = t.samples_t1h;
    c.bytes_per_px = bytes_per_pixel(d.protocol);
    c.total_bits   = static_cast<uint32_t>(d.pixel_count) * c.bytes_per_px * 8u;
    c.out_pi       = 0;
    c.byte_idx     = 0;
    if (d.pixel_count > 0) detail::transformed_pixel_bytes(d, pixels, 0, c.bytes);
}

// Fill / OR a run of `n` identical samples into the 16-bit DMA buffer. Plain
// sequential 16-bit stores: the buffer is cache-backed PSRAM whose write-back
// already coalesces sequential writes into full cache-line evictions, so wider
// stores don't cut the (eviction-bound) memory traffic — they only add
// alignment-handling overhead, which measured *slower* on the P4.
inline void fill_run(uint16_t* d, uint16_t v, uint16_t n) {
    for (uint16_t k = 0; k < n; ++k)
        d[k] = v;
}

inline void or_run(uint16_t* d, uint16_t v, uint16_t n) {
    if (v == 0) return;
    for (uint16_t k = 0; k < n; ++k)
        d[k] = static_cast<uint16_t>(d[k] | v);
}

// Returns the current transformed byte (MSB is emitted first) and advances the
// cursor a whole byte. The homogeneous sweep gathers all 8 bits of a byte in
// one go, so the pixel-transform / cursor bookkeeping runs once per byte rather
// than once per bit (8× fewer cursor advances on the hot path).
uint8_t chan_next_byte(NrzChan& c) {
    const uint8_t b = c.bytes[c.byte_idx];
    if (++c.byte_idx == c.bytes_per_px) {
        c.byte_idx = 0;
        if (++c.out_pi < c.d->pixel_count) {
            detail::transformed_pixel_bytes(*c.d, c.pixels, c.out_pi, c.bytes);
        }
    }
    return b;
}

// Fast path for a group whose channels all share the same T0H and T1H (any
// single-protocol group — the common 8×WS2815 case). The bus word inside each
// bit is then exactly three constant runs: all active channels high until T0H,
// only the bit-1 channels high until T1H, all low after. This skips the generic
// edge table and its per-bit word masking entirely.
template <bool kStore>
uint32_t sweep_group_homogeneous(NrzChan* ch, size_t n, uint16_t samples_bit, uint16_t* out,
                                 uint32_t max_bits) {
    const uint16_t t0h  = ch[0].t0h;
    const uint16_t t1h  = ch[0].t1h;
    const uint16_t run1 = static_cast<uint16_t>(t1h - t0h);
    const uint16_t run2 = static_cast<uint16_t>(samples_bit - t1h);
    // total_bits is always a whole number of bytes (pixel_count × bpp × 8).
    const uint32_t max_bytes = max_bits >> 3;

    uint32_t next_rebuild_byte = 0;  // byte index at which some channel drops out
    uint16_t all_mask          = 0;
    size_t active_n            = 0;
    uint32_t out_pos           = 0;

    size_t active[kMaxChannels];   // indices of channels still emitting
    uint16_t amask[kMaxChannels];  // their bus masks (cached for the inner loop)
    uint8_t cur[kMaxChannels];     // their current transformed byte
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

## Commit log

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2026-05-29 Implement TODOs 1-10: LCD_CAM instrumentation + OLED driver + UI wiring
    LCD_CAM (items 1-5): runtime instrumentation for hardware validation.
    - kHsyncPulseWidth = 1, documented (item 1)
    - swap latency measurement around draw_bitmap with >200µs warning
    threshold to detect accidental FB copies (item 2)
    - PSRAM size sanity check at init: total, largest free block, against
    2×FB + 256kB headroom; refuse boot on insufficient memory (item 3)
    - register both on_color_trans_done AND on_vsync callbacks; whichever
    fires first releases done_sem; per-callback counters expose which
    path the IDF actually uses (item 4)
    - inter-kick interval tracking with expected vs measured comp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
    [encoder_seesaw.cpp, lcd_cam_output.cpp, main.cpp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]
2026-05-29 Implement TODOs 1-7: seesaw I2C + menu screens + config event group
    Seesaw 4991 driver (items 1-3): real I2C transactions replace the stubs.
    - 2-byte (module, function) addressing with a 250µs split-transaction
    delay between write and read (mandated by the seesaw firmware)
    - encoder_init enables: pin 24 = input + pull-up + GPIO INT, encoder 0 INT
    - seesaw_read_position decodes ENCODER_POSITION as signed BE int32
    - seesaw_read_button reads GPIO_BULK and tests bit 24 (pull-up: pressed=0)
    - encoder_poll drains a delta into RotateLeft/RotateRight events with a
    burst clamp, debounces button via edge detection, and clears the
    seesaw INTFLAG + ENCODER_DELTA so INT_N releases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
    [encoder_seesaw.cpp, main.cpp]
2026-05-29 Implement TODOs 1-7: string/IP editors + ArtPollReply + EMAC bring-up
    UI editors (items 1-2):
    - EditString screen: char-by-char editor for ArtNet short_name (18) and
    long_name (64). Alphabet covers space + A-Z + a-z + 0-9 + - _ . .
    Window of 20 chars centered on cursor with '^' caret. Final position
    (cursor == max_len) shows "[end of string]" + click = commit (trims
    trailing spaces, writes NVS, marks global dirty).
    - EditIp screen: 4-octet editor for static IP / mask / gateway with
    "[xxx]" brackets around the selected octet. Rotate adjusts 0..255,
    click advances; cursor==4 → click commits.
    ArtNet (items 3-4):
    - Item 3: ArtPollReply emission. On ArtPoll receip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
    [main.cpp]
2026-05-29 Implement TODOs 1-4: render pipeline decode + capacity check + WDT + FPS
    Item 1 — decode universes → pixels (dmx_manager::decode_pixels_for_channel):
    - Walks the front universe bank for channel `ch` starting at universe
    cc.universe_start, offset (cc.dmx_start - 1), copying bytes into
    pixel_back_buffer(ch) until pixel_count × bytes_per_pixel are filled.
    - Spans multiple universes if the channel's pixel data straddles
    universe boundaries; handles dmx_start > kUniverseSize correctly.
    - Missing universes → zero-fill remainder + return false (the strip
    stays in a defined state instead of flashing garbage).
    - Per-pixel transforms (color_order, brightness, grouping, i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
    [main.cpp]
2026-05-29 Re-assign board pinout to actually-exposed header GPIOs
    Items 1-2 of the previous list: the user provided the Function EV Board
    header pinout. The previous GPIO assignments were placeholders that
    collided with internal RMII pins (31-35) and pointed at non-exposed
    GPIOs for the encoder INT (was GPIO 9 — not on the header at all).
    LED bus (16 GPIOs, all on the header, all strapping-safe):
    CH1 DATA=2 CLK=3 CH5 DATA=26 CLK=16
    CH2 DATA=4 CLK=5 CH6 DATA=32 CLK=33
    CH3 DATA=22 CLK=23 CH7 DATA=47 CLK=48
    CH4 DATA=24 CLK=25 CH8 DATA=53 CLK=54
    Other re-assignments:
    - Encoder INT : GPIO 21 (was GPIO 9, not on header)
    - Status LED : GPIO 1 (was GPIO 4, now LED C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
    [esp32_p4_devkit.h]
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2026-05-29 Implement TODOs A1-A2 + B3-B4: parser tests, perf test, CI workflow
    A1 — ArtNet parser tests:
    - Extracted pure parsing/building into a header-only
    components/artnet/include/artnet_parser.h:
    parse_header — magic + opcode (LE)
    parse_dmx — universe + data_len + data ptr extraction
    universe_matches — net+subnet filter (masks high bits)
    build_poll_reply — full 239-byte ArtPollReply from inputs struct
    - artnet.cpp refactored to call parser:: from the runtime path —
    production and tests share one code path, no duplicate maintenance.
    - New host test components/artnet/test/test_artnet_parser.cpp:
    header too-short / wrong-magic / valid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
    [artnet_parser.h]
2026-05-29 Implement TODOs A1-A5: HOME badges, NVS recovery, debounce, refresh UI, dynamic period
    A1 — per-channel error badge on HOME:
    Priority order in the channel strip is now ! > * > -:
    ! the channel's t_dma exceeds the refresh period
    (queries dmx::is_channel_capacity_ok)
    * recent ArtDmx within 1s (dmx::is_channel_active)
    - idle
    Users see capacity overflows immediately on HOME instead of having to
    read the boot log.
    A2 — NVS recovery on corruption:
    config_store::init now aggressively retries:
    nvs_flash_init fails (any error) → nvs_flash_erase + reinit
    nvs_open(namespace) fails → erase + reinit + retry once
    If everything still fails, we fal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
    [config_store.h, encoder_seesaw.cpp, main.cpp]
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2026-05-30 boards: replace GPIO16 with GPIO46 for CH5_CLOCK
    GPIO16 is not exposed on the Waveshare DEV-KIT P6 connector, making it
    impossible to route a shield that accesses all 16 bus lines. GPIO46 sits
    at P6 pin 33, immediately adjacent to GPIO26 / CH5_DATA at P6 pin 32,
    giving clean side-by-side DATA+CLOCK routing on the header.
    Also corrects the board-header comment (was referencing the Espressif
    Function EV Board instead of the Waveshare DEV-KIT) and adds the GPIO16
    exclusion note to HARDWARE.md.
    [esp32_p4_devkit.h]
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2026-05-31 boards: fix Ethernet MDC/MDIO/PHY-reset for Waveshare DEV-KIT
    The Ethernet constants in esp32_p4_devkit.h were carried over from the
    Espressif Function EV Board reference and never adapted to the Waveshare
    ESP32-P4 Module DEV-KIT. Verified against the board schematic (PHY U7 =
    IP101GRI) and the official Waveshare pinout:
    - MDC 29 -> 31 (U7 pin 22; GPIO29 is actually RMII RXD0)
    - MDIO 30 -> 52 (U7 pin 23; GPIO30 is actually RMII RXD1)
    - PHY RESET -1 -> 51 (U7 pin 32; drive HIGH to release the PHY)
    GPIO29/30 are the RMII RX data lines, so the old values both missed the
    PHY management bus and collided with RX -- Ethernet (and therefore
    ArtNet, the only network path on this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
    [esp32_p4_devkit.h]
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2026-06-06 Add DMX512 output protocol (one universe per channel)
    Any of the 8 channels can now be configured as a raw DMX512 output instead
    of an LED strip. The channel re-emits one Art-Net universe as a standard
    250 kbit/s 8N2 serial stream (BREAK + MAB + null start code + slots) on its
    DATA bit, reusing the existing Art-Net ingest path.
    - led_protocols: new Protocol::DMX512, is_dmx() helper, bytes_per_pixel()=1,
    and encoder_dmx (BREAK/MAB/8N2 framing at PCLK=16MHz).
    - ui: protocol name + layout-driven channel menu that hides LED-only fields
    (order/brightness/grouping/invert/clock) for DMX and caps slots at 512.
    - docs: PROTOCOLS.md §7 (waveform, data path, RS-485 wiring note) and
    ARCHITECTURE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
    [led_protocols.h]
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2026-06-09 feat(emulator): SDL2 host emulator of the TFT UI
    Run the device's real UI (menu.cpp, canvas_tft.cpp, splash.cpp, font_5x8.cpp)
    on a PC against an SDL2 framebuffer instead of the ST7789 TFT — preview the
    interface before flashing, and drive it from an AI agent.
    The UI only touches hardware through tft_draw_bitmap(); the emulator
    reimplements that one seam over an in-RAM RGB565 framebuffer (tft_sdl.cpp),
    replaces the I2C seesaw encoder with a host event queue (encoder_host.cpp),
    and stubs config_store/dmx_manager/lcd_cam_output in RAM with the device
    defaults. Standalone CMake build, no IDF.
    Control: keyboard in the SDL window, or a stdin line protocol
    (left|right|click|shot <p>|state|set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
    [encoder_host.cpp, main_emulator.cpp]
2026-06-09 feat(ui): restyle TFT UI, add per-channel Off, sharpen font (#13)
    * feat(ui): animated frog boot splash baked from the web logo
    Replace the hand-coded wave splash with the Collecti'Frog logo animation
    from the About page: the frog surfaces from the water, the bands settle and
    the eyes blink.
    Single source of truth is docs/img/frog-anim.svg — a self-contained animated
    SVG. The web About page embeds it via <img> (animation CSS moved into the SVG,
    about.html slimmed accordingly), and the new host tool tools/splashgen replays
    its timeline at gen-time (vendored nanosvg), baking 1bpp frame masks into
    components/ui/src/splash_anim.cpp. splash.cpp blits frame t with
    canvas_draw_mask over the dar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
    [artnet_parser.h, encoder_host.cpp, lcd_cam_output.cpp]
2026-06-09 fix(ui): OLED cold-boot, reboot loop, encoder polling; add NeoPixel feedback
    Hardware bring-up of the SSD1306 + seesaw 4991 board, found while flashing to
    real hardware:
    - oled_ssd1306: probe-retry on a cold I2C bus before the init sequence. The
    first transaction after bus creation NACKs and the panel charge pump needs
    settling, so OLED init failed on the very first boot.
    - dmx_manager: handle_pending_remaps() cleared 0xFFFFFFFF on the remap event
    group; the reserved top byte (0xFF000000) trips a FreeRTOS assert -> reboot
    loop once a remap is pending. Clear only the used bits (channels + global).
    - ui: poll the encoder on a timer (~30 Hz) instead of gating on the seesaw
    INT_N ISR,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
    [encoder_seesaw.cpp, ui.cpp]
2026-06-10 perf(led): single-pass frame encoder + right-sized DMA frames for 60 FPS
    The render pipeline was capped at ~6 FPS with all channels off:
    - The RGB panel h_res was fixed to the absolute worst case
    (1024 px RGBW WS2811-slow = 1.3 M samples), so every frame emitted
    82 ms of DMA regardless of content (12 FPS hard ceiling).
    - render_frame serialized everything: wait for previous DMA, then
    memset 2.6 MB of PSRAM, then 8 read-modify-write encode passes over
    the whole frame region, then msync 2.6 MB — ~160 ms per frame.
    Changes:
    - led_protocols: new encode_frame() merges all NRZ channels into one
    pure-store traversal (bit-synchronous sweep per samples_bit group,
    word updates only at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
    [encoder_frame.cpp, encoder_nrz.h, lcd_cam_output.cpp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]
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2026-06-10 fix(ci): add gpio.h include, snprintf for strncpy, clang-format alignment
    - lcd_cam_output: add #include "driver/gpio.h" for GPIO_NUM_NC / gpio_num_t
    - menu.cpp: snprintf replaces strncpy+memset to silence -Werror=stringop-truncation (GCC 14)
    - test_led_protocols: extract co_count temp to fix clang-format 16/18 divergence
    [lcd_cam_output.cpp]
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2026-06-10 fix(lcd_cam): make the LCD_CAM output actually emit — refresh kick, multi-line frames, PSRAM 80M, vsync pacing
    Four stacked bugs left the LED outputs silent; all root-caused on a Saleae
    and validated bit-exact (WS2815 T0H=312.5ns/T1H=937.5ns, 62 fps, vsync ==
    frames_emitted, 0 underruns):
    - refresh_on_demand requires an explicit esp_lcd_rgb_panel_refresh() after
    draw_bitmap (which only swaps the FB pointer). on_color_trans_done fires
    synchronously inside draw_bitmap and is NOT an emission signal.
    - The P4 ha_width/ht_width timing fields are 12-bit (va/vt 10-bit) and the
    HAL truncates silently, so the 1-line frame model (h_res = 164800) never
    could work. Frames are now v_res lines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
    [lcd_cam_output.cpp]
2026-06-10 fix(led_protocols): brightness 255 is now an exact identity
    The gain was (c*b+128)>>8, i.e. /256 with bias: at brightness 255 a 0xff
    component emitted as 0xfe (measured on the wire — full white was
    unreachable). (c*(b+1))>>8 keeps 255 an identity and stays within 1 LSB
    of exact c*b/255. Host suite green (encoders compared pairwise).
    Also documents in the uartctl skill that pixr lags dmxw by one render
    tick (the decode runs in render_task) — the "data=000000 right after
    inject" confusion was sampling, not a pipeline bug.
    [encoder_nrz.h]
2026-06-10 feat(led-output): PARLIO TX backend — DMA loop transmission, no line-geometry limits
    Alternative to the LCD_CAM RGB backend, selected with
    CONFIG_PIXFROG_LED_OUTPUT_PARLIO (sdkconfig.parlio overlay, build.parlio).
    Same pixfrog::lcd:: interface; shared helpers extracted to output_common.h.
    The PARLIO TX unit is a plain 16-bit bus fed by DMA: no 12-bit h_res
    registers, no inter-line blanks. In loop transmission mode the frame is a
    flat PSRAM buffer the hardware repeats back-to-back (the encoded reset tail
    separates repeats); a transmit() during the loop re-mounts the second DMA
    link list and concatenates it at the running frame's boundary — gapless
    double-buffer swap by construction. Cloc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
    [lcd_cam_output.cpp, output_common.h, parlio_output.cpp]
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2026-06-11 feat(led-output): PARLIO TX is the default backend
    The default sdkconfig now selects CONFIG_PIXFROG_LED_OUTPUT_PARLIO (also
    the Kconfig choice default, stated explicitly in sdkconfig.defaults). The
    LCD_CAM backend stays buildable through the sdkconfig.ci.lcdcam overlay,
    which replaces sdkconfig.parlio in the CI matrix (variant `lcdcam`),
    ci-local and the build skill.
    [parlio_output.cpp]
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2026-06-11 feat(web-config): optional HTTP server with embedded SPA + REST API
    Adds a new web_config component that starts an HTTP server on port 80
    when GlobalConfig::web_enabled is true (off by default — no socket opened
    until the user opts in). Controlled from the Network submenu on the OLED/TFT
    UI, via `global web_enabled 0|1` in the UART console, or POST /api/global.
    REST endpoints: GET / (SPA), GET /api/config, POST /api/global,
    POST /api/channel/{0..7}, POST /api/reboot, POST /api/factory-reset.
    The SPA covers all 8 channels and all GlobalConfig fields.
    GlobalConfig::web_enabled is appended at the end of the struct; the NVS
    migration in config_store zero-fills the new tail on first boot afte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
    [config_store.h, main.cpp]
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2026-06-11 feat(ui): version display, long-press commit, rotation acceleration, pixel-count strip preview
    Five UX improvements:
    * Firmware version from `git describe --tags` (exact tag, or tag+N+hash when
    past it) via PROJECT_VER at CMake configure time. Shown on both splash
    screens, in a new About entry in the main menu, and in the web UI header
    (/api/config gains a "version" field). CI checkout fetches tags.
    * Edit screens no longer show input hints (rotate=…/click=…); state
    indicators ([end of string], [ready to commit], was:) are kept.
    * Long press (600 ms) commits instantly and climbs one level: in any edit
    screen the current state is committed as-is (string edits keep all
    remai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
    [dmx_logic.h, encoder_host.cpp, encoder_seesaw.cpp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]
2026-06-11 fix(ui): long-press threshold 600 ms → 1 s
    Behaviour unchanged otherwise: the action fires while held at the
    threshold (not on release), once per hold; release re-arms.
    [encoder_seesaw.cpp]
2026-06-11 fix(power): program LDO VO4 to 3.3V — VDD_IO_5 pads (GPIO39-48) were at 1.2V
    On the Waveshare ESP32-P4 module the VDD_IO_5 pad domain is wired to the
    chip's internal LDO output VO4, not to 3.3V (same wiring as the public
    ESP32-P4-NANO schematic; the module exposes the ESP_LDO_VO4 net on pin 66).
    Unprogrammed, VO4 idles near 1.2V, so LED bus CH5 CLOCK (GPIO46) and CH7
    DATA/CLOCK (GPIO47/48) swung 0-1.2V — measured 1.17V high on GPIO47 with a
    Logic Pro 8 analog capture of calibration pattern 0.
    Acquire LDO channel 4 at 3300mV first thing in app_main and never release
    it. Post-fix capture: GPIO47 high level 3.37V, all 8 data lines at 3.3V.
    VDD_IO_6 (GPIO49-54, CH8) is tied to 3.3V on the m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
    [esp32_p4_devkit.h, main.cpp]
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2026-06-11 chore: tech debt — emulator in CI, encoder INT_N path removed
    Emulator in CI: new ci.yml job (SDL2 build + tools/emulator/smoke.sh) and
    a [3/4] step in ci-local.sh. The headless smoke test drives the menu FSM
    through the stdin agent protocol: navigation, About, an EditValue commit
    via long-press, long-press-as-Back. The emulator already broke silently
    once (#21) — it now gates pushes.
    Encoder INT_N removed: ui_task already loops at ~30 Hz for the encoder-LED
    animation and the diff-based display refresh, so the interrupt bought at
    most one tick (~33 ms) of input latency — imperceptible on a rotary
    detent — and cost two extra I2C latch-clear reads (GPIO_INTFLAG +
    ENCODER_DELTA) per po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
    [encoder_host.cpp, encoder_seesaw.cpp, esp32_p4_devkit.h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]
2026-06-11 feat(ota): firmware update over the web UI — A/B partitions + rollback
    POST /api/ota streams a raw .bin into the inactive OTA slot (4 kB chunks,
    esp_ota_end image validation), switches the boot partition and restarts.
    The SPA Global tab gains a Firmware card: running version + slot, file
    picker, upload progress bar.
    Partition table goes single-factory → A/B: ota_0/ota_1 (7 MB each) +
    otadata. nvs/phy_init keep their previous offsets so the one-time USB
    reflash preserves the existing configuration.
    Safety: BOOTLOADER_APP_ROLLBACK_ENABLE — a freshly flashed image boots
    PENDING_VERIFY and app_main confirms it only at boot-complete, so an OTA
    image that crashes during bring-up rolls back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
    [partitions.csv]
2026-06-11 feat(web): HTTP Basic auth on mutating endpoints — off by default
    Every POST (/api/global, /api/channel/*, /api/ota, /api/reboot,
    /api/factory-reset) now passes a Basic-auth gate; GET / and /api/config
    stay open for read-only monitoring. No password set (the default) = no
    auth, so first-boot UX and existing scripts are unchanged.
    Password storage: salted SHA-256 in GlobalConfig (8-byte random salt via
    esp_fill_random; all-zero hash = disabled — NVS tail migration lands as
    "auth off"). Verification is constant-time; every failure costs a flat
    500 ms, which makes LAN brute force impractical without lockout state.
    Setting / clearing: SPA "Admin password" card, POST /api/global
    {"web_passw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
    [config_store.h]
2026-06-11 feat(failsafe): per-channel signal-loss failsafe — hold/blackout/solid colour
    When a channel receives no packet for failsafe_timeout_s (global setting,
    0 = disabled), the render path stops decoding its stale universes and
    emits the configured fallback instead:
    - hold (default; zero-fill migration lands here) — today's behaviour,
    the last frame stays
    - blackout — pixels cleared
    - solid colour — configurable RGB fill (service amber, dim white...);
    W stays off on RGBW strips; DMX512 channels degrade to blackout
    Trigger rules: per channel from its existing activity timestamp; a channel
    that was never driven since boot stays dark (no fallback scene on a
    not-yet-commissioned install)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
    [config_store.h, dmx_logic.h]
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2026-06-11 feat(scenes): standalone parametric scenes — solid/chase/rainbow
    8 scene slots persisted as one NVS blob: {name, per-channel mask, effect,
    RGB, speed, param}. Generators are pure code in dmx_logic.h (integer HSV
    wheel, wall-clock phase so animation speed is refresh-rate independent),
    rendered in decode_pixels_for_channel with priority preview > scene >
    failsafe > network decode. A playing scene overrides incoming traffic on
    its masked channels until explicitly stopped (manual-stop policy); DMX512
    channels never render scenes. Storage is NVS rather than a LittleFS
    partition on purpose: 192 bytes don't justify a partition-table change,
    which cannot be applied over OTA.
    Triggers, all wired: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
    [config_store.h, dmx_logic.h]
2026-06-11 feat: config backup/restore, channel identify, per-channel gamma + white balance
    Three TODO items in one coherent pass:
    Backup/restore — GET /api/backup downloads {global, channels, scenes} as
    JSON (Content-Disposition attachment; the password hash is never
    exported). POST /api/restore applies it best-effort: unknown or invalid
    fields are skipped so backups from different firmware degrade gracefully.
    The /api/config builders were factored (build_global/channels/scenes_json)
    and shared by both endpoints. Web UI gains a Backup card (download +
    file-picker restore).
    Channel identify — 2 Hz full-white blink on a single strip, auto-expiring
    (default 10 s), top render priority so it answers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
    [config_store.h, encoder_nrz.h]
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2026-06-11 feat: 2-source merge (HTP/LTP) for ArtNet + sACN
    Shared merge engine in dmx_manager (merge_ingest in dmx_logic.h,
    host-tested): up to 2 sources per universe keyed by sender IP (ArtDmx)
    or CID hash (sACN), per-source staging frames in PSRAM, HTP = per-slot
    max, LTP = last frame wins. A source silent past 10 s (Art-Net) /
    2.5 s (E1.31) is dropped; a third concurrent sender is ignored.
    Merge mode is node-wide (GlobalConfig::merge_mode, default HTP,
    zero-fill NVS migration), set via ArtAddress AcMergeLtp*/AcMergeHtp*/
    AcCancelMerge, UART 'global merge_mode HTP|LTP', or the web API.
    Reported in ArtPollReply GoodOutputA (bit 3 merging, bit 1 LTP) and
    'chstat merge='. sACN priority takeover resets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
    [artnet_parser.h, config_store.h, dmx_logic.h]
2026-06-12 feat: FSEQ v2 player from microSD (SDMMC GPIO39-44, zstd, FAT)
    New fseq_player component reads .fseq v2 files from a microSD card
    mounted via SDMMC 4-bit on GPIO39-44 (LDO VO4 domain already enabled).
    Frames are decoded (none/zstd/lz4 compression, linear and sparse layouts)
    and injected into the DMX manager's universe banks; a g_fseq_active flag
    suppresses the failsafe path while playback is running.
    Includes:
    - fseq_format.h: pure header-only FSEQ v2 parser (host-testable, no IDF)
    - fseq_player.cpp: SDMMC init, FAT mount, PSRAM-buffered playback task
    - zstddeclib.c: zstd 1.5.7 single-file decoder (third-party, C99)
    - 38-test host suite (test_fseq_parser) with fixture generator
    - fseq_host.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
    [esp32_p4_devkit.h, fseq_player.cpp, main.cpp]
2026-06-12 fix: CI failures — drop esp_log dep + clang-format
    fseq_player/CMakeLists.txt: remove `esp_log` from REQUIRES — the IDF
    CMake component name for esp_log.h is `log`, but it is a default
    dependency and does not need to be listed explicitly. The unknown-name
    error caused both IDF build variants to fail at CMake configure.
    test_fseq_parser.cpp + fseq_host.cpp: fix clang-format violations
    (column-aligned spaces in function params and struct member init).
    https://claude.ai/code/session_01RyPUh2oYTBxkAeKU9boreF
    [fseq_player.cpp]
2026-06-12 feat(fseq): SD card hot-plug support with 1 s monitor task
    State machine: SdState { Absent, Mounted } (atomic, visible to all tasks).
    sd_monitor_task (prio 2, core 0):
    - Absent → tries esp_vfs_fat_sdmmc_mount every second until it succeeds
    - Mounted → probes sdmmc_get_status() every second; on failure calls
    do_unmount() which stops playback, unmounts FAT, transitions to Absent
    Other changes:
    - init() stores InitConfig, starts monitor task, attempts immediate mount
    (always returns true unless task creation fails — no card at boot is fine)
    - start() now guards on SdState::Absent and returns "No SD card" error
    - stop_task() private helper shared by public stop() and do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
    [fseq_player.cpp]
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
